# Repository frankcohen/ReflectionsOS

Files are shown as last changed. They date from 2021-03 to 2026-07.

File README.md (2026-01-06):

# ReflectionsOS
ESP32 and Arduino-based Internet-enabled watch project and reference architecture to make your own entertaining experiences. [See the software repository](https://github.com/frankcohen/ReflectionsOS/blob/main/src/SRC_readme.md).

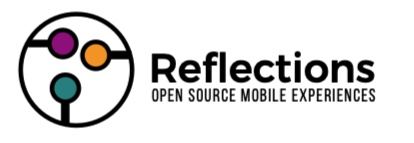
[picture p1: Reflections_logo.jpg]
Reflections Mobile Experiences


Many times I imagine making a mobile application connected to the Internet. For example, a watch that shows videos of my children growing-up on my wrist. And the same project is re-used for creative makers to build their own entertaining experiences. Reflections is the architecture and the wrist watch is the first application.

Reflections integrates video displays, Bluetooth, Wifi, SD flash storage, sound, and a bunch of sensors (compass/magnetometer, gestures, accelerometer, time of flight TOF sensor). It is battery powered, powered managed from software, and charges from USB. It is small in size (34 mm round) and powerful from an ESP32-S3 dual core processor. Reflections software, hardware, and cloud components are open-source (GPL v3) so anyone can use it and they must contribute improvements back to the project.

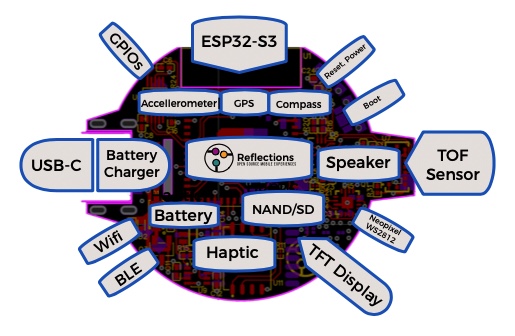
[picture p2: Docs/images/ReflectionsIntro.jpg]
Reflections Mobile Experiences


Reflections goes beyond the wearable device to deliver server side architecture.

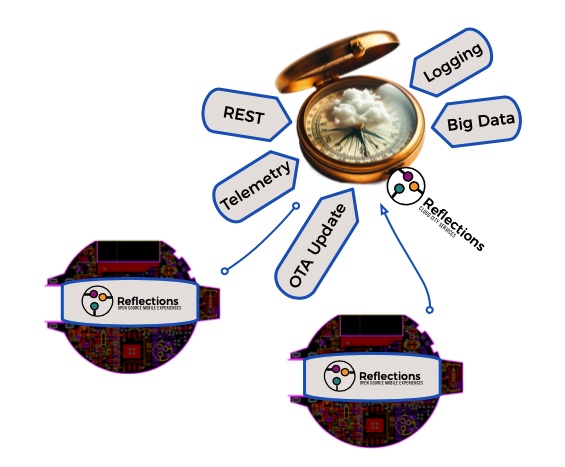
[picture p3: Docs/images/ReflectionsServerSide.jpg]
Reflections Server Side Architecture


I worked on [Starling Watch](http://starlingwatch.com) steampunk art jewelry pocket watches with Disney Imagineer and Muppeteer [Terri Hardin](https://terrihardin.com/). In November 2025 we announced the first commercial product based on Reflections. It's Terri Hardin's Cheshire Cat. Details and purchase at [StarlingWatch.com](https://starlingwatch.com/).

Announcement video (https://www.youtube.com/watch?v=qcqhzyMLibs)

I love working with a group of creative makers and the Arduino community. Please feel free to let me know your feedback and ideas.

IMAGE ALT TEXT HERE (https://www.youtube.com/watch?v=HIWHx4NLKUU)

[JoJo](https://github.com/frankcohen/ReflectionsOS/blob/main/Devices/JoJo/JoJo%20Project%20Notes.md) is the latest version of the Reflections main board. Everything fits into a wrist watch case and I actually wear it on my wrist! Plus the [software]() to drive experiences (codename ReflectionsOS) is coming along nicely. See https://github.com/frankcohen/ReflectionsOS/tree/main/Experiments for experiments with the board.

VladPlus Gerber files and schematic are at:
[https://github.com/frankcohen/ReflectionsOS/blob/main/Devices/VladPlus/VladPlus%20Project%20Notes.md](https://github.com/frankcohen/ReflectionsOS/blob/main/Devices/VladPlus/VladPlus%20Project%20Notes.md)

Frank Cohen, [https://github.com/frankcohen/ReflectionsOS](https://github.com/frankcohen/ReflectionsOS), November 9, 2024

## Articles

I publish articles on the technology needed to make Reflections.

[AccelerometerLab open-source project for LIS3DH 3 Axis accelerometer sensor](https://github.com/frankcohen/ReflectionsOS/tree/main/Experiments/AccelerometerLab)

[ESP32-S3 partition tables and optimizing memory for Arduino IDE 2.x](https://github.com/frankcohen/ReflectionsOS/blob/main/Docs/Partition%20tables%20and%20optimizing%20memory%20in%20Arduino%20IDE.md)

[Deep Sleep, Extending Battery Life for ESP32-S3 Projects](https://github.com/frankcohen/ReflectionsOS/tree/main/Experiments/Deep%20Sleep)

[Wrist Gesture Sensing on ESP32 and Accelerometer](https://github.com/frankcohen/ReflectionsOS/blob/main/Experiments/Gesture_Sensing_Accelerometer/Gesture_Sensing_Experiment.md)

[Scalable Logger on ESP32 with Wifi and SD/NAND](https://github.com/frankcohen/ReflectionsOS/blob/main/Docs/Scalable%20logger.md)

[Arduino and BLE on ESP32 as server and client combined, using NimBLE](https://github.com/frankcohen/ReflectionsOS/blob/main/Docs/Why%20I%20like%20NimBLE%20for%20Bluetooth%20BLE.md)

[JCUSB for JTAG debugging in Arduino IDE 2.1](https://github.com/frankcohen/ReflectionsOS/blob/main/Docs/JCUSB%20using%20JTAG%2C%20CDC%2C%20USB%20for%20debugging.md)

[ESP32-S3 + NAND SD Storage + USB MSCC = Arduino that shows up like a disk drive](https://github.com/frankcohen/ReflectionsOS/blob/main/Docs/Arduino%20that%20shows%20up%20like%20a%20disk%20drive%20_%20arduino.pdf)

[JSON Procedural Scripting using ArduinoJSON and ESP32](https://github.com/frankcohen/ReflectionsOS/blob/main/Docs/JSON%20Procedural%20Scripting%20using%20ArduinoJSON%20and%20ESP32.pdf)

[Managing SSL Certificates for HTTPS with IoT devices, ESP32-nginx+node.js+OTA](https://github.com/frankcohen/ReflectionsOS/blob/main/Docs/Managing%20SSL%20certificates%20for%20HTTPS%20with%20IoT%20devices_%20ESP32%2BNginx%2BNode.js%2BOTA%20_%20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)

[Reference to Mastering ArduinoJSON](https://github.com/frankcohen/ReflectionsOS/blob/main/Docs/Mastering%20ArduinoJSON.pdf)

[Create Using TAR files in ESP32 with SD applications for easy multiple file transfers to Arduino](https://github.com/frankcohen/ReflectionsOS/blob/main/Docs/Using%20TAR%20files%20in%20ESP32%20with%20SD%20applications%20for%20easy%20multiple%20file%20transfers%20_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)

I used the [EleksTube IPS clock](https://elekstube.com/) for experimentation. It is an ESP32 device featuring 6 TFT displays. See [https://github.com/frankcohen/EleksTubeIPSHack](https://github.com/frankcohen/EleksTubeIPSHack)

I made an air-guitar project to learn about streaming music over Bluetooth Clasic, and why it won't work yet on BLE: [https://github.com/frankcohen/ReflectionsOS/tree/main/Experiments/AirGuitar](https://github.com/frankcohen/ReflectionsOS/tree/main/Experiments/AirGuitar)

-Frank

## Update as of June 16, 2025

Nearing the end of coding. The Time of Flight (TOF) sensor and LIS3DH accelerometer sensor code is complete and integrated into the code. Next steps are optimizations to extend battery life, use deep sleep, BLE capabilities, and GPS capabilities.

## Update as of January 18, 2025

I published AccelerometerLab as an open-source project to make working with the LIS3DH 3 Axis accelerometer sensor easier. [The code and article are here.](https://github.com/frankcohen/ReflectionsOS/tree/main/Experiments/AccelerometerLab)

Next up is code to detect gestures with the Time Of Flight (TOF) sensor. This should be fun as it includes machine learning.

## Update as October 29, 2024

I made a fun Magic 8 Ball experience for the Maker Faire Bay Area. It was October 18 to 20, 2024 on Mar Island in the California Bay area and 25,000 people attended.

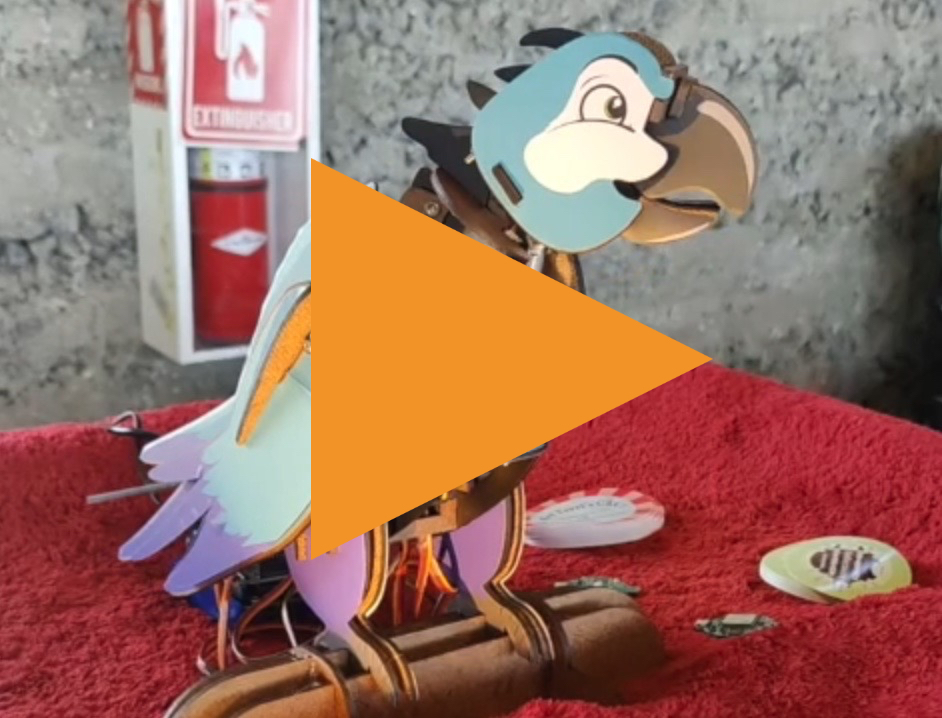
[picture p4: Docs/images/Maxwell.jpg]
Reflections controls Maxwell animatronic at Maker Faire 2024 (https://youtu.be/2h5V32wpsNU)


For Maker Faire I had a Reflections board connect and control Maxwell wirelessly. Ask a question, shake the board and the display shows an answer. Maxwell animates the answer to yes, no, and maybe movements.

Source code for this fun project is in the [/src/MakerFaire2024Maxwell](https://github.com/frankcohen/ReflectionsOS/tree/main/src/MakerFaire2024Maxwell) directory

## Update as of June 18, 2024

We've gotten to a point in the development of the software for the board where we wanted to optimize the board's use of the battery. The battery runs for a few hours now. Using the [Deep Sleep](https://github.com/frankcohen/ReflectionsOS/tree/main/Experiments/Deep%20Sleep) technique for the processor, we're able to make that battery last a whole lot longer. When I tell it to start up, it goes through a cold boot and then it puts the processor to sleep, the processor is now drawing extremely low energy and the display is turned off. It's extending the battery life as well. All I have to do then is to move the, the the board just a little bit and you can see that it comes awake. The accelerometer sensor on the board is sending a interrupt to the processor saying, hey, it's time to wake up the processor, then turns on the display displays this greeting message and then also an indication of how many times through this iteration loop we've gone. And then it sends the processor back into sleep until I shake it again or tap it or click it and then it turns on. So by doing this, we'll be able to get the battery life much longer than we had before we did this. And it's a nice software technique that seems to be useful for a bunch of different applications.

Deep Sleep use of GPIO 13 and LIS3DH INT 2 pins is in the [Vlad version of the logic board](https://github.com/frankcohen/ReflectionsOS/blob/main/Devices/Vlad/Vlad%20Project%20Notes.md) and later.

## Update as of March 19, 2024

Software work achieves success along the way to the ReflectionsOS operating environment. A gesture experiement using the accelerometer works. Watch a 5 minute briefing here:

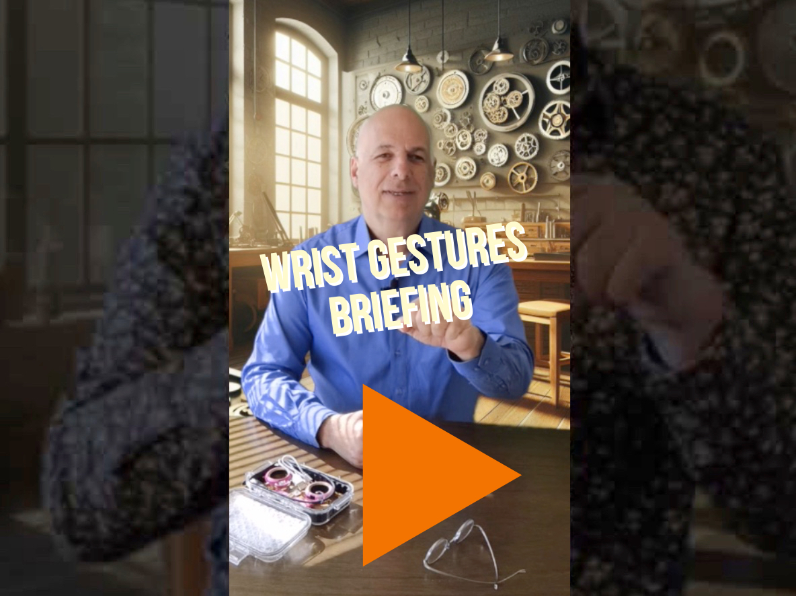
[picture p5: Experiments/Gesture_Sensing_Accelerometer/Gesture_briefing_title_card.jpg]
5 minute video briefing on Wrist Gesture Sensing (https://youtu.be/nNwV_FyjRPc)


[Yertle](https://github.com/frankcohen/ReflectionsOS/blob/main/Devices/Yertle/Yertle%20Project%20Notes.md) arrived and looks fully functional.

## Update as of February 14, 2024

Cat In Hat turned out to be a fools errand, the ESP32-S3 would not boot with the addition of the press-and-hold power on/off capability using U9. Yertle solves this by removing U9. Work on the software continues, should have a simple video player using wrist gestures done soon. Work on the case and strap is in progress. I am only wearing Yertle everyday now, no more traditional watches.

## Update as of December 7, 2023

Work on the [Cat In Hat](https://github.com/frankcohen/ReflectionsOS/tree/main/Devices/CatInHat) main board is nearly complete. This solves a consistency problem with the NAND. And, adds press-and-hold power on/off capability to the Boot button. I depart tomorrow to China to find components and manufacturers for the case and strap. 

## Update as of October 6, 2023

Added Wifi-based [Logger](https://github.com/frankcohen/ReflectionsOS/blob/main/Docs/Scalable%20logger.md). Logs messages to server-side logger. Update board (codenamed Red Fish) to solve U4 LDO problem when battery is attached. Investigated active GPS antennas.

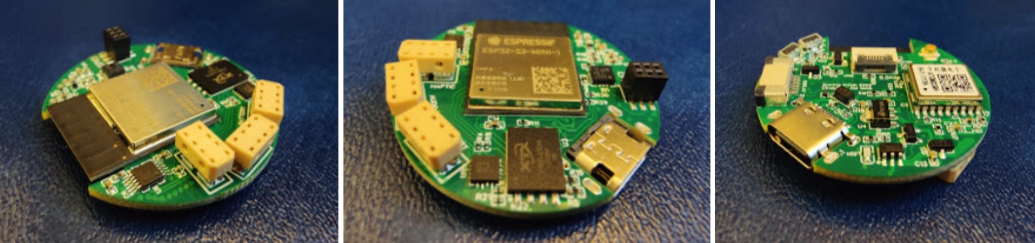
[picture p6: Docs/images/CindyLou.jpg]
Cindy Lou board


## Update as of August 6, 2023

Added Over The Air (OTA) update capabilitiy. Server downloads .bin firmware and a version identifier text file over HTTPS secure protocol. OTA system replaces the current firmware and restarts the host. Thanks to @lipun12ka4 on [Espressif Forums](https://esp32.com/posting.php?f=13&mode=reply&t=30973&sid=89252e0558c707c8813146f40cccf9fc) for sharing his OTA code, a problem, and solution. config.h defines the code's version number, it is a simple integer value. Arduino IDE compiles the firmware. Use FTP to store it in /home/fcohen/files on cloudcity.starlingwatch.com.

## Update as of August 5, 2023

Added [WifiManager](https://github.com/tzapu/WiFiManager) to enable easy connection to a Wifi network. Connect to Reflections board from your laptop or mobile device. The SSID is named CALLIOPE plus the last digits of the device mac address. For example, CALLIOPE-7A. Follow the instructions to log Reflections into your Wifi network. Passwords are sent to the device in the clear, and optionally stored on the device with no encryption. Someone could extract these if they got their hands on your device.

## Update as of August 4, 2023

@dankeboy36 (on Github) published an Arduino stack trace decoding utility. When your sketch crashes a stack trace leading to the crash often appears in the Serial Monitor. Arduino IDE 2.1 does not yet support plug-ins and a decoder utility (available in Arduino IDE 1.8) is needed to explain the stack trace contents. @dankeboy36 created a decoder and it works great. It requires the nightly Arduino IDE build available at https://www.arduino.cc/en/software. The decoder is at at:
https://github.com/dankeboy36/esp-exception-decoder. On a Mac use Command-Shift-P and type ESP Exception Decoder: Show Decoder Terminal.

## Update as of July 18, 2023

A friend asked me: What can the Reflections board do? Consider these possibilities.

- Haptic feedback - a buzzer in the case. Buzzes softly or energetically. Fades the buzzing up, or down, and make patterns. It even does morse code - buzz buzz buzz.

- Long arm movement sensing - Recognizes the direction, speed, and acceleration of your wrist. Recognizes gestures made by moving your wrist in the air. Like sweeping left and right, slow pitching a ball.

- Finger movement sensing - recognizes gestures made with fingers.

- Range, Distance, Heading - when GPS is available, knows its position and direction/heading to other boards. When GPS is not available, such as being indoors, uses a compass and triangulation to detect movement towards or away from other boards using BLE.

- Compass - knows North from South and between.

- Location - when GPS is available, knows when it is in a location. For example, knows when it is at Disneyland and in line for the Matterhorn.

- Bump - touch another board and exchange data.

- USB flash memory - plug into your mobile phone or laptop to store and move files.

- Grab and play - capture video and audio of anything playing on your laptop, displays on the screen.

- [Martians](https://github.com/frankcohen/Martians) - yearn for each other, their hearts point to each other.

- Speaker to play sound and music. However, the speaker volume is very low. A future version needs an audio amplifier.

- Dance movements like pirouette

- Red light green light

- Head and shoulders, knees and toes

I'm glad to update this list with your ideas. Thanks.

## Update as of June 26, 2023:

CindyLou is the latest version of the main board. CindyLou lets me put everything into a wrist watch case and actually wear it on my wrist! Plus the software to drive experiences (codename CalliopeOpensEyes) is coming along nicely. See https://github.com/frankcohen/ReflectionsOS/tree/main/Experiments for experiments with the main board.

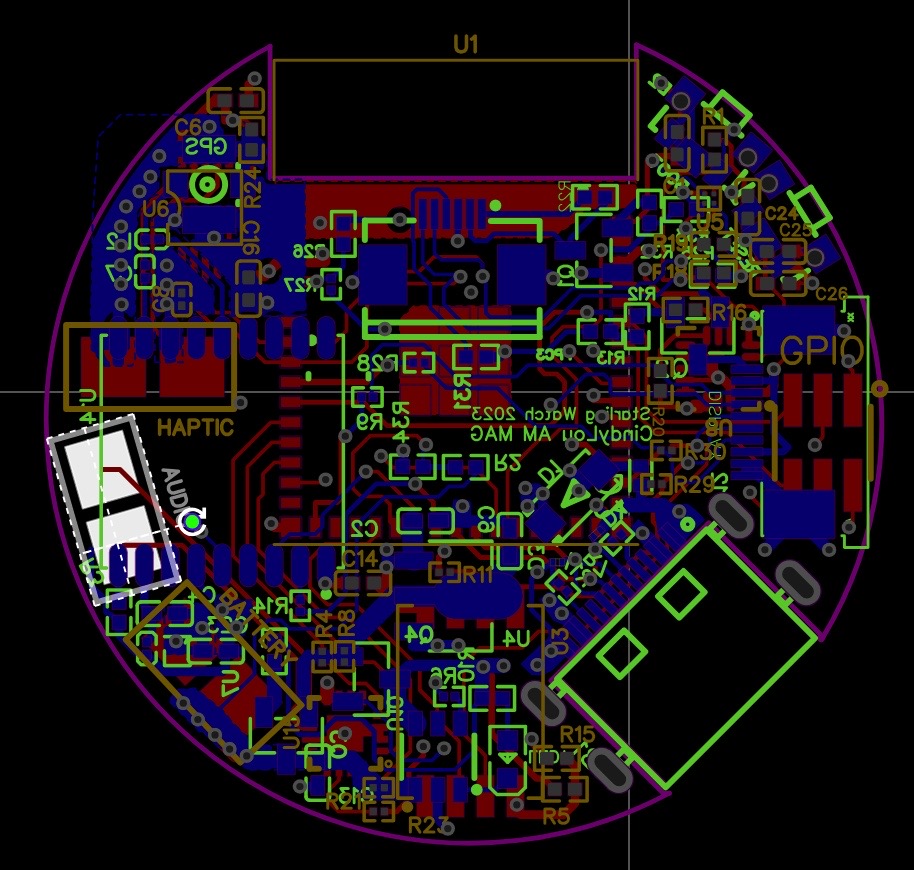
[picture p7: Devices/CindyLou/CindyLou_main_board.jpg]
CindyLou version of the main board CindyLou main board


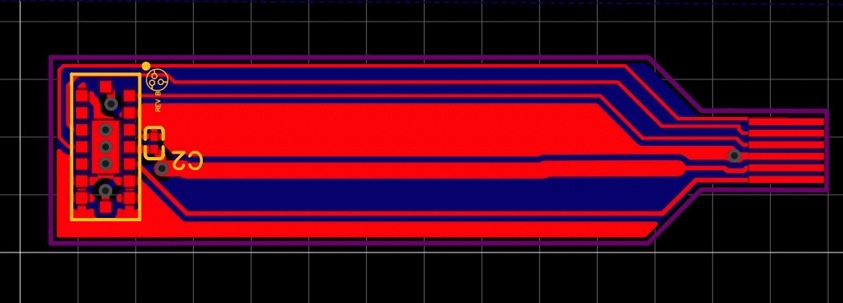
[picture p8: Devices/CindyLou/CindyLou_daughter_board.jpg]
Daughterboard for gesture sensing CindyLou daughter board


CindyLou Gerber files and schematic are at:
https://github.com/frankcohen/ReflectionsOS/tree/main/Devices/CindyLou
EasyEDA project for the previous main board project is at:
https://oshwlab.com/fcohen/horton-main-board

## Update as of April 1, 2023:

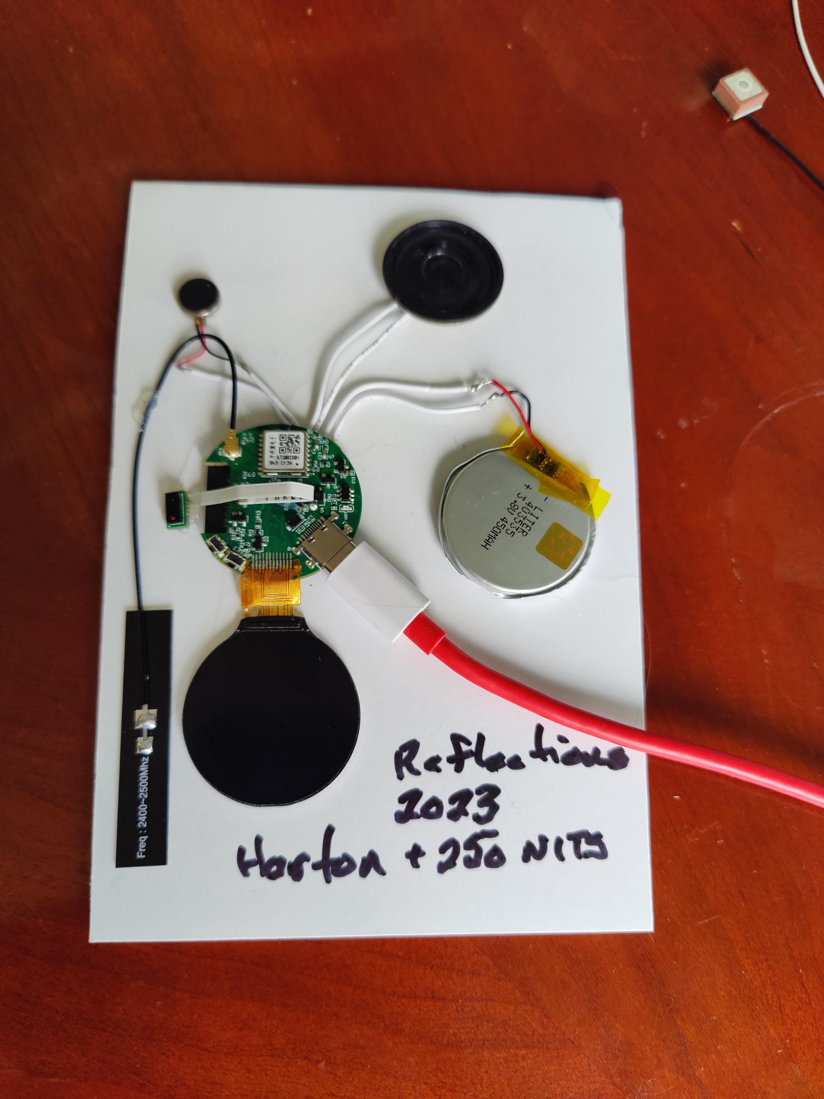
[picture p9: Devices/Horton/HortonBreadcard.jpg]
I call this a Breadcard, it's not a breadboard but getting close to a wearable prototype, codenamed Horton Horton Breadcard


Update as of March 16, 2023:

Horton board is in from assembly and it works great! Next up, our first wearable prototype.
Expect many updates to the source code repository over the coming weeks and months.

## Update as of January 25, 2023:

All of the main board components are working. One more revision of the board is needed to incorporate the reworks we made to the ThingTwo board. We're calling the new revision Horton. It should be complete and go to manufacture and assembly in early February 2023.

The project team attention next goes to producing the first wearable prototype. This will strap to one's wrist, run on battery, and have a prototype display. We are also considering our first crowd funding campaign featuring the prototype. This is leading to an exciting Spring 2023.

## Update as of July 30, 2022:

We're making great progress on the main board, animation, and software projects. Main board revision 2 - codenamed Hoober - works and displays streaming video at 10 Frames Per Second (FPS). Revision 3 - codenamed ThingTwo - is designed and will go to manufacturing and assembly next week. See Devices/ThingTwo for design document, Gerber files, BOM, and wiring guide. Project focus will move to the software projects.

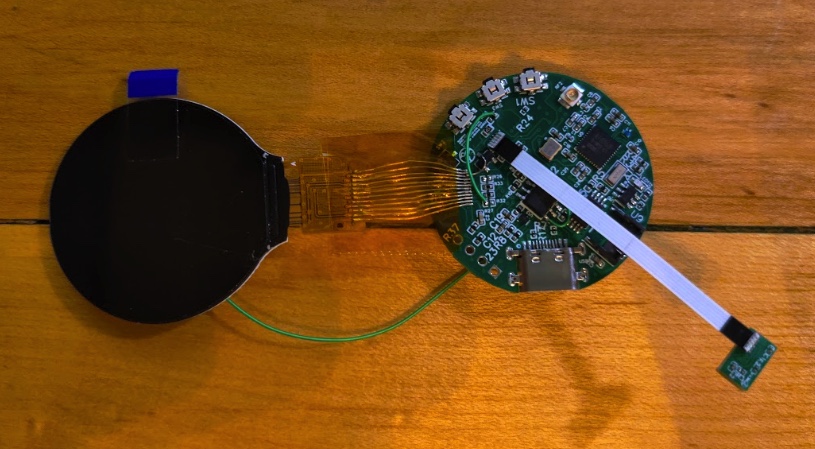
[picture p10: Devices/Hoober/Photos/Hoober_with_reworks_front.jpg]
Photo of the front side of the main board, codenamed Sox Main board front side


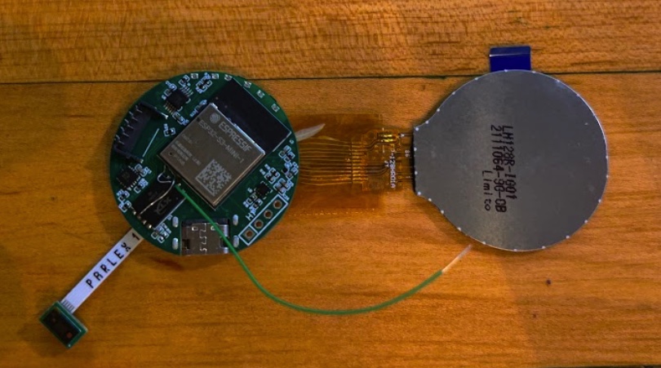
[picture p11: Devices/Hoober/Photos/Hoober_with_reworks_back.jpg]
Photo of the back side of the main board, codenamed Sox Main board back side


## Update as of April 27, 2022:

The project team is making progress on the main board and display. We received the first assembled main board in hand. It’s an ESP32 with GPS, IMU/compass, NAND memory, TFT display, audio output, USB, battery management, and finger gesture sensor, in a 34 mm round board. Cost for the prototype is $70 per board. This first version has about 3-4 problems that need reworking. The team is feeling good that the number of problems is less than 10. That puts us on track to have the finished board in Summer 2022. I will put the Gerber files and BOM into the repository for the upcoming revision 2 - code named Hoober. I am glad to send the Gerber files for your review, criticism, and feedback.

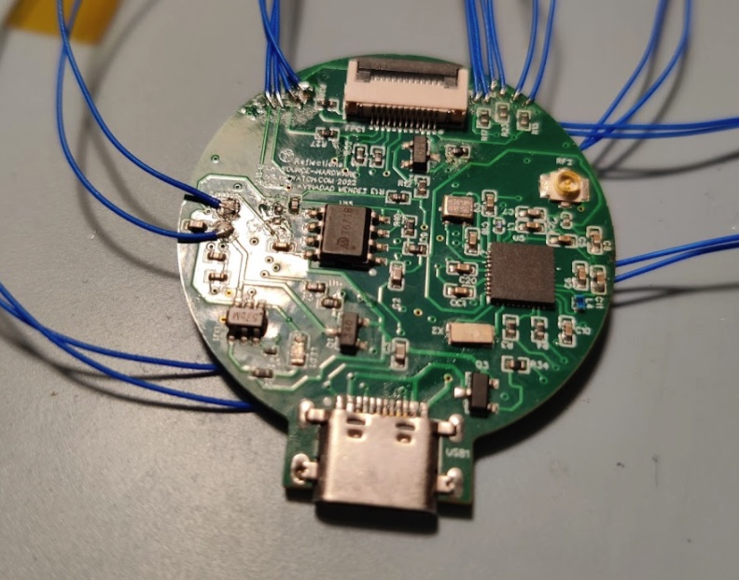
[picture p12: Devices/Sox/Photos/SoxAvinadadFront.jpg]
Photo of the front side of the main board, codenamed Sox Main board front side


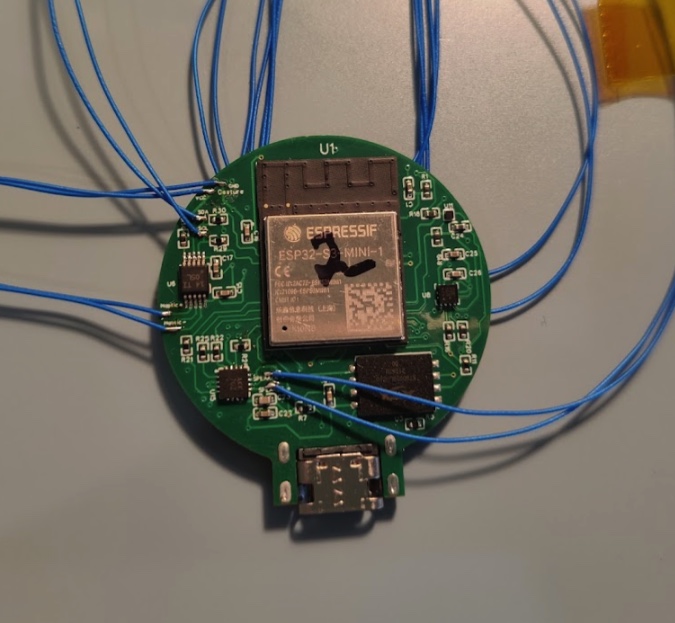
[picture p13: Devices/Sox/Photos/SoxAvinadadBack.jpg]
Photo of the back side of the main board, codenamed Sox Main board back side


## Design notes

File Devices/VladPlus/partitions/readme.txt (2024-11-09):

fcohen@starlingwatch.com, November 9, 2024

Reflections uses a custom partition scheme to maximize available memory.
On MacOS edit this file:
~/Library/Arduino15/packages/esp32/hardware/esp32/3.0.7/tools/partitions/boards.txt
add this:
esp32s3.menu.PartitionScheme.reflections=Reflections App (8MB OTA No SPIFFS)
esp32s3.menu.PartitionScheme.reflections.build.partitions=reflections
esp32s3.menu.PartitionScheme.reflections.upload.maximum_size=3342336   
create this file with these contents:
~/Library/Arduino15/packages/esp32/hardware/esp32/3.0.7/tools/partitions/reflections.csv
# Name, Type, SubType, Offset, Size, Flags
nvs,data,nvs,0x9000,20K,
otadata,data,ota,0xe000,8K,
ota_0,app,ota_0,0x10000,3712K,
ota_1,app,ota_1,0x3b0000,3712K,
eeprom,data,153,0x750000,4K,
spiffs,data,spiffs,0x751000,128K,
coredump,data,coredump,0x771000,64K,
Exit Arduino IDE
Delete ~/Library/Application\ Support/arduino-ide 
Start Arduino IDE
In the Select Board drop-down menu, select ESP32S3 Dev Module
In the Tools menu, select Partition Scheme, then Reflections

Arduino IDE does not input binary encoded partitions. ESP board
definition includes a gen_esp32part.py utility for setting the
correct memory range boundaries. Input is a CSV file with empty 
Offset values. Here is the input for the reflections partition table:

# Name,   Type, SubType, Offset,   Size,       Flags
nvs,      data, nvs,     0x9000,   0x5000,
otadata,  data, ota,     0xe000,   0x2000,
ota_0,    app,  ota_0,   ,         0x3A0000,
ota_1,    app,  ota_1,   ,         0x3A0000,
eeprom,   data, 0x99,    , 		   0x1000
spiffs,   data, spiffs,  ,         0x20000,
coredump, data, coredump,,         0x10000,

Use this command on MacOS Sonoma 14.6.1 (23G93) using Arduino IDE 2.3.3 and ESP32 board definition 3.0,7
python /Users/frankcohen/Downloads/espressif/esp32/tools/gen_esp32part.py --flash-size 8MB /Users/frankcohen/Documents/Arduino/ReflectionsOS/Devices/VladPlus/partitions/reflections-input.csv /Users/frankcohen/Documents/Arduino/ReflectionsOS/Devices/VladPlus/partitions/reflections.bin
The command creates a binary file.

The use this command
python /Users/frankcohen/Downloads/espressif/esp32/tools/gen_esp32part.py --flash-size 8MB /Users/frankcohen/Documents/Arduino/ReflectionsOS/Devices/VladPlus/partitions/reflections.bin /Users/frankcohen/Documents/Arduino/ReflectionsOS/Devices/VladPlus/partitions/reflections.csv

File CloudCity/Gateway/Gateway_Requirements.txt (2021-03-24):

I have this very fun side-job of developing a men's wrist watch. See my previous
invention http://starlingwatch.com/. The wrist watch is a new project. It is
Internet ready and gets its programming from a Cloud based service. It seems to
me that everyone with the wrist watch will also be carrying an Android or iOS
mobile device. My goal is to produce a gateway app that the wrist watch
(an ESP32 using Bluetooth Classic) uses to get the media files from the Cloud.
The media files are binary and are 1 to 40 MB in size. I have a budget to
spend on this. This is part of my Reflections project
https://github.com/frankcohen/ReflectionsOS and your work will be part of my
open source distribution. -Frank Cohen, 2021

Here are the requirements:
Software development of a utility to do binary file transfers from an
Android app to an ESP32 over Bluetooth and stored on an SD card.

ESP32 sketch
Implements the following commands:
1) DownloadFile - identifies a binary file using an 8.3 file name, receives the
file, and streams to the SD card
2) UploadFile - identifies a binary file using an 8.3 file name stored on the
SD card and uploads to the connected Android device.
3) Connect - identifies and connects over Bluetooth to a named device
4) Disconnect - disconnects from a Bluetooth named device
Logs all commands, debug info, and errors to a file on the SD card: /errors.txt
Implements streaming for maximum of 1,024 bytes of ESP32 memory (Malloc) used
Implemented in C or C++, uses Arduino SD library (not SDFat)
https://www.arduino.cc/en/reference/SD

Android app
Launch the app once and it continues to run, serving files to the ESP32 without
user intervention.
Provides a user interface with these elements:
1) Status - connected/disconnected
2) Log - a text area showing a scrollable list of commands being executed,
debug info, and errors
All files send/received are stored in:
File Manager -> Storage -> Internal Storage -> Download
Implements streaming protocol so maximum Android memory used is 1 Mbyte

General requirements
Communicates over Bluetooth Classic or BLE
Does not require security certificates on ESP32 or Android
File transfer in the clear
The files are delivered asynchronously. There is no requirement for
real-time streaming.

Acceptance
All deliverables made by push to https://github.com/frankcohen/ReflectionsOS/gateway
Frank will test the software on Arduino IDE 1.8.13 and an ESP32 Development board
and wiring defined in:
https://github.com/frankcohen/ReflectionsOS/blob/main/Seuss%20Display%20Prototype%20wiring.pdf
and a OnePlus 7 phone running Android 10 and Oxygen OS 10.3.8.GM57AA
Frank must be able to build the Android app from source code on a
laptop running MacOS 11.2.3 or Windows 10
Frank must be able to transfer a 2 Mbyte binary file in 1 minute measured from
the ESP32 SD card
Frank will confirm the file transferred correctly using a CRC checksum

-Frank Cohen, Reflections Project, March 24, 2021

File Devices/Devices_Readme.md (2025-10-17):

# Reflections Devices ReadMe

Started: October 6, 2023

Updated: October 17, 2025

Reflections is a hardware, software, and server architecture for building mobile entertaining experiences. We went through 12 revisions to the board to get to a finished prototype. Each revision is in a sub directory of [Reflections/devices](https://github.com/frankcohen/ReflectionsOS/tree/main/Devices).

- [Sox](https://github.com/frankcohen/ReflectionsOS/tree/main/Devices/Sox) - 1st generation board design
- [Hoober](https://github.com/frankcohen/ReflectionsOS/tree/main/Devices/Hoober) - rev 2, fixes problems
- [ThingTwo](https://github.com/frankcohen/ReflectionsOS/tree/main/Devices/ThingTwo) - rev 3, fixes problems
- [Horton](https://github.com/frankcohen/ReflectionsOS/tree/main/Devices/Horton) - rev 4, ready for software development
- [CindyLou](https://github.com/frankcohen/ReflectionsOS/tree/main/Devices/CindyLou) - rev 5, Beryl brighter display and component connectors
- [RedFish](https://github.com/frankcohen/ReflectionsOS/tree/main/Devices/RedFish) - rev 6, Fixes LDO burn-out problem, battery operated works
- [Blue Fish](https://github.com/frankcohen/ReflectionsOS/tree/main/Devices/BlueFish) - 7th revision, passive GPS antenna support, solder pads instead of connectors, gesture sensor on board, reposition USB and display tab
- [Cat In Hat](https://github.com/frankcohen/ReflectionsOS/tree/main/Devices/CatInHat) - 8th revision, adding press-and-hold power on/off. This failed, turns out the ESP32-S3 doesn't like repurposing the EN pin to provide power on/off capability. Tried changing capacitor and resistor values for the EN circuit in a project codenamed Lorax. That did not work either.
- [Yertle](https://github.com/frankcohen/ReflectionsOS/tree/main/Devices/CatInHat) - 9th revision, removes U9 to abandon the press-and-hold power on/off.
- [Vlad](https://github.com/frankcohen/ReflectionsOS/blob/main/Devices/Vlad/Vlad%20Project%20Notes.md) - 10th revision, adds NAND power control via GPIO pin and LIS3DH accelerometer support for waking the ESP32-S3 from Deep Sleep.
- [VladPlus](https://github.com/frankcohen/ReflectionsOS/blob/main/Devices/VladPlus/VladPlus%20Project%20Notes.md) - 11th revision, replaces U4 with a higher efficiency power converter. The old one heated up when recharging a battery.

- [JoJo](https://github.com/frankcohen/ReflectionsOS/blob/main/Devices/JoJo/JoJo%20Project%20Notes.md) - 12th revision, fixes problems preventing GPS from capturing satellites consistently.

Cindy Lou board example

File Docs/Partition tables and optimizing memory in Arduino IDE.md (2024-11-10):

# ESP32-S3 partition tables and optimizing memory for Arduino IDE 2.x
## November 9, 2024, fcohen@starlingwatch.com

[Espressif](https://espressif.com/) tooling for ESP32 provides many options for managing memory, flash drives (SPIFFS), and Over The Air (OTA) firmware updating. My entry into ESP32 was through Arduino IDE's compatibility. I code in C/C++, debug over JTAG, and package updates for OTA delivery. I like Arduino IDE for it's simplicity, as compared to the powerful capabilities in Espress-IDF, PlatformIO, Intellij, Eclipse, and Visual Studio. Arduino IDE gets complicated to use when wanting to step beyond the default settings. For example, changing the partition tables for memory optimization takes a few steps.

My [Reflections project](https://github.com/frankcohen/ReflectionsOS) is a 34 mm round board for building entertaining mobile experiences. It is an ESP32-S3 with a bunch of sensors, storage, display, and speaker.

I created a custom ESP32 partition scheme to maximize available memory with 8 MB overall, 2 application spaces, OTA, and little or no SPIFFS file storage.

***Note: Members of the Arduino Forums pointed me to an easier solution: Simply name a custom partition file to partitions.csv, copy it into the sketch folder and select custom partition from the tools menu of the Arduino IDE.***

A custom partition file is a comma separated value (CSV) text file. Espressif documents the possible contents well [here](https://docs.espressif.com/projects/esp-idf/en/v5.3.1/esp32s3/api-guides/partition-tables.html). Here is my starting point:

```
# Name,   Type, SubType, Offset,   Size,       Flags
nvs,      data, nvs,     0x9000,   0x5000,
otadata,  data, ota,     0xe000,   0x2000,
ota_0,    app,  ota_0,   ,         0x3A0000,
ota_1,    app,  ota_1,   ,         0x3A0000,
eeprom,   data, 0x99,    , 		   0x1000
spiffs,   data, spiffs,  ,         0x20000,
coredump, data, coredump,,         0x10000,
```

Note I left the offset values empty. Offsets have their own pecular requirements. I found it easier to let the gen_esp32part.py utility provided by Espressif generate the offsets and the final partition file.

Use this command on MacOS Sonoma 14.6.1 (23G93) using Arduino IDE 2.3.3 and ESP32 board definition 3.0.7:

```
python ~/Downloads/espressif/esp32/tools/gen_esp32part.py --flash-size 8MB reflections-input.csv reflections.bin
```

The utility creates a binary file.

Arduino IDE does not input binary encoded partitions. The fun in gen_esp32part.py is using it in both directions. This command converts the binary file into a csv text file:

```
python ~/Downloads/espressif/esp32/tools/gen_esp32part.py --flash-size 8MB reflections-input.csv reflections.bin
```

reflections.csv contains this:

```
# Name, Type, SubType, Offset, Size, Flags
nvs,data,nvs,0x9000,20K,
otadata,data,ota,0xe000,8K,
ota_0,app,ota_0,0x10000,3712K,
ota_1,app,ota_1,0x3b0000,3712K,
eeprom,data,153,0x750000,4K,
spiffs,data,spiffs,0x751000,128K,
coredump,data,coredump,0x771000,64K,
```

Installing a partition to Arduino IDE is a manual effort. Copy the reflections.csv file on MacOS for ESP32-S3 Dev Module 3.0.7 to:

```
~/Library/Arduino15/packages/esp32/hardware/esp32/3.0.7/tools/partitions/reflections.csv
```

Then tell Arduino IDE 2.3.3 where to find the partition by editing this file:

```
~/Library/Arduino15/packages/esp32/hardware/esp32/3.0.7/tools/partitions/boards.txt
```

Reflections is compatible with the ESP32-S3 Dev Module board definition, so add this to boards.txt:

```
esp32s3.menu.PartitionScheme.reflections=Reflections App (8MB OTA No SPIFFS)
esp32s3.menu.PartitionScheme.reflections.build.partitions=reflections
esp32s3.menu.PartitionScheme.reflections.upload.maximum_size=3342336   
```

Next, if Arduino IDE is open, exit it. Then manually delete this directory:

```
~/Library/Application\ Support/arduino-ide
```

Start Arduino IDE

In the Select Board drop-down menu, select ESP32S3 Dev Module

In the Tools menu, select Partition Scheme, then select:

Reflections App (8MB OTA No SPIFFS)

The next time you compile and upload the ESP32-S3 will use the partition values. Set Tools -> Core Debug Level to Verbose and see the custom partition values used in the Serial Monitor as your app starts to run.

```
------------------------------------------
Partitions Info:
------------------------------------------
                nvs : addr: 0x00009000, size:    20.0 KB, type: DATA, subtype: NVS
            otadata : addr: 0x0000E000, size:     8.0 KB, type: DATA, subtype: OTA
              ota_0 : addr: 0x00010000, size:  3712.0 KB, type:  APP, subtype: OTA_0
              ota_1 : addr: 0x003B0000, size:  3712.0 KB, type:  APP, subtype: OTA_1
             eeprom : addr: 0x00750000, size:     4.0 KB, type: DATA, subtype: 0x99
             spiffs : addr: 0x00751000, size:   128.0 KB, type: DATA, subtype: SPIFFS
           coredump : addr: 0x00771000, size:    64.0 KB, type: DATA, subtype: COREDUMP
```
		   
Please let me know your experience. I want to make sure these instructions are accurate and wise. Thanks.

-Frank

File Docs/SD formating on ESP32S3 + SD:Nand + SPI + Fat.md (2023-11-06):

# ESP32-S3 SPI Nand/SD SdFat Format for Fat16 recipe

by Frank Cohen, November 2, 2023, part of the [Reflections](https://github.com/frankcohen/ReflectionsOS) open-source project

## A Recipe

SdFat is an amazing open-source library for Arduino and ESP32 projects to use SD and Nand storage. It's been around since 2009. @greiman does an amazing job, even if SdFat is impossible to maintain. This is my contribution, a recipe for fellow ESP32 enthusiasts needing to format an SD for Fat16 over SPI. I wrote it for my [Reflections](https://github.com/frankcohen/ReflectionsOS) open-source project. It uses an ESP32-S3 and Nand/SD.

### Install SdFat

I used SdFat version 2.2.2. Open the Library Manager in Arduino IDE 2.2.1.

### SdFatConfig.h Configuration

Make these changes to:

arduino/libraries/SdFat/src/SdFatConfig.h

Find this definition, change its value to 3

```
#define SPI_DRIVER_SELECT 3
```

### Schematic

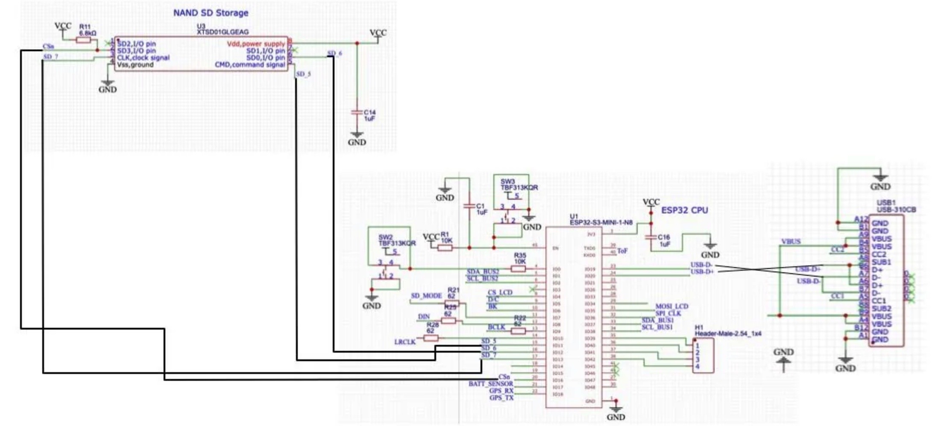
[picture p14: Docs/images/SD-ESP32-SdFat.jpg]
SD attaches to ESP32 over SPI


### Sketch

Refer to the code 
[https://github.com/frankcohen/ReflectionsOS/Experiments/SdFat_ESP32_SPI_SD_NAND_Formatting](https://github.com/frankcohen/ReflectionsOS/tree/main/Experiments/SdFat_ESP32_SPI_SD_NAND_Formatting)

GPIO 12 is the chip-select for a TFT video display on the same SPI bus as the SD/Nand. This tells SdFat to disable it.
```
const int8_t DISABLE_CS_PIN = 12;
```

GPIO 15 is the chip-select for the SD/Nand.
```
#define SD_CS_PIN 15
```

ESP32 allows any GPIO pins to be an SPI bus. See [Andreas Speiss video and spreadsheet](https://www.youtube.com/watch?v=LY-1DHTxRAk) to know the limitations. Reflection's board uses 35, 36, 37 for SPI between the SD/Nand and Display.
```
#define SPI_MOSI      35
#define SPI_MISO      37
#define SPI_SCK       36
```

Additional GPIO pins used by the Reflections board display.
```
#define Display_SPI_DC    5
#define Display_SPI_CS    12
#define Display_SPI_RST   0
#define Display_SPI_BK    6
```

Custom SPI connection class, begin method starts the SPI bus using the GPIO pins.
```
class MySpiClass : public SdSpiBaseClass {
...
SPI.begin(SPI_SCK, SPI_MISO, SPI_MOSI, -1);
...
```

SdFat sets SPI bus speed with the SD_SCK_MHZ macro. 50 works for my ESP32-S3-Mini-N1. I have found no clear method of determining the speed for a given board and SD/Nand component. Try lesser values. For example, 30, 20, 10.
```
#define SD_CONFIG SdSpiConfig(SD_CS_PIN, DEDICATED_SPI, SD_SCK_MHZ(50), &mySpi)
```

Sets the GPIO pins that support the SD/Nand and the display. These are specific to the [Reflections](https://github.com/frankcohen/ReflectionsOS) board and you may change them for your board.
```
  pinMode(SD_CS_PIN, OUTPUT );
  digitalWrite(SD_CS_PIN, LOW);

  pinMode(Display_SPI_CS, OUTPUT);
  digitalWrite(Display_SPI_CS, LOW);

  pinMode(Display_SPI_DC, OUTPUT);
  digitalWrite(Display_SPI_DC, HIGH);

  pinMode(Display_SPI_RST, OUTPUT);
  digitalWrite(Display_SPI_RST, HIGH);

  pinMode(Display_SPI_BK, OUTPUT);
  digitalWrite(Display_SPI_BK, LOW);
```

## Arduino IDE 2.x settings

Using Arduino IDE 2.x, use Tools menu options:

```
Board: ESP32S3 Dev Module
USB CDC On Boot: Enabled
Core Debug Level: Error
USB DFU On Boot: Disabled
Erase All Flash Before Sketch Upload: Disabled
Events Run On: Core 1
Flash Mode: QIO 80 Mhz
Flash Size: 8 MB (64MB)
JTAG Adapter: Integrated USB JTAG
Arduino Runs On: Core 1
USB Firmware MSC On Boot: Disabled
Partition Scheme: Defaults 4MB with Spiffs (1.2 MB APP/1.5MB SPIFFS)
PSRAM: Disabled
Upload Mode: UART0/Hardware CDC
Upload Speed 921600
USB Mode: Hardware CDC and JTAG
```

## JCUSB, USB, JTAG Debugging, Connection

Connect your computer to an ESP32-S3 using a technique I call [JCUSB](https://github.com/frankcohen/ReflectionsOS/blob/main/Docs/JCUSB%20using%20JTAG%2C%20CDC%2C%20USB%20for%20debugging.md). JCUSB is short for S3 + USB + CDC + OpenOCD + Arduino IDE. Only ESP32-S3 and its successors support JCUSB - it won't work on ESP32 and ESP32-S2. JCUSB uses a custom USB cable to connect an ESP32 to a Windows or MacOS computer. [Details here](https://github.com/frankcohen/ReflectionsOS/blob/main/Docs/JCUSB%20using%20JTAG%2C%20CDC%2C%20USB%20for%20debugging.md)

# Compile and Run

Once you customize the above values, compile and upload the code. Then open the Serial Monitor, set the connection speeed to 115200, follow the on-screen instructions.

Here is an example. I ran this on my MacOS laptop using Arduino IDE 2.2.1.

```
SdFat version: 2.2.2

Disabling SPI device on pin 12

Assuming the SD chip select pin is: 15
Edit SD_CS_PIN to change the SD chip select pin.
Done

type any character to start
```

## What May Go Wrong

SdFat works with a lot of hardware and SD cards, and it is possible it will not work with yours.

- SPI bus speed. SdFat sets SPI bus speed with the SD_SCK_MHZ macro. 50 works for my ESP32-S3-Mini-N1. I have found no clear method of determining the speed for a given board and SD/Nand component. Try lesser values. For example, 30, 20, 10.

- SD card won't format. Usually because it is broken. Or maybe partially zapped from static electricity. Or it is a low quality SD card that works inconsistently.

- Conflicts with the board definitions. Check the pin use on your board.

In the event something goes wrong, SdFat's creator/maintainer does an amazing job at interacting with his community. I recommend you search the [issues](https://github.com/greiman/SdFat/issues), and if you need to post an issue.

--

Frank Cohen, 2023
[Reflections Project](https://github.com/frankcohen/ReflectionsOS)

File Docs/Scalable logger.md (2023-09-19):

# Scalable logger ESP32 + Wifi + SD/NAND for multiple devices

I wrote a logger. It runs on an ESP32-S3, stores the log values on local storage temporarily, and sends the log values over Wifi to a service for storage and anlysis. My goal is to have an unlimited number of log entries. I do not want to bog-down the ESP32 as it stores and uploads the logs. I plan to have hundreds or thousands of devices logging concurrently. And it works even when Wifi service is not available, following a store-and-forward pattern.

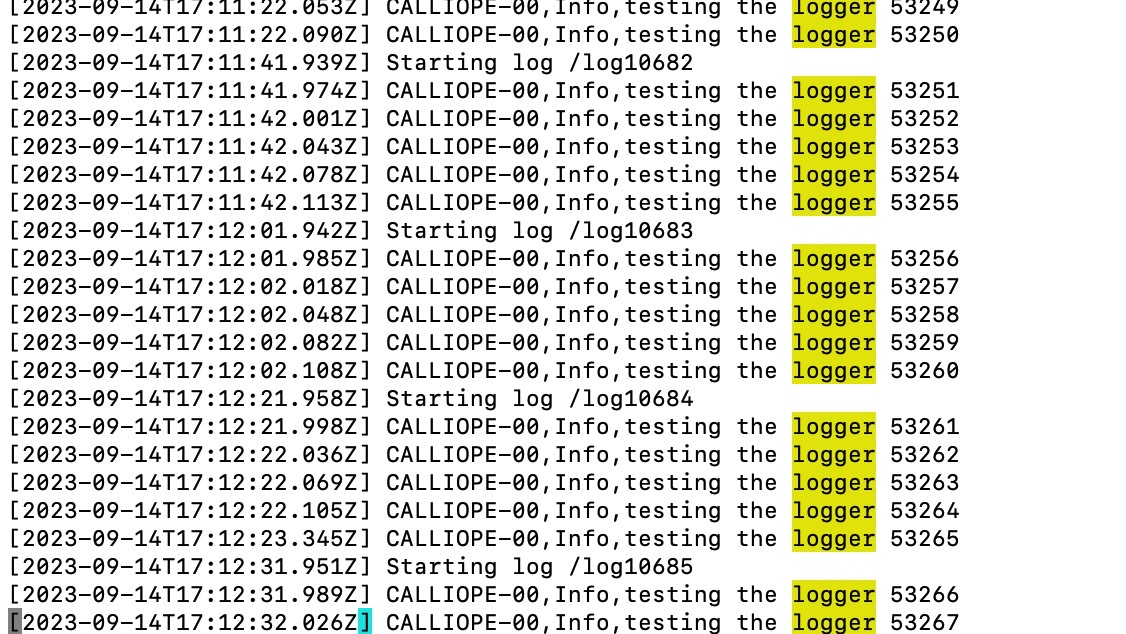
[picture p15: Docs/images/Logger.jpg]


The logger receives String values, saves them to a log file on an SD/NAND device. [NAND](https://www.lcsc.com/product-detail/NAND-FLASH_XTX-XTSD01GLGEAG_C558837.html) is a surface mount version of an SD card. The logger keeps logging to the file until the file size hits 200 bytes (200 is for testing, the NAND has 8 Gbytes of storage). The logger then closes the file and starts logging to a new log file. A separately running service finds the previous log files and sends the log contents to a Web-based service. The service stores the log data in a MongoDB collection. The logger deletes log files after it completes sending them to the service.

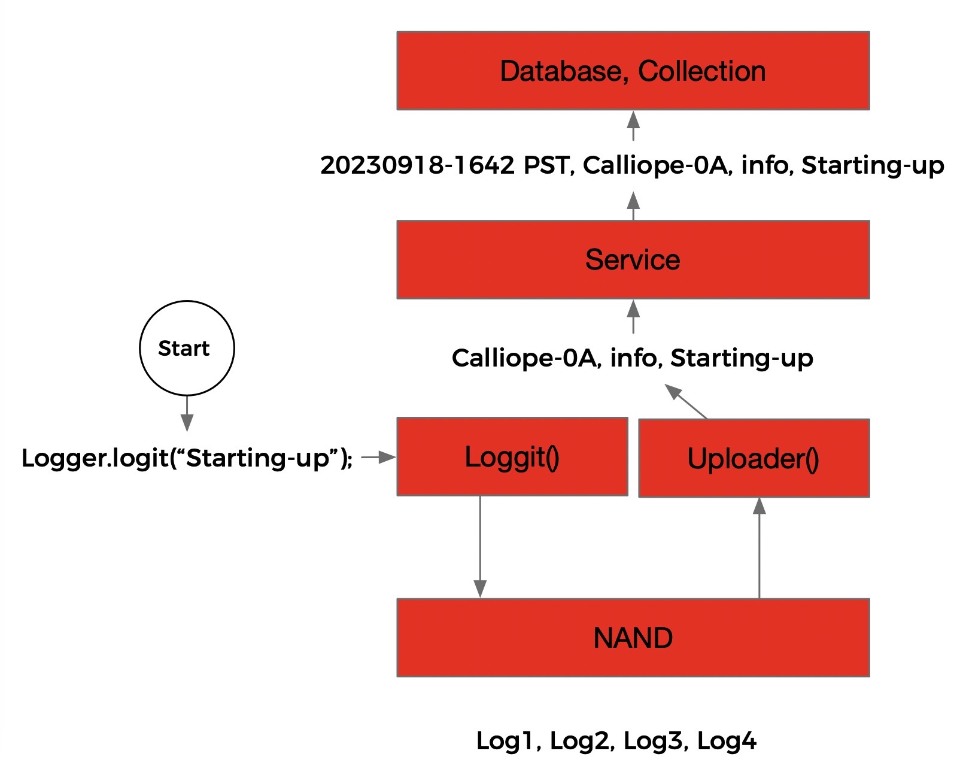
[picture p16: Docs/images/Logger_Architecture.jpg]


This article covers the client-side logger code. It makes HTTP GET requests as described below. The server side components log to local log files, and optionally to a MongoDB collection.

## Log levels

Logger implements 4 levels of logs: info, warning, error, and critical. Call these methods to put a message into the log.

```
void info( String message );
void warning( String message );
void error( String message );
void critical( String message );
```

For example, logger.info( "My log message" ); and the log appears as
```
device-name, info, My log message
```

## Log files

Logger creates log files with the name 'log' at the root level of the SD/NAND. For example, log1, log2, log3, and more. Logger creates the next log file after it stores 200 or more bytes of log data. Adjust the size for your project, any size will do.

## Web-based API service

Logger's upload service runs every 20 seconds. It finds the log file with the lowest log number. It uses HTTPclient to make a GET request to the Web server in this format:

```
https://server.com?message=the%2Alog%2Amessage
```

Logger URL encodes the message field before sending it to the server. Logger adds a unique device identifier to the message. It uses the name of the device from a #define statement appended with the final 2 digits of the ESP32 MAC address. For example, CALLIOPE-8F, info, the log message.

By default Logger uses HTTPS protocols. The root server certificate must be made available for HTTPclient to make a connection. Logger expects to find the certificate in a secrets.h file. Set the file using: 

```
#include "secrets.h"
extern const char* root_ca;   // Defined in secrets.h
```

## Using logger in Arduino sketches and C++ files

Here is an examaple Arduino sketch using logger.

```
#include "Logger.h"

setup() {
  logger.begin();
}

loop() {
  logger.info( "My log message" );
}
```

## Bugs

While working on the logger I found two bugs in the ESP32. When the logger initially opens a new log file the SD library size() method returns garbage values. Once I write some data to the log f ile size() returns the correct value. This is [Bug Report 8625](https://github.com/espressif/arduino-esp32/issues/8625#issuecomment-1715236171) for Espressif for the ESP32.

The second issues happens when using the HTTPclient library. If the code does not use the end() method after making an HTTP GET request to the Web service, then HTTPclient causes the SD library to stop writing data to the SD/NAND device. The File object write() method returns a value equal to the number of bytes you asked it to write, yet the file size remains the same as though the write never happened. Using the HTTPclient end() method solves this problem.

## How you may help

Any help with this would be great of you and appreciated, including criticisms of the design and refactoring ideas. I'm open to all.

This is from my Reflections open-source project at https://github.com/frankcohen/ReflectionsOS. 

-Frank Cohen (fcohen@starlingwatch.com)

Source code:

***Logger.h***

```
#ifndef _LOGGER_
#define _LOGGER_

#include "config.h"
#include "secrets.h"

#include "Arduino.h"
#include "HTTPClient.h"
#include <WiFi.h>
#include "FS.h"
#include "SD.h"
#include "SPI.h"

#include <UrlEncode.h>

#define log_size_upload 500

#define maxlogmsg 300

class LOGGER
{
  public:
    LOGGER();
    void begin();
    void loop();

    void info( String message );
    void warning( String message );
    void error( String message );
    void critical( String message );
    void clearLog( String logname );
    bool scanLogNumbers();

  private:
    void logit( String msg );
    bool setActiveFile( int atvnum );
    bool sendToServer( String message );

    int lowLogNumber;
    int highLogNumber;

    File mylog;
    File lognext;
    bool mylogopen;
    String mylogname;
    long mylogtime;

    std::string devname;
    String devicename;

    File myupload;
    String uploadfilename;
    bool myuploadopen;
    bool uploading;
    long uploadchecktime;
    long uploadcount;

    HTTPClient http;

    bool forceit;
    int forcecount;

};

#endif // _LOGGER_
```

*** Logger.cpp***
```
/*
 Reflections, mobile connected entertainment device

 Repository is at https://github.com/frankcohen/ReflectionsOS
 Includes board wiring directions, server side components, examples, support

 Licensed under GPL v3 Open Source Software
 (c) Frank Cohen, All rights reserved. fcohen@starlingwatch.com
 Read the license in the license.txt file that comes with this code.

 Depends on:
 https://github.com/plageoj/urlencode

Example log entry:
CALLIOPE-7A,Logger started correctly
then the node.js function adds the date
20230808-11:45AM,CALLIOPE-7A,Logger started correctly

Implemented the log receiver service in node.js using:
// GET to make a log entry
var timestamp = require('log-timestamp');
router.get( "/logit", (req, res) => {
  console.log( req.query.message );
  res.send( "<html><body>Logged</body></html>" );
}); 

requires timestamp module, install using:
npm install log-timestamp

Example,
https://cloudcity.starlingwatch.com/api/logit?message=thisismyfirstlogentry5

*/

#include "LOGGER.h"

extern const char* root_ca;   // Defined in secrets.h

LOGGER::LOGGER(){}

void LOGGER::info( String message )
{
  String lm = "Info,";
  lm += message;
  logit( lm );
}

void LOGGER::warning( String message )
{
  String lm = "Warning,";
  lm += message;
  logit( lm );
}

void LOGGER::error( String message )
{
  String lm = "Error,";
  lm += message;
  logit( lm );
}

void LOGGER::critical( String message)
{
  String lm = "Critical,";
  lm += message;
  logit( lm );
}

/*
* Adds host name and sends to active file
*/

void LOGGER::logit( String msg )
{
  if ( mylogopen != 1 )
  {
    Serial.println( "Not logging, mylog is not open" );
    return;    
  }
 
  String logmsg = devname.c_str();
  logmsg += ",";
  logmsg += msg;
  logmsg += "\n";

  long mysize = (long) mylog.size();

  int logval = mylog.print( logmsg );
  mylog.flush();

  Serial.print( "Logged to " );
  Serial.print( mylogname );
  Serial.print( ", written = ");
  Serial.print( logval );
  Serial.print( ", characters " );
  Serial.print( logmsg.length() );
  Serial.print( ", file size before " );
  Serial.print( mysize );
  Serial.print( ", file size after " );
  Serial.print( mylog.size() );
  if ( mylog.size() == mysize + logmsg.length() )
  {
    Serial.print( F( ", forcecount = " ) );
    Serial.print( forcecount );
    Serial.println( F( " OK" ));
        
    forceit = 1;
  }
  else
  {
    Serial.println( ", FAIL" );

    Serial.println( F("Forcing to new log file, forecount = " ) );
    Serial.println( forcecount++ );
    forceit = 0;
  }

  if ( forceit )
  {
    forceit = 1;

    if ( mylog.size() < log_size_upload ) return;

    if ( ! scanLogNumbers() ) return;
  }

  mylog.close();
  mylogopen = 0;

  String elname = logname_start;
  elname += String( highLogNumber + 1 );
  
  lognext = SD.open( elname, FILE_WRITE );
  if( !lognext )
  {
    Serial.print( F( "Unable to create log file " ) );
    Serial.println( elname );
  }    
  
  mylog = lognext;
  mylogname = elname;
  mylogopen = 1;
  
  Serial.print( F( "Opened log file " ) );
  Serial.print( mylogname );
  Serial.print( ", mylog.size() = " );
  Serial.println( (long) mylog.size() );

  // I need to write something to the log file here
  // because the Espressif SD library returns a random
  // value for mylog.size() before something is
  // written to the log file.

  mylog.print( devname.c_str() );
  mylog.print( ",Info," );
  mylog.print( "Starting log " );
  mylog.print( mylogname );
  mylog.print( "\n" );
  mylog.flush();
}

/*
* Sends message to the server over HTTPS GET protocol
*/

bool LOGGER::sendToServer( String message )
{
  Serial.print( "sendToServer: ");
  Serial.println( message );

  String logurl = cloudCityLogURL;
  logurl += urlEncode( message );

  http.begin( logurl, root_ca );
  http.setReuse(true);

  int httpCode = http.GET();

  if( httpCode != HTTP_CODE_OK )
  {
    Serial.print( F( "Server response code: " ) );
    Serial.println( httpCode );
    return false;
  }

  http.end();

  return true;
}

bool LOGGER::scanLogNumbers()
{
  lowLogNumber = 1000000;
  highLogNumber = 0;

  File root = SD.open( "/" );
  if( !root ){
      Serial.println( F( "scanLogNumbers failed to open directory /" ) );
      return false;
  }

  while ( 1 )
  {
    File file = root.openNextFile();
    if ( file )
    {
      if ( ! file.isDirectory() )
      {
        String myfilename = file.name();

        if ( myfilename.startsWith( "log" ) )
        {
          String mynum = myfilename.substring( 3 );
          int mynumbr = mynum.toInt();

          if ( mynumbr < lowLogNumber )
          {
            lowLogNumber = mynumbr;
          }

          if ( mynumbr > highLogNumber )
          {
            highLogNumber = mynumbr;
          }
        }
      }
    }
    else
    {
      break;
    }
  }

  return true;
}

/*
* Begin picks-up the state from where we left off (from the file system)
* or creates the initial state (and file system logs)
*/

void LOGGER::begin()
{
  Serial.println( "Logger begin");

  root_ca = ssl_cert;   // Defined in secrets.h

  mylogopen = 0;
  myuploadopen = 0;
  uploading = 0;
  uploadcount = 0;
  forceit = 0;
  forcecount = 0;

  devname = host_name_me;
  std::string mac = WiFi.macAddress().c_str();
  devname.append( mac.substr( 15, 2 ) );
  devicename = devname.c_str();

  // Open a new log file

  if ( ! scanLogNumbers() ) return;

  mylogname = logname_start;
  mylogname += String( highLogNumber + 1 );
  
  mylog = SD.open( mylogname, FILE_WRITE );
  if( !mylog )
  {
    Serial.print( F( "Unable to create log file " ) );
    Serial.println( mylog );
  }    
  
  mylogopen = 1;
  
  Serial.print( F( "Opened log file " ) );
  Serial.println( mylogname );

  uploadchecktime = millis();

  Serial.println( "Logger begin done");
}

void LOGGER::loop()
{

  if ( ( ( millis() - uploadchecktime ) > 10000 ) )
  {
    uploadchecktime = millis();
    
    Serial.println( "Checking for upload" );

    if ( !uploading )
    {

      if ( scanLogNumbers() )
      {
        uploadfilename = logname_start;
        uploadfilename += String( lowLogNumber );

        if ( ( mylogopen ) && ( uploadfilename.equals( mylogname ) ) )
        {
          Serial.print( F( "Skipping log file because it is open " ) );
          Serial.println( uploadfilename );
        }
        else
        {
          myupload = SD.open( uploadfilename );
          if( !myupload )
          {
            Serial.print( F( "Unable to open upload file " ) );
            Serial.println( uploadfilename );
            myuploadopen = 1;
            uploadcount = 0;
            uploading = 0;
          }
          else
          {
            uploading = 1;
            myuploadopen = 1;
            uploadcount = 0;
            
            Serial.print( F( "Opened upload file " ) );
            Serial.println( uploadfilename );
          }
        }
      }
    }
    else
    {
      Serial.println( F( "We're uploading, so I'm fine." ) );
    }
  }

  if ( uploading )
  {
    long avail = myupload.available();

    if ( avail > 0 )
    {
      char line[250];
      char fchr;

      int i=0;
      while ( i < 249 )
      {
        fchr = myupload.read();
        if ( fchr == '\n' ) break;
        line[i] = fchr;
        i++;
      }
      line[ i ] = 0;

      String mys = line;

      sendToServer( mys );
      uploadcount++;
    }
    else
    {
      Serial.print( "Uploading complete, log sent to service " );
      Serial.println( uploadcount );

      myupload.close();
      myuploadopen = 0;
      SD.remove( uploadfilename );
      uploading = 0;
    }
  }
}
```

## Find the latest update

The latest update is in the source code repository at [https://github.com/frankcohen/ReflectionsOS/blob/main/Docs/Scalable%20logger.md](https://github.com/frankcohen/ReflectionsOS/blob/main/Docs/Scalable%20logger.md)

Article published and comments at:
[https://www.reddit.com/r/esp32/comments/16mj3zh/scalable_logger_esp32_wifi_sdnand_for_multiple/](https://www.reddit.com/r/esp32/comments/16mj3zh/scalable_logger_esp32_wifi_sdnand_for_multiple/)

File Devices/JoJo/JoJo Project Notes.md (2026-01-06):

# JoJo project notes, Reflections

Started: October 1, 2025

Updated: January 5, 2026

JoJo is the 12th revision of the Reflections main board. 
It is the successor to Vlad Plus, Vlad, Yertle, Cat In Hat, BlueFish, RedFish, CindyLou, Horton, ThingTwo, Hoober, Knox and Sox. JoJo fixes problems preventing GPS from capturing satellites consistently.

- Sox - 1st generation board design
- Hoober - rev 2, fixes problems
- ThingTwo - rev 3, fixes problems
- Horton - rev 4, ready for software development
- CindyLou - rev 5, Beryl brighter display and component connectors
- RedFish - rev 6, Fixes LDO burn-out problem
- BlueFish - rev 7, Puts gesture sensor onto main board, moves USB port
- CatInHat - rev 8, Adds press-and-hold power on/off, removed in Yertle
- Yertle - rev 9, Removes press-and-hold power, adds Nand software power control
- Vlad - rev 10, Enables the accelerometer to wake the processor from sleep
- Vlad Plus - rev 11, Solves heating problems
- JoJo - rev 12, fixes problems preventing GPS from capturing satellites consistently.

Find the Horton board project
https://github.com/frankcohen/ReflectionsOS/tree/main/Devices/Horton

Find the CindyLou board project
https://github.com/frankcohen/ReflectionsOS/tree/main/Devices/CindyLou

Find the RedFish board project
https://github.com/frankcohen/ReflectionsOS/tree/main/Devices/RedFish

Find the BlueFish board project
https://github.com/frankcohen/ReflectionsOS/tree/main/Devices/BlueFish

Find the Cat In Hat board project
https://github.com/frankcohen/ReflectionsOS/tree/main/Devices/CatInHat

Find the Yertle board project
https://github.com/frankcohen/ReflectionsOS/tree/main/Devices/Yertle

Find the Vlad board project
https://github.com/frankcohen/ReflectionsOS/tree/main/Devices/Vlad

Find the Vlad Plus board project
https://github.com/frankcohen/ReflectionsOS/tree/main/Devices/VladPlus

## What went wrong in VladPlus

GPS module is inconsistent at capturing satellites.

## JoJo Requirements

Fix module and circuit path traces to solve antenna issues.

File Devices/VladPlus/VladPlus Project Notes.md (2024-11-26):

# VladPlus project notes, Reflections

Started: June 15, 2024

Updated: October 29, 2024

VladPlus is the 11th revision of the Reflections main board. 
It is the successor to Vlad, Yertle, Cat In Hat, BlueFish, RedFish, CindyLou, Horton, ThingTwo, Hoober, Knox and Sox. Replaces U4 with a higher efficiency power converter. The old one heated up when recharging the battery.

- Sox - 1st generation board design
- Hoober - rev 2, fixes problems
- ThingTwo - rev 3, fixes problems
- Horton - rev 4, ready for software development
- CindyLou - rev 5, Beryl brighter display and component connectors
- RedFish - rev 6, Fixes LDO burn-out problem
- BlueFish - rev 7, Puts gesture sensor onto main board, moves USB port
- CatInHat - rev 8, Adds press-and-hold power on/off, removed in Yertle
- Yertle - rev 9, Removes press-and-hold power, adds Nand software power control
- Vlad - rev 10, Enables the accelerometer to wake the processor from sleep

Find the Horton board project
https://github.com/frankcohen/ReflectionsOS/tree/main/Devices/Horton

Find the CindyLou board project
https://github.com/frankcohen/ReflectionsOS/tree/main/Devices/CindyLou

Find the RedFish board project
https://github.com/frankcohen/ReflectionsOS/tree/main/Devices/RedFish

Find the BlueFish board project
https://github.com/frankcohen/ReflectionsOS/tree/main/Devices/BlueFish

Find the Cat In Hat board project
https://github.com/frankcohen/ReflectionsOS/tree/main/Devices/CatInHat

Find the Yertle board project
https://github.com/frankcohen/ReflectionsOS/tree/main/Devices/Yertle

Find the Vlad board project
https://github.com/frankcohen/ReflectionsOS/tree/main/Devices/Vlad

## What went wrong in Vlad

U4 heated the board when charging the battery.

## VladPlus Requirements

Replace U4 with XCL238B333D2-G, Non-Isolated DC/DC Converters Non-Isolated DC/DC Converters HiSAT-COT 1.5A Inductor Built-in PWM/PFM auto control Step-Down converter

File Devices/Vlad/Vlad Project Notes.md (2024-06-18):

# Vlad project notes, Reflections

Started: June 15, 2024

Updated: June 15, 2024

Vlad is the 10th revision of the Reflections main board. 
It is the successor to Yertle, Cat In Hat, BlueFish, RedFish, CindyLou, Horton, ThingTwo, Hoober, Knox and Sox. Vlad enables the accelerometer to interrupt the ESP32, including from deep sleep.

- Sox - 1st generation board design
- Hoober - rev 2, fixes problems
- ThingTwo - rev 3, fixes problems
- Horton - rev 4, ready for software development
- CindyLou - rev 5, Beryl brighter display and component connectors
- RedFish - rev 6, Fixes LDO burn-out problem
- BlueFish - rev 7, Puts gesture sensor onto main board, moves USB port
- CatInHat - rev 8, Adds press-and-hold power on/off, removed in Yertle
- Yertle - rev 9, Removes press-and-hold power, adds Nand software power control

Find the Horton board project
https://github.com/frankcohen/ReflectionsOS/tree/main/Devices/Horton

Find the CindyLou board project
https://github.com/frankcohen/ReflectionsOS/tree/main/Devices/CindyLou

Find the RedFish board project
https://github.com/frankcohen/ReflectionsOS/tree/main/Devices/RedFish

Find the BlueFish board project
https://github.com/frankcohen/ReflectionsOS/tree/main/Devices/BlueFish

Find the Cat In Hat board project
https://github.com/frankcohen/ReflectionsOS/tree/main/Devices/CatInHat

Find the Yertle board project
https://github.com/frankcohen/ReflectionsOS/tree/main/Devices/Yertle

## What went wrong in Yertle

Added U9 (LTC2954CTS8-1#TRPBF) to provide press-and-hold power on/off. U9 interferes with the ESP32-S3 EN operation. The processor will not go into download/bootloader mode.

## Vlad Requirements

1. Connect accelerometer pin 11 and 12 (Interrupt 1 and 2) to ESP32 GPIO 13 and 14. Enables accelerometer to wake ESP32-S3 from deep sleep on movement.

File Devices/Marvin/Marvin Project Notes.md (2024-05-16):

# Marvin project notes, Reflections

Started: April 15, 2024

Updated: May 16, 2024

Marvin is the 10th revision of the Reflections main board. 
It is the successor to Yertle, Cat In Hat, BlueFish, RedFish, CindyLou, Horton, ThingTwo, Hoober, Knox and Sox.

- Sox - 1st generation board design
- Hoober - rev 2, fixes problems
- ThingTwo - rev 3, fixes problems
- Horton - rev 4, ready for software development
- CindyLou - rev 5, Beryl brighter display and component connectors
- RedFish - rev 6, Fixes LDO burn-out problem
- BlueFish - rev 7, Puts gesture sensor onto main board, moves USB port
- CatInHat - rev 8, Adds press-and-hold power on/off, removed in Yertle
- Yertle - rev 9, removes the power control in U9.
- Marvin - rev 10, Adds software Nand power control

Find the Horton board project
https://github.com/frankcohen/ReflectionsOS/tree/main/Devices/Horton

Find the CindyLou board project
https://github.com/frankcohen/ReflectionsOS/tree/main/Devices/CindyLou

Find the RedFish board project
https://github.com/frankcohen/ReflectionsOS/tree/main/Devices/RedFish

Find the BlueFish board project
https://github.com/frankcohen/ReflectionsOS/tree/main/Devices/BlueFish

Find the Cat In Hat board project
https://github.com/frankcohen/ReflectionsOS/tree/main/Devices/CatInHat

Find the Yertle board project
https://github.com/frankcohen/ReflectionsOS/tree/main/Devices/Yertle

## What went wrong in Yertle

Nand U5 is easily overwhelmed with requests. The controller stops responding. The Espressif provided SD library does not have enough logging to identify the problem, nor any logic to control the rate of interactions with the Nand controller. Only after a Nand power cycle does the Nand controller begin working again. We are solving this by adding custom logging and logic to othe SD library and in Marvin adding a software controlled method for Nand power cycling.

## Marvin Requirements

1. Remove U9

2. Use https://jlcpcb.com/partdetail/Mk-MKDV2GILAS/C726727 to increase Nand U11 storage to 2 gigabits

3. Add a software power control for the Nand U5

4. Parts substitutions. R3, R16, R20, R24, U11 are in 'shortfall' status from JLCPCB. Here are the replacements.

R3, https://jlcpcb.com/partdetail/Resi-HPCR0402F6K80K9/C365045

R16, R20, R24, https://jlcpcb.com/partdetail/Yageo-RC0402FR0710KL/C60490

U11, https://jlcpcb.com/partdetail/Mk-MKDV2GILAS/C726727

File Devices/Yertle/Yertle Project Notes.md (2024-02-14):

# Yertle project notes, Reflections

Started: February 12, 2024

Updated: February 14, 2024

Yertle is the 9th revision of the Reflections main board. 
It is the successor to Cat In Hat, BlueFish, RedFish, CindyLou, Horton, ThingTwo, Hoober, Knox and Sox. Cat In Hat added press-and-hold Boot button to power on/off the board, and it didn't work. The ESP32-S3 would not boot with the EN pin providing BOOT and power on/off controls. Yertle removes U9.

- Sox - 1st generation board design
- Hoober - rev 2, fixes problems
- ThingTwo - rev 3, fixes problems
- Horton - rev 4, ready for software development
- CindyLou - rev 5, Beryl brighter display and component connectors
- RedFish - rev 6, Fixes LDO burn-out problem
- BlueFish - rev 7, Puts gesture sensor onto main board, moves USB port
- CatInHat - rev 8, Adds press-and-hold power on/off, removed in Yertle

Find the Horton board project
https://github.com/frankcohen/ReflectionsOS/tree/main/Devices/Horton

Find the CindyLou board project
https://github.com/frankcohen/ReflectionsOS/tree/main/Devices/CindyLou

Find the RedFish board project
https://github.com/frankcohen/ReflectionsOS/tree/main/Devices/RedFish

Find the BlueFish board project
https://github.com/frankcohen/ReflectionsOS/tree/main/Devices/BlueFish

Find the Cat In Hat board project
https://github.com/frankcohen/ReflectionsOS/tree/main/Devices/CatInHat

Find the Yertle board project
https://github.com/frankcohen/ReflectionsOS/tree/main/Devices/Yertle

## What went wrong in Cat In Hat (and Lorax)

Added U9 (LTC2954CTS8-1#TRPBF) to provide press-and-hold power on/off. U9 interferes with the ESP32-S3 EN operation. The processor will not go into download/bootloader mode.

## Yertle Requirements

1. Remove U9.

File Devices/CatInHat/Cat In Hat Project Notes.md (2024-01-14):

# Cat In Hat project notes, Reflections

Started: November 26, 2023

Updated: December 7, 2023

Cat In Hat is the 8th revision of the Reflections main board. 
It is the successor to BlueFish, RedFish, CindyLou, Horton, ThingTwo, Hoober, Knox and Sox. Cat In Hat adds press-and-hold Boot button to power on/off the board, improved SPI bus traces for the NAND, and notches in the board for the boot and reset buttons.

- Sox - 1st generation board design
- Hoober - rev 2, fixes problems
- ThingTwo - rev 3, fixes problems
- Horton - rev 4, ready for software development
- CindyLou - rev 5, Beryl brighter display and component connectors
- RedFish - rev 6, Fixes LDO burn-out problem
- BlueFish - rev 7, Puts gesture sensor onto main board, moves USB port

Find the Horton board project
https://github.com/frankcohen/ReflectionsOS/tree/main/Devices/Horton

Find the CindyLou board project
https://github.com/frankcohen/ReflectionsOS/tree/main/Devices/CindyLou

Find the RedFish board project
https://github.com/frankcohen/ReflectionsOS/tree/main/Devices/RedFish

Find the BlueFish board project
https://github.com/frankcohen/ReflectionsOS/tree/main/Devices/BlueFish

## What went wrong in Blue Fish

The NAND sometimes fails to write sectors, and then fails to mount. Sometimes removing power from it will get it to mount. It could also be the board traces for the NAND's SPI bus need to be tuned for high speed operation.

The board has no power-down capability.

The case to house the board needs easy push-button access to the Boot and Reset switches. The main board gets in the way.

The board needs to host the speaker and haptic motor to fit with a minimum of height into a wrist watch case.

## Cat In Hat Requirements

1. Add press-and-hold to the Boot button to turn power on to the board, and press-and-hold to turn power off. Add LTC 2954 pushbutton on/off controller.

2. Tune the SPI bus board traces for the NAND.

3. Add notches into the board below the Boot and Reset switches.

4. Change speaker to SW151008-1 and attach to board.

5. Make room for haptic motor to be attached to board.

6. Use 0.8 board thickness.

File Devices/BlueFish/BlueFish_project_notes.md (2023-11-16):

# RedFish project notes, Reflections

Started: October 6, 2023

Updated: November 13, 2023

Blue Fish is the 7th revision of the Reflections main board. 
It is the successor to RedFish, CindyLou, Horton, ThingTwo, Hoober, Knox and Sox.
Blue Fish adds an LNA  chip so Reflections can use inexpensive and small passive GPS antennae. Predecessors require active GPS antenna. Battery, speaker, haptic motor are now connected by solder pads.

- Sox - 1st generation board design
- Hoober - rev 2, fixes problems
- ThingTwo - rev 3, fixes problems
- Horton - rev 4, ready for software development
- CindyLou - rev 5, Beryl brighter display and component connectors
- RedFish - rev 6, Fixes LDO burn-out problem

Find the Horton board project
https://github.com/frankcohen/ReflectionsOS/tree/main/Devices/Horton

Find the CindyLou board project
https://github.com/frankcohen/ReflectionsOS/tree/main/Devices/CindyLou

Find the RedFish board project
https://github.com/frankcohen/ReflectionsOS/tree/main/Devices/RedFish

## What went wrong in Red Fish

Battery powered circuit does not provide enough voltage. The voltage drop through Q3 Mosfet (FDN340P) is about 0.3V. The voltage drop through LDO is about 1V. When battery voltage is 3.3V, the output of LDO is 2V causing the display to not illuminate.

Compared Red Fish schematic to [Adafruit Feather ESP32-S3](https://learn.adafruit.com/adafruit-esp32-s3-feather/downloads) reference board. The voltage drop through mosfet and LDO is almost 0V. 

The wire-to-board connectors for battery, haptic, and speaker work well, and add expense, require a lot of pressure to close.

GPS passive antennas are less expensive and smaller in physical size than active antennas required by the GPS module.

FCP boards for the gesture sensor are too expensive.

## Blue Fish Requirements

1. Use the [LDO](https://www.digikey.com/en/products/detail/diodes-incorporated/AP2112K-3-3TRG1/4470746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) from the Adafruit Feather ESP32-S3.

2. Use the [Mosfet](https://www.digikey.com/en/products/detail/diodes-incorporated/DMG3415U-7/2052768) from the Adafruit Feather ESP32-S3.

3. Remove U7 resistor, it's not part of the Adafruit Feather ESP32-S3 reference board.

4. Add an LNA chip to the GPS module for passive antenna support. Keep the IPEX connector for now, though we may change to an on-board antenna or an FCP external connector.

5. Change the battery, haptic, and audio connectors to solder pads. Replaces the previous 009176002884906 KYOCERA AVX wire-to-board connectors.

6. Update the silk: Starling Watch 2023, BlueFish T4 AM MAG. T4 is for Thi Thu Thao Tran, a talented electronics engineer who made the changes for Blue Fish.

7. Do not place GPIO header.

8. Remove the gesture sensor connector and place a VL53L5CX Time Of Flight sensor to a new tab on the main board.

9. Move the USB connector to the 3 o'clock position relative to the top side of the main board.

10. Add a slot/hole through the board for the display FCP connection. Relocate the display connector.

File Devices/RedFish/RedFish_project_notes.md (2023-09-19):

RedFish project notes, Reflections

Started: August 7, 2023

RedFish is the 6th revision of the Reflections main board. 
It is the successor to CindyLou, Horton, ThingTwo, Hoober, Knox and Sox.
RedFish replaces the LDO power circuit and the GPS unit.

Sox - 1st generation board design
Hoober - rev 2, fixes problems
ThingTwo - rev 3, fixes problems
Horton - rev 4, ready for software development
CindyLou - rev 5, Beryl brighter display and component connectors

Find the Horton board project
https://github.com/frankcohen/ReflectionsOS/tree/main/Devices/Horton

Find the CindyLou board project
https://github.com/frankcohen/ReflectionsOS/tree/main/Devices/CindyLou

Find the RedFish board project
https://github.com/frankcohen/ReflectionsOS/tree/main/Devices/RedFish

What went wrong in CindyLou:

Power supply LDO (U4 MD7671A33PA1) and battery charging IC fried when a battery is connected to the board. If the output from the LDO is higher than the input, current flows in reverse, destroying it. Horton used TPS2113APW as the power multiplexer. CindyLou kills LDOs, most likely due to a reverse polarity condition.

Mostfet switch circuit was not correct for gesture power and TFT display power, causing them to be always on.

U1 for Haptic motor was difficult to wire because of its position on the board.

GPS unit (U14 ATGM336H-5N31) very rarely finds satellites consistently on start-up.

RedFish REQUIREMENTS
---------------------

RedFish board changes:

1. Change the LDO with AZ1117CR2-3.3TRG1
2. Change the charging IC with XC6802A42XMR-G
3. Change the mosfet switch circuit for gesture power
4. Change the mosfet switch circuit for TFT LCD
5. Move the Haptic connector 1 mm towards U1
6. Tidy up for the silk screen
7. Investigate the GPS start-up problem

Update silk: Starling Watch 2023, RedFish T4 AM MAG

T4 is for Thi Thu Thao Tran, a talented electronics engineer who made the changes for RedFish

Do not place GPIO header.

Stencil requirements for main board:

Board type :Panel by PCBWay
Panel Way :Panel in 1*2, total 5 sets=10pcs boards.
Different Design
in Panel：1
X-out Allowance in Panel :Accept
Size :86.69 x 47.78 mm
Quantity :5
Layer :
4 Layers
Material :FR-4: TG150
Thickness :
1.6 mm
Min Track/Spacing :6/6mil
Min Hole Size :
0.3mm ↑
Solder Mask :Green
Silkscreen :
White
Edge connector :No
Surface Finish :
HASL with lead
"HASL" to "ENIG"No
Via Process :
Tenting vias
Finished Copper :1 oz Cu (Inner Copper:1 oz)

Stencil for gesture daughter board:

Board type :Panel by PCBWay
Panel Way :Panel in 1*2, total 5 sets=10pcs boards.
Different Design
in Panel：1
X-out Allowance in Panel :Accept
Size :8 x 25.4 mm
Quantity :5
Layer :
2 Layers
Material :FR-4: TG150
Thickness :
1.6 mm
Min Track/Spacing :6/6mil
Min Hole Size :
0.2mm ↑
Solder Mask :Green
Silkscreen :
White
Edge connector :No
Surface Finish :
HASL with lead
"HASL" to "ENIG"No
Via Process :
Tenting vias
Finished Copper :1 oz Cu

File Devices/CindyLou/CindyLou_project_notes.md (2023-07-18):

CindyLou project notes, Reflections

Started: February 21, 2023
Updated: June 15, 2023

February 21, 2023

CindyLou is the 5th revision of the Reflections main board. 
It is the successor to Horton, ThingTwo, Hoober, Knox and Sox.
CindyLou replaces the previous display for something brighter.

Sox - 1st generation board design
Hoober - rev 2, fixes problems
ThingTwo - rev 3, fixes problems
Horton - rev 4, ready for software development

Find the Horton board project
https://github.com/frankcohen/ReflectionsOS/tree/main/Devices/Horton

Find the CindyLou board project
https://github.com/frankcohen/ReflectionsOS/tree/main/Devices/CindyLou

What went wrong in Horton:

Horton's display is too dim - produced 250 NITs of brightness. CindyLou
uses the Beryl Display at 750 NITs.

J1 and J2 connectors were for power supply circuits. They do not work
well with low power, low amperage wires. CindyLou replaces them with low powered and easy to connect wire-to-booard connectors.

CINDYLOU REQUIREMENTS
---------------------

CindyLou board changes:

Change the display pad layout to support
the Beryl Zeng CT013A6QQIGC7N10-XHT display
It does 750 NITS and appears good and bright
Add new connector to replace FPC1, and place
connector during assembly.

Update silk: Starling Watch 2023, CindyLou AM MAG

V-scoring, and the scoring needs to be against a flat (not round) part of the board

Daughter board should be the VLC53 chip on a flexible cable board, with the resisters/caps on the main board, so there’s no welding needed at the daughter board for the cable, 

USB connector is super tight against the board, needs a little tolerance

Replace J2 DF65-5P with new lighter weight connectors that handle 30 AWG guage wire to the battery, speaker, and haptic motor.
smd pcb terminal blocksw with push-in cage clamp
wire-to-board (WTB) termination
Board In, Direct Wire to Board
30 awg is 0.254mm
https://www.digikey.com/en/products/detail/kyocera-avx/009176002884906/9658714

Leave H1 Header-Male-2.54_1x4 unmounted.

Add surge protection diode array to USB using 
https://www.digikey.com/en/products/detail/littelfuse-inc/SRV05-4HTG-D/10230852

Pads for the remaining unused GPIOs, as many as will fit.

Stencil requirements for main board:

Board type :Panel by PCBWay
Panel Way :Panel in 1*2, total 5 sets=10pcs boards.
Different Design
in Panel：1
X-out Allowance in Panel :Accept
Size :86.69 x 47.78 mm
Quantity :5
Layer :
4 Layers
Material :FR-4: TG150
Thickness :
1.6 mm
Min Track/Spacing :6/6mil
Min Hole Size :
0.3mm ↑
Solder Mask :Green
Silkscreen :
White
Edge connector :No
Surface Finish :
HASL with lead
"HASL" to "ENIG"No
Via Process :
Tenting vias
Finished Copper :1 oz Cu (Inner Copper:1 oz)

Stencil for gesture daughter board:

Board type :Panel by PCBWay
Panel Way :Panel in 1*2, total 5 sets=10pcs boards.
Different Design
in Panel：1
X-out Allowance in Panel :Accept
Size :8 x 25.4 mm
Quantity :5
Layer :
2 Layers
Material :FR-4: TG150
Thickness :
1.6 mm
Min Track/Spacing :6/6mil
Min Hole Size :
0.2mm ↑
Solder Mask :Green
Silkscreen :
White
Edge connector :No
Surface Finish :
HASL with lead
"HASL" to "ENIG"No
Via Process :
Tenting vias
Finished Copper :1 oz Cu

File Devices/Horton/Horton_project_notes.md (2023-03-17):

Horton project notes, Reflections

Started: January 23, 2023
Updated: Febrruary 7, 2023

Horton is the revision 4 of the Reflections main board. Horton
fixes problems in the ThingTwo board and gets the project into
software development.

Sox - 1st generation board design
Hoober - rev 2, fixes problems
ThingTwo - rev 3, fixes problems
Horton - rev 4, ready for software development

Find the ThingTwo board project
https://github.com/frankcohen/ReflectionsOS/tree/main/Devices/ThingTwo

Find the Horton board project
https://github.com/frankcohen/ReflectionsOS/tree/main/Devices/Horton

What went wrong in ThingTwo:
  NAND did not work because of the R22 pull up resistor caused the chip select not to work

  Gesture sensor daughter board did not work because I2C R18 and R19 resisters were
  not strong enough
  
  Switches B1 and B2 not installed, BOM specified switches that will not fit the board.
  
  Layout for the magnetometer U11 was wrong
  
HORTON REQUIREMENTS
---------------------

Horton board changes:

Remove R22 Pull Up resistor on the NAND CS, not needed
Remove R31 main board, it does nothing.
Magnetometer U11 now U5 uses the correct pad layout
Specify switches B1 and B2 that fit board layout
Update silk: Starling Watch 2023, Horton AM MAG
Remove J1, change J2 to DF65-6P use pin 3, 4 for the battery
Remove OPT3002DNPT from BOM
TPS2115APW power multiplexer is out of stock, replaced with 2 FDN340P MOSFETs Q1 Q2
Change TOF name to Gesture_Power and use GPIO 26 (Don't use 44 RXD0)
Replace LIS331DLHTR accelerometer with less expensive option
Add diode to USB/Battery power circuit
Some resistors and capacitors are out of stock, replace them

Stencil requirements for main board:

Board type :Panel by PCBWay
Panel Way :Panel in 1*2, total 5 sets=10pcs boards.
Different Design
in Panel：1
X-out Allowance in Panel :Accept
Size :86.69 x 47.78 mm
Quantity :5
Layer :
4 Layers
Material :FR-4: TG150
Thickness :
1.6 mm
Min Track/Spacing :6/6mil
Min Hole Size :
0.3mm ↑
Solder Mask :Green
Silkscreen :
White
Edge connector :No
Surface Finish :
HASL with lead
"HASL" to "ENIG"No
Via Process :
Tenting vias
Finished Copper :1 oz Cu (Inner Copper:1 oz)

Stencil for gesture daughter board:

Board type :Panel by PCBWay
Panel Way :Panel in 1*2, total 5 sets=10pcs boards.
Different Design
in Panel：1
X-out Allowance in Panel :Accept
Size :8 x 25.4 mm
Quantity :5
Layer :
2 Layers
Material :FR-4: TG150
Thickness :
1.6 mm
Min Track/Spacing :6/6mil
Min Hole Size :
0.2mm ↑
Solder Mask :Green
Silkscreen :
White
Edge connector :No
Surface Finish :
HASL with lead
"HASL" to "ENIG"No
Via Process :
Tenting vias
Finished Copper :1 oz Cu

NOTES
-----

Horton ESP32 boots in 'programmer' mode, ready to upload new firmware

Getting Arduino IDE to compile and upload on MacOS 12.3.1
change python to python3 in
$HOME/Library/Arduino15/packages/esp32/hardware/esp32/2.0.2/platform.txt
https://forum.arduino.cc/t/mac-os-update-killed-esp32-sketch/969580/8

esptool on MacOS 12.3.1 with Arduino IDE 1.8.19
~/Library/Arduino15/packages/esp32/tools/esptool_py/3.1.0/esptool

Adafruit Feather ESP32-S3 has The board definition includes several software switches in the Tools drop-down menu:

USB Mode - The board definition supports two types of USB interaction with your computer. USB-OTG is USB On-the-Go (OTG) allows two USB devices to talk to each other without requiring the services of a personal computer. "Hardware CDC and JTAG" implements a serial port (CDC) to implement the serial console, instead of using UART with an external USB-UART bridge chip, including flashing, debugger, and bi-direction serial communication. I choose USB-OTG.

USB CDC On Boot - USB Communication Device Class (CDC) implements the serial console, instead of using a UART with an external USB-UART FTDI or other programmer bridge chip. I choose Enabled.

USB Firmware MSC On Boot - Mass Storage Class (MSC) makes the Feather appear to be a USB storage device connected to your computer. I choose Disabled.

USB DFU On Boot - USB Device Firmware Upgrade (DFU) enables updating the firmware of a USB device. I choose Disabled.

With the above switches set I choose the board port in the Tools menu, open the Arduino IDE Serial Monitor, then click the Upload button. I press the Boot button on the board. Arduino IDE esptool.py flashes the sketch.

After the upload completes, press the RESET button or power cycle the board

Testing Horton:

Untested:
Battery charging
JTAG debugging

Test sketches:
NAND, sketch 01SDFiles.ino, works
Display, GC9A01, 02DisplayTest.ino, backlight ok
Gestures, 03Gestures.ino, SparkFun_VL53L5CX_Library, works
GPS, ATGM336H-5N31, 04GPS.ino, works
Accelerometer, LIS331DLHTR, 05LIS3DHTR_IIC_AcceleratorReadings, 
  uses https://github.com/Seeed-Studio/Seeed_Arduino_LIS3DHTR, works
Haptic feedback, 06Haptic.ino, Adafruit_DRV2605 library, works
Audio, 07AudioHomer.ino, ESP8266Audio  library, works
Magnetometer, 08Compass.ino, MMC5603NJ, chip id 4294967295,
  https://github.com/adafruit/Adafruit_MMC56x3, works

I2C devices
I2C device found at address 0x18 (24)  LIS331_DEFAULT_ADDRESS - accelerometer
I2C device found at address 0x29 (41)  Gesture sensor
I2C device found at address 0x30 (48)  Magnetometer, compass
I2C device found at address 0x5A (90)  Haptic controller

THINGS TO-DO LIST
-----------------

Set-up Platform.io with ESP32-S3 board definition
One sketch to test all the components
Support Surface Mount Solutions (SMS) of Santa Clara, California to assemble Horton boards
Test display brightness using PWM
Test battery charging

Burning Man light sticks prototype
  Power from battery inside 1.5" PVC with WS2812 LEDs on outside
  
Calliope wrist watch prototype
  Test Horton board
  DONE Test brighter displays
  New case and strap
    Haptic motor, GPS antenna, battery, speaker
	How long does the battery last?
	Terri demonstration and approval

fcohen@starlingwatch.com March 4, 2023:
JLCPCB confirms their system is not properly showing inventory
for U4 MD7671A33PA1. They cancelled the order for that part:
https://jlcpcb.com/partdetail/998876-MD7671A33PA1/C920513
We found a component with the same footprint and function
at Mouser on https://bit.ly/3II03Mk. This is a Linear Regulator (LDO)
that puts out 3.3 volts from either USB 5V or battery 3.7 V input

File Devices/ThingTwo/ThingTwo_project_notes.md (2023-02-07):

ThingTwo project notes, Reflections

Hoober is the revision 2 of the Reflections main board. Hoober
fixes problems in the Sox board and gets closer to manufacturing.

Sox - 1st generation board design
Hoober - rev 2, fixes problems
ThingTwo - rev 3, ready for manufacturing

Find the Hoober board project at:
https://github.com/frankcohen/ReflectionsOS/tree/main/Devices/Hoober

Find the ThingTwo board project
https://github.com/frankcohen/ReflectionsOS/tree/main/Devices/ThingTwo

What went wrong in Hoober:

- TFT display module pads used wrong pitch, the amazing Ryan Orosz of
Surface Mount Solutions in Santa Clara, California created a patch cable.

- Power-up did not work as expected, and was unneeded.

- GPS did not work, no satellites captured.

- NAND pads reversed.

- Feedback from the Element14 community says we should have no components,
  traces, and vias under and around the ESP32 antenna array, https://bit.ly/3Od68kH

- Power to the display cable did not work.

- Using Adafruit Feather ESP32-S3-Mini board definition. This appears
  incompatible with Platform.IO and the JTAG debugger support.

- ESP32-S3 does not reset after upload from Arduino IDE and esptool.py v3.3.1.
  This is a bug in the ESP32-S3 firmware.
  https://github.com/espressif/arduino-esp32/issues/6762

- Adafruit_DRV2605 software library does not support custom SPI pins for
  the Haptic feedback motor.

- Forgot to order PCB SMT stencils from PCBway. Had new ones produced
  in California by Surface Mount Solutions.

- Original PCBway order forgot to panelize the boards. Surface Mount Solutions
  of Santa Clara, California did the board assembly. They really like v-score
  instead of drilled tabs. And "north south east and west" orientation.

- Last minute parts swaps due to out-of-stock sitatuions.  

- Pandemic forced Shanghai city quarantine, slowing parts availability.

THINGTWO REQUIREMENTS
---------------------

ThingTwo is the 3rd revision of the Reflections main board. It is the successor to Hoober and Sox.

ThingTwo board changes:

+ Pickup Hoober rework changes, details in https://bit.ly/3PmWc9c

+ Remove power-on/off circuit and power button.

+ Replace GPS circuit with ATGM336H module. Power on/off control using a GPIO.

+ Display connector pads have corrected pitch.

+ Remove traces and vias around ESP32 antenna, https://bit.ly/3Od68kH

+ Add more room around the daughter board cable pads for easier soldering.

+ Label ESP32-S3-Mini-1-CUSTOM since we fixed some issues the Hoober footprint
  had with the Thermal Pads causing false flag DRC errors. It is the same as
  the previous footprints.

+ Put ESP32-S3 into JTAG USB mode on boot (GPIO3 is high on reset) AND make it
  possible to desolder a resistor (R19) to change GPIO3 to be low on reset for
  GPIO39-42 JTAG interface.

NOTES
-----

Getting Arduino IDE to compile and upload on MacOS 12.3.1
change python to python3 in
$HOME/Library/Arduino15/packages/esp32/hardware/esp32/2.0.2/platform.txt
https://forum.arduino.cc/t/mac-os-update-killed-esp32-sketch/969580/8

esptool on MacOS 12.3.1 with Arduino IDE 1.8.19
~/Library/Arduino15/packages/esp32/tools/esptool_py/3.1.0/esptool

Adafruit Feather ESP32-S3 has The board definition includes several software switches in the Tools drop-down menu:

USB Mode - The board definition supports two types of USB interaction with your computer. USB-OTG is USB On-the-Go (OTG) allows two USB devices to talk to each other without requiring the services of a personal computer. "Hardware CDC and JTAG" implements a serial port (CDC) to implement the serial console, instead of using UART with an external USB-UART bridge chip, including flashing, debugger, and bi-direction serial communication. I choose USB-OTG.

USB CDC On Boot - USB Communication Device Class (CDC) implements the serial console, instead of using a UART with an external USB-UART FTDI or other programmer bridge chip. I choose Enabled.

USB Firmware MSC On Boot - Mass Storage Class (MSC) makes the Feather appear to be a USB storage device connected to your computer. I choose Disabled.

USB DFU On Boot - USB Device Firmware Upgrade (DFU) enables updating the firmware of a USB device. I choose Disabled.

With the above switches set I choose the board port in the Tools menu, open the Arduino IDE Serial Monitor, then click the Upload button. I press the Boot button on the board. Arduino IDE esptool.py flashes the sketch.

After the upload completes, I need to re-choose the USB Port, then click the Reset button.
I see the output correctly in the Serial Monitor.

Testing ThingTwo:

Untested:
Battery charging
JTAG debugging

Test sketches:
NAND, sketch 06SDFiles.ino, works
Display, GC9A01, 15DisplayTest.ino, backlight ok
Gestures, 14Gestures.ino, SparkFun_VL53L5CX_Library, works
GPS, ATGM336H-5N31, 05GPS.ino, works
Accelerometer, LIS331DLHTR, 01_lis331_accellerometer, uses Adafruit LIS331 library, works
Haptic feedback, 02Haptic.ino, Adafruit_DRV2605 library, works
Audio, 13AudioHomer.ino, ESP8266Audio  library, works
Magnetometer, MMC5603NJ, chip id 4294967295, https://github.com/adafruit/Adafruit_MMC56x3, works

I2C devices
I2C device found at address 0x18 (24)  LIS331_DEFAULT_ADDRESS - accelerometer
I2C device found at address 0x29 (41)  Gesture sensor
I2C device found at address 0x30 (48)  Magnetometer, compass
I2C device found at address 0x5A (90)  Haptic controller

ThingTwo boards
Board #1
Port not registering

Board #2
I2C device found at address 0x18 (24)  LIS331_DEFAULT_ADDRESS - accelerometer
I2C device found at address 0x5A (90)  Haptic controller
Display works
NAND works

Board #3
I2C device found at address 0x18 (24)  LIS331_DEFAULT_ADDRESS - accelerometer
I2C device found at address 0x30 (48)  Magnetometer, compass
I2C device found at address 0x5A (90)  Haptic controller
Display does not work, backlight on
No gesture sensor installed
NAND does not work

Board #4
I2C device found at address 0x18 (24)  LIS331_DEFAULT_ADDRESS - accelerometer
I2C device found at address 0x5A (90)  Haptic controller
Display works
NAND works
GPS does not return data

Explorations in MicroPython

https://docs.micropython.org/en/latest/esp32/quickref.html

Make backup of board:
a) Install esptool from https://github.com/espressif/esptool/releases
./esptool-v4.4-macos/esptool --chip esp32s3 -b 115200 --port /dev/cu.usbmodem1442201 read_flash 0x00000 0x400000 ./flash_4M.bin

./esptool --chip esp32s3 --port /dev/cu.usbmodem1442201 read_flash 0x00000 0x400000 ./flash_4M.bin

Install MicroPython:

esptool-v4.4-macos did not work, stalled on using its stub
Using /Users/frankcohen/Library/Arduino15/packages/esp32/tools/esptool_py/3.3.0/esptool works:

Backup using:
/Users/frankcohen/Library/Arduino15/packages/esp32/tools/esptool_py/3.3.0/esptool --chip esp32s3 --port /dev/cu.usbmodem1432201 read_flash 0x00000 0x400000 ./ThingTwo_Backup_20230114_flash_4M.bin

Erase flash
/Users/frankcohen/Library/Arduino15/packages/esp32/tools/esptool_py/3.3.0/esptool --chip esp32s3 --port /dev/cu.usbmodem1432201 erase_flash

Install MicroPython firmware:
/Users/frankcohen/Library/Arduino15/packages/esp32/tools/esptool_py/3.3.0/esptool --chip esp32s3 --port /dev/cu.usbmodem1432201 write_flash -z 0 ./MicroPython_GENERIC_S3-20220618-v1.19.1.bin

Restart the board, use Serialtools to communicate over USB, and it works:
>>> print(‘Hi Avinadad and Muhammad’)
Hi Avinadad and Muhammad

Next I need a MacOS compatible IDE to develop my MicroPython ReflectionsOS.
Considering CircuitPython, Platform.io (doesn't do python), Arduino IDE, Thonny IDE

Thonny IDE tutorial:
https://randomnerdtutorials.com/getting-started-thonny-micropython-python-ide-esp32-esp8266/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

It would be so nice to have a JTAG-style debugger for MicroPython on ESP32

Mu Editor
uPyCraft IDE
VS Code + Pymakr Extension
PyCharm

Install CircuitPython:
/Users/frankcohen/Library/Arduino15/packages/esp32/tools/esptool_py/3.3.0/esptool --chip esp32s3 --port /dev/cu.usbmodem1234561 erase_flash

/Users/frankcohen/Library/Arduino15/packages/esp32/tools/esptool_py/3.3.0/esptool --chip esp32s3 --port /dev/cu.usbmodem1234561 write_flash -z 0x1000 ./ThingTwo_Backup_20230114_flash_4M.bin

Enable WebREPL with password: ABCDEF

J1 - Battery
J2 - Haptic motor, speaker

MMC5603NJ magnetometer/compass

Question? Ask principal maintainer Frank Cohen, fcohen@starlingwatch.com

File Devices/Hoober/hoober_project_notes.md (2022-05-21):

Hoober project notes, Reflections

Hoober is the revision 2 of the Reflections main board. Hoober
fixes problems in the Sox board and gets closer to manufacturing.

Sox - 1st generation board design
Hoober - rev 2, fixes problems
ThingTwo - rev 3, ready for manufacturing

Problems from the Sox board project
https://github.com/frankcohen/ReflectionsOS/tree/main/Devices/Sox

What went wrong in Sox:

- Capacitor/resistor missing for ESP32 to be in firmware upload mode.

- Unknown Arduino IDE board specification for ESP32 S3.

- Unknown if the ESP32 S3's came with bootloader pre-burned.

- Too many pads for my shaky hands to solder.

- The 6 layer Avinidad version is 11 times more expensive than the 4 layer
Muhammad version. Both are made by PCBway. Product W433092AS1K2 (Avinidad)
cost $58 USD per board with 6 layers, 39.5x36.1mm, with 75 pads.
Product W356416AS1J3 (Muhammad) cost $5 USD per board with 34 mm x 36 mm,
4 layers, and 68 pads.

- 4PCB delivered 6 weeks late, cost 5 times more, and assembly missed
3 parts.

- Pandemic forced Shenzhen city quarantine, slowing delivery.

- IMU became unavailable and was replaced.

- ESP32 S3 was just being released and we waited 1 month for inventory.

- DHL lost a parts shipment to Arizona, USA based 4PCB.

- Sox Avinadad board TXCO power pads reversed.

- IPX display ground connector reversed.

- ESP32 pin 23 is data native USB support, don't need an FTDI converter for USB.

- USB connector solder connections could not hold the connector to the board.

HOOBER REQUIREMENTS
-------------------

- Sketch upload with Arduino IDE 1.8.19 over USB C connector.

- Uses "Adafruit ESP32-S3 Feather No PSRAM" derived Arduino IDE board definition.
  https://www.adafruit.com/product/5323
  Schematic at
  https://learn.adafruit.com/assets/110822
  other files at:
  https://learn.adafruit.com/adafruit-esp32-s2-feather/downloads

- ESP32 S3 Mini with Espressif bootloader pre-flashed.

- Hirose DF65 Connector for speaker, haptic motor, battery wire connections
  https://www.hirose.com/product/series/DF65
  Hoober removes the Sox solder pads for speaker, haptic, gesture, battery, power, center/left/right buttons
  Remove resistors for center, left, right buttons.

- Power switch, press and hold to turn-on, press to force off. Switch is
  side mounted at the edge of the board, at a 180 degree angle from the USB port.

- Boot and Reset buttons buttons side mounted at the edge of the board.

- Battery charging when powered over USB-C. Powered by LiPo or USB.

- TFT welded to board, no connector.

- Board size is 34 mm round, no tab for USB port

- Gesture Sensor daughterboard and main board connector. Specs at:
  https://github.com/frankcohen/ReflectionsOS/blob/main/Devices/Hoober/Gesture%20Sensor%20Daughter%20Board.pdf
  Power to the TOF sensor programmable from one of the GPIOs

- JTAG pogo pin connectors to pins:
  TDI - GPIO 12
  TMS - GPIO 14
  TCLK - GPIO 13
  TDO - GPIO 15
  Single row Test programming fixture pogo pin pitch 2.54mm 8P/9P/10P/11P/ 3P~12P with wire
  https://www.ebay.com/itm/143924370628?var=443188826270

- USB port at 45 degrees to the ESP

- Board clearance around ESP32-S3-Mini antenna

- Green board color

- Boards in panelization

NOTES
-----

Getting Arduino IDE to compile and upload on MacOS 12.3.1
change python to python3 in
$HOME/Library/Arduino15/packages/esp32/hardware/esp32/2.0.2/platform.txt
https://forum.arduino.cc/t/mac-os-update-killed-esp32-sketch/969580/8

esptool on MacOS 12.3.1 with Arduino IDE 1.8.19
~/Library/Arduino15/packages/esp32/tools/esptool_py/3.1.0/esptool

Adafruit Feather ESP32-S3 has The board definition includes several software switches in the Tools drop-down menu:

USB Mode - The board definition supports two types of USB interaction with your computer. USB-OTG is USB On-the-Go (OTG) allows two USB devices to talk to each other without requiring the services of a personal computer. "Hardware CDC and JTAG" implements a serial port (CDC) to implement the serial console, instead of using UART with an external USB-UART bridge chip, including flashing, debugger, and bi-direction serial communication. I choose USB-OTG.

USB CDC On Boot - USB Communication Device Class (CDC) implements the serial console, instead of using a UART with an external USB-UART FTDI or other programmer bridge chip. I choose Enabled.

USB Firmware MSC On Boot - Mass Storage Class (MSC) makes the Feather appear to be a USB storage device connected to your computer. I choose Disabled.

USB DFU On Boot - USB Device Firmware Upgrade (DFU) enables updating the firmware of a USB device. I choose Disabled.

With the above switches set I choose the board port in the Tools menu, open the Arduino IDE Serial Monitor, then click the Upload button. I press the Boot button on the board. Arduino IDE esptool.py flashes the sketch.

After the upload completes, I click the Boot button. I see the output correctly in the Serial Monitor.

Question? Ask principal maintainer Frank Cohen, fcohen@votsh.com

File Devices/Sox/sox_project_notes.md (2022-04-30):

Sox project notes, Reflections

I need the EasyEDA schematic and layout for the Sox board
This is a 36 mm round board, probably 4 or more layers,
ESP32 Arduino-compatible design. Components are mounted top and bottom.

Sox is the main logic board for a new open-source hardware
project. Reflections will power entertainment and mobile
experiences.

I put files, photos of the breadboard, software, wiring guide into
https://github.com/frankcohen/ReflectionsOS/tree/main/Devices/Sox

Requirements for this project:
1) Schematic, Layout, and BOM developed in EasyEDA Designer https://easyeda.com/editor

2) 36 mm diameter round board, designers choice on number of layers, traces are
1 oz copper thickness, 1.6 mm board thickness, components mounted on both
sides.

3) The breadboard for this project uses break out boards. These
have a bunch of step-up/down 3.3-5 volt adaptors, none of these are
necessary for the board. Everything needs to fit onto the 36 mm diameter
round board, except for the GPS antenna, TFT display, gesture sensor,
speaker, haptic motors, and battery. The board MUST use parts that are
widely/easily available, determined by checking stock and availability
levels in LCSC.COM and Digikey.com.

4) Photos of the breadboard are at:
https://github.com/frankcohen/ReflectionsOS/tree/main/Devices/Sox/Breadboard%20Photos

5) Board is powered by 1 lithium ion battery: 3.7 volts, 500 mAh with
solder pads for VCC and Ground.
All components are on 3.3 volts.
The board needs a battery sensor, a voltage divider connected to GPIO 2
to measure the battery voltage. Unlike the usual ESP32 development boards
there is no LED on this board.
The board needs to operate while USB is connected and charging the battery.
I anticipate users plugging in a USB powerbank to keep the watch going as
they play games on it.

6) GPIO 36 (right button), 39 (center button), 34 (left button) are pads on the
board. We will solder wires connecting the pads to SPST button switches.
Each has a pull-down resistor. GPIO 39 (center button) is also a control for
turning the board on and off. Push and hold for 3 seconds to turn on or off.

7) The board needs a uart, using the same provided on the HiLetGo ESP32 dev board
CP2102-GM. https://lcsc.com/product-detail/USB-ICs_SILICON-LABS-CP2102-GMR_C6568.html
USB connector at 180 degrees from ESP32 antennae for layout. Use Micro-USB C
to allow for battery charging during operation.

8) GPS module uses AT6558 running 3.3 volts. Breadboard shows connected to 5 volts
due to a requirement of the GPS breakout board. The breadboard uses the GPS + BDS
BeiDou Dual Module Flight Control Wiki - DFRobot breakout board. The board uses
only the AT6558 chip. And the board needs to provide an IPEX/uFl connector for the GPS antenna.
When I put the board into a wrist watch enclosure the GPS antenna will go into the wrist band.
https://www.digikey.com/en/products/detail/suntsu-electronics,-inc./SCNRF-6AAN-P1FS/14291136?utm_adgroup=Suntsu%20Electronics%20Inc&utm_source=google&utm_medium=cpc&utm_campaign=Shopping_DK%2BSupplier_Other&utm_term=&utm_content=Suntsu%20Electronics%20Inc&gclid=CjwKCAiAxJSPBhAoEiwAeO_fP0jt6Ce-0s7Bdl8Msl-FxEtlkEP35RCr5qoYZS6azBifDDCklZcshhoCEmIQAvD_BwE

9) Gesture sensor (VL53L5CX) is not mounted on the board, it is connected via
4 wires (VCC, Gnd, SCL, SDA/NAND), board needs 4 pads for soldering the wires.
https://www.st.com/resource/en/datasheet/vl53l5cx.pdf

10) Display 13-pin screen connector cable uses FPC connector. 1.28 inch lcd round is
a 240x240 display using GC9A01 driver HD ips.
https://www.aliexpress.com/item/1005002389910393.html
https://jlcpcb.com/parts/componentSearch?isSearch=true&searchTxt=XUNPU%20FPC-05F-12PH20
Also listed here:
https://pan.baidu.com/s/1x9B9jKrjikSCBUI38ZUC3w Extraction code: 8888
https://www.taobao.com/list/item/606659413574.htm?spm=a21wu.12321156.recommend-tpp.1
Display backlight (BLK) tied to an unused GPIO.

11) Breadboard uses an ESP32 WROOM Development Board. To minimize space Requirements
the board may use the ESP32-S3-MINI-1.
https://www.espressif.com/en/products/modules

12) Not all of the GPIO pins on the ESP32 are available to use.
See the Sox wiring guide for details:
https://github.com/frankcohen/ReflectionsOS/blob/main/Devices/Sox/Sox%20wiring%20guide.pdf
Do not attach to the GPIOs marked in red.
This is based on research from Andreas Speiss, see
https://www.youtube.com/watch?v=LY-1DHTxRAk and
https://drive.google.com/file/d/1gbKM7DA7PI7s1-ne_VomcjOrb0bE2TPZ/view

13) PCB design best practices: decoupling capacitors, landing patterns large enough
for the footprint, avoid too many via holes, avoid excessive trace lengths (especially
in the SPI bus between TFT, SD/NAND, and ESP32), avoid EMI from the ESP32 antennae, and
expect board revisions to correct unforeseen problems.

Uses ESP32 processors with pre-burned ESP-IDF V3.1 bootloader. The boards must
be verified by connecting a USB cable to a laptop running Arduino IDE 1.8 or later
and flash a testing sketch.
https://docs.espressif.com/projects/esp-idf/en/latest/esp32/api-guides/bootloader.html

15) The board is not user expandable to add more devices to the I2C, SPI buses.

16) Pads for battery, gesture sensor, haptic motor, speaker, 3 buttons

Changes to above:
Jan 19, 2022 - Mohammed using IMU LSM6DS3TR
https://lcsc.com/product-detail/Attitude-Sensors_STMicroelectronics-LSM6DS3TR-C_C967633.html

Jan 19, 2022 - Avinadad using AT6558R GPS (different from AT6558R, same pin layout)

Jan 19, 2022 - Avinadad ads GPIO 3 for battery voltage sensing

Jan 20, 2022 - Mohammed using 1 GB NAND/SD
https://lcsc.com/product-detail/NAND-FLASH_XTX-XTSD01GLGEAG_C558837.html

Jan 20, 2022 - Avinadad is basing higher pull-up resistors for I2C to lower the
battery drain. The board is not user expandable to add more devices to the I2C bus.
The board needs to operate while USB is connected and charging the battery.
I anticipate users plugging in a USB powerbank to keep the watch going as
they play games on it. To support this requires USB-C.

Jan 21, 2022 - Mohammed did not find a .7 pitch connector for the display.
I added the display datasheet and pointed him to:
https://www.aliexpress.com/item/1005002389910393.html

Jan 21, 2022 - Avinadad asked if the board needs a volume button. The board
will control volume through software only.

Jan 22, 2022 - Changed IMU and magnetometer/compass to these:
LIS2DH12 - 3 axis MEMS accelerometer
https://www.sparkfun.com/products/15760
https://jlcpcb.com/parts/componentSearch?isSearch=true&searchTxt=LIS2DH12
And,
Magnetometer - MMC5603NJ
https://datasheet.lcsc.com/lcsc/1912111437_MEMSIC-MMC5603NJ_C404328.pdf

Jan 22, 2022 - Changing from APDS-9960 gesture sensor to VL53L5CX sensor.
https://www.st.com/resource/en/datasheet/vl53l5cx.pdf

Jan 23, 2022 - Display cable 13 pin connector welded to the board,
not the adaptor board 7 pin connector

Jan 24, 2022 - Not all of the GPIO pins on the ESP32 are available to use.
See the Sox wiring guide for details:
https://github.com/frankcohen/ReflectionsOS/blob/main/Devices/Sox/Sox%20wiring%20guide.pdf
Do not attach to the GPIOs marked in red.
This is based on research from Andreas Speiss, see
https://www.youtube.com/watch?v=LY-1DHTxRAk and
https://drive.google.com/file/d/1gbKM7DA7PI7s1-ne_VomcjOrb0bE2TPZ/view

Jan 24, 2022 - Changing to USB C and adding a uart removes the need
for 'FTDI pads for pogo pins to flash the ESP32 bootloader'.

Jan 24, 2022 - Using this connector for the display adaptor. XUNPU FPC-05F-12PH20
https://jlcpcb.com/parts/componentSearch?isSearch=true&searchTxt=XUNPU%20FPC-05F-12PH20
Display backlight (BLK) tied to an unused GPIO.

Jan 26, 2022 - BLK  needs to be connected to a GPIO. I ran out of available GPIO pins
on the breadboard, there are others from the ESP32 you will use for BLK (so I man
turn-off the display and save some battery life with software).
CS gets connected to GPIO 32 and DC connected to GPIO 16

Jan 27, 2022 - Pads for battery, gesture sensor, haptic motor, speaker, 3 buttons

Jan 30, 2022 - Power switch. Every single component, sans the battery charger,
gets power through the 3.3v converter, so if the 3.3v is disabled, everything
else on the board is off. This way, even if the 3.3v converter is disabled,
the battery still charges when connected to the USB. Because the battery
charger gets power from the USB connector itself, VBUS. BATT_SENSOR.

Feb 1, 2022 - ESP32-S3-Mini is a new part and difficult to find in stock at
the moment. There are some for sale on AliExpress. Since the ESP32-S2-Mini is
available and pin compatible with the S3, the first round manufactured/assembled
boards will come with S2. The second round and beyond will come with S3.

Feb 1, 2022 - Avinadad is widening the traces and having more spacing
to lower the cost of the boards. At least 0.208mm wide traces and spacing
will avoid paying premiums on 4pcb.com. Smaller traces are more expensive.
This board smallest traces are 0.165mm, most are 0.25mm. The goal is to
increase the 0.165mm lines to 0.21mm, and every line has at least 0.21mm
spacing from each other.

Feb 1, 2022 - Changed audio amp to MAX98357AETE+T since the previous one
was so small, traces couldn't exceed 6.3mils, therefore increasing price
on the PCB. I also improved the ground connections, eliminated some vias,
and increased track width/spacing on the audio chip lines

April 30, 2022 - Behold the beautiful Sox board: Gorgeous and non-functional:

Photo of the front side of the main board, codenamed Sox Main board front side

Photo of the back side of the main board, codenamed Sox Main board back side

What went wrong:

- Capacitor/resistor missing for ESP32 to be in firmware upload mode.

- Unknown Arduino IDE board specification for ESP32 S3.

- Unknown if the ESP32 S3's came with bootloader pre-burned.

- Too many pads for my shaky hands to solder.

- The 6 layer Avinidad version is 11 times more expensive than the 4 layer
Muhammad version. Both are made by PCBway. Product W433092AS1K2 (Avinidad)
cost $58 USD per board with 6 layers, 39.5x36.1mm, with 75 pads.
Product W356416AS1J3 (Muhammad) cost $5 USD per board with 34 mm x 36 mm,
4 layers, and 68 pads.

- 4PCB delivered 6 weeks late, cost 5 times more, and assembly missed
3 parts.

- Pandemic forced Shenzhen city quarantine, slowing delivery.

- IMU became unavailable and was replaced.

- ESP32 S3 was just being released and we waited 1 month for inventory.

- DHL lost a parts shipment to Arizona, USA based 4PCB.

- Sox Avinadad board TXCO power pads reversed.

See the Hoober board notes for the 2nd revision to the Sox board:

https://github.com/frankcohen/ReflectionsOS/blob/main/Devices/Hoober/hoober_project_notes.md

Question? Ask principal maintainer Frank Cohen, fcohen@votsh.com

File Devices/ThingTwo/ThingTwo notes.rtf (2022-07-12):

July 11, 2022

ThingTwo is the 3rd revision of the Reflections main board. It is the successor to Hoober and Sox.

ThingTwo board changes:
Pickup Hoober rework changes
Remove power-on/off circuit and power button
Replace GPS circuit with ATGM336H module
Power on LED
Display connector pads correct pitch
Remove traces and vias below ESP32 antenna
Board gear edge and logo just for style

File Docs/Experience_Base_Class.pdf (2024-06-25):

# Experience Base Class

Reflections Project
by Frank Cohen, fcohen@starlingwatch.com
Distributed under a GPL v3 open-source license. https://github.com/frankcohen/ReflectionsOS

My prompt to ChatGPT 4: I am writing c++ code in Arduino IDE 2.3.2 for ESP32-S3. I have a central dispatch object called Inveigle. It is implemented as a .cpp and .h files. It randomly picks 1 of 5 experiences. Each experience has a setup, run, and teardown part state, with the conclusion of one state starting the next, and when the teardown part finishes, the Inveigle randomly picks another experience. Each experience can be overriden at any time in the setup and run parts, in which case the teardown part runs. I will add additional experiences over time. I need the code to have an abstract base class definition to implement each experience.

ChatGPT response:
To create a robust and extensible system for handling experiences in your Inveigle object, you can use an abstract base class for the experiences. This will ensure that each experience has a consistent interface for setup, run, and teardown operations. Here's a possible implementation of the system:

Experience Base Class (Abstract)

First, define an abstract base class Experience in Experience.h. This class will declare the virtual methods for setup, run, and teardown, which must be implemented by any derived class.

cpp

// Experience.h
#ifndef EXPERIENCE_H

#define EXPERIENCE_H

class Experience {
public:
virtual ~Experience() {}

virtual void setup() = 0;
virtual void run() = 0;
virtual void teardown() = 0;
};
Experience Base Class | Page 1 of 11 | https://github.com/frankcohen/ReflectionsOS

#endif // EXPERIENCE_H

Example Derived Experience Class

Next, create a concrete implementation of the Experience class. For example, Experience1.

cpp

// Experience1.h
#ifndef EXPERIENCE1_H

#define EXPERIENCE1_H

#include "Experience.h"

class Experience1 : public Experience { public:
void setup() override;
void run() override;
void teardown() override;
};

#endif // EXPERIENCE1_H

// Experience1.cpp
#include "Experience1.h"

#include <Arduino.h>

void Experience1::setup() {
// Setup code for Experience1 Serial.println("Experience1 setup"); }

void Experience1::run() {
// Run code for Experience1 Serial.println("Experience1 run"); }
Experience Base Class | Page 2 of 11 | https://github.com/frankcohen/ReflectionsOS

void Experience1::teardown() {
// Teardown code for Experience1 Serial.println("Experience1 teardown"); }

Central Dispatch Object (Inveigle)

Now, create the Inveigle class that manages the experiences. It will randomly pick an experience, handle state transitions, and allow for experiences to be overridden.

cpp

// Inveigle.h
#ifndef INVEIGLE_H

#define INVEIGLE_H

#include "Experience.h"

#include <vector>

class Inveigle {
public:
Inveigle();
void setup();
void run();
void overrideExperience(Experience* newExperience);

private:
void pickRandomExperience();
void transitionToNextState();

std::vector<Experience*> experiences; Experience* currentExperience;
enum State { SETUP, RUN, TEARDOWN } currentState; };

#endif // INVEIGLE_H

// Inveigle.cpp
#include "Inveigle.h"

#include "Experience1.h"

Experience Base Class | Page 3 of 11 | https://github.com/frankcohen/ReflectionsOS

// Include other experiences as needed
#include <Arduino.h>

Inveigle::Inveigle() : currentExperience(nullptr), currentState(SETUP) {
// Add instances of each experience to the vector experiences.push_back(new Experience1());
// Add other experiences here
}

void Inveigle::setup() {
pickRandomExperience();
currentExperience->setup(); currentState = RUN;
}

void Inveigle::run() {
if (currentState == RUN) { currentExperience->run();
// Check for override condition here } else if (currentState == TEARDOWN) { currentExperience->teardown(); pickRandomExperience();
currentExperience->setup(); currentState = RUN;
}
}

void Inveigle::overrideExperience(Experience* newExperience) {
currentExperience->teardown();
delete currentExperience;
currentExperience = newExperience; currentExperience->setup(); currentState = RUN;
}

void Inveigle::pickRandomExperience() { if (currentExperience) {
delete currentExperience;
Experience Base Class | Page 4 of 11 | https://github.com/frankcohen/ReflectionsOS

}
int randomIndex = random(experiences.size()); currentExperience = experiences[randomIndex]; }

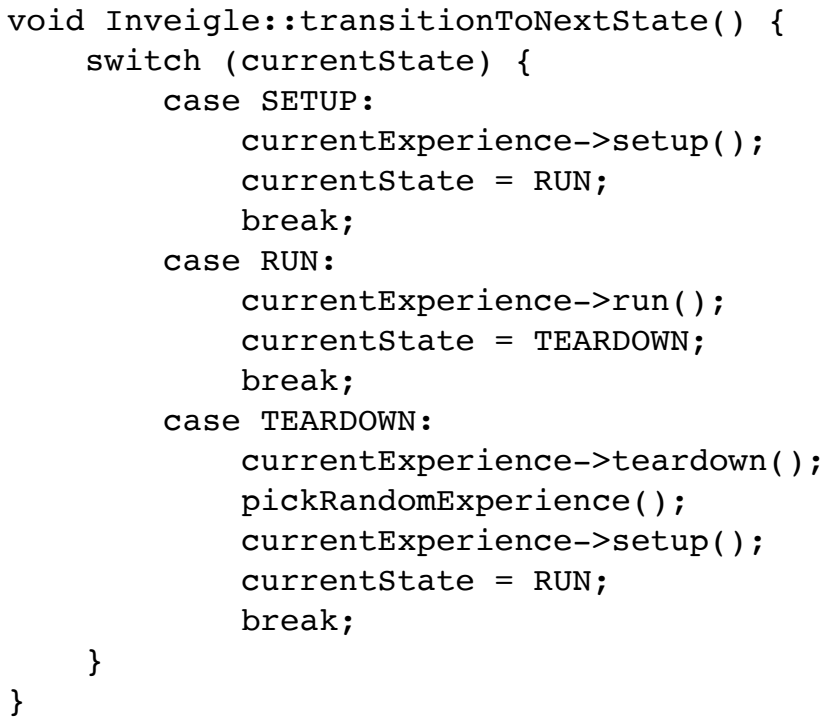
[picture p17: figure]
switch (currentState) { case SETUP: currentExperience->setup(); currentState = RUN; break; case RUN: currentExperience->run(); currentState = TEARDOWN; break; case TEARDOWN: currentExperience->teardown(); pickRandomExperience(); currentExperience->setup(); currentState = RUN; break;

void Inveigle::transitionToNextState() {

Usage in the Arduino Sketch

Finally, use the Inveigle object in your Arduino sketch.

cpp

// sketch.ino
#include <Arduino.h>

#include "Inveigle.h"

Inveigle inveigle;

void setup() {
Serial.begin(115200);
inveigle.setup();
Experience Base Class | Page 5 of 11 | https://github.com/frankcohen/ReflectionsOS

}

void loop() {
inveigle.run();
// Add delay or other logic as needed
delay(1000);
}
This setup ensures that each experience can be managed uniformly through the Experience base class, and the Inveigle class handles the lifecycle and random selection of experiences. You can add additional experiences by creating new derived classes from Experience and adding them to the Inveigle's experience list.

My ask of ChatGPT:

Please give me an example of creating Experience 6. In this experience the Setup makes a call to video.cpp to start running a mpeg video. You do not need to show me video.cpp. The interface is video::startVideo(String videoName). The Teardown makes a call to video::stopVideo();

ChatGPT response

Certainly! Below is an example of how you can create Experience6, which will utilize the video::startVideo and video::stopVideo functions as described.

Experience6 Header

Create a new header file Experience6.h:

cpp

// Experience6.h
#ifndef EXPERIENCE6_H

#define EXPERIENCE6_H

#include "Experience.h"

#include <Arduino.h>

class Experience6 : public Experience { public:
void setup() override;
void run() override;
void teardown() override;
};
Experience Base Class | Page 6 of 11 | https://github.com/frankcohen/ReflectionsOS

#endif // EXPERIENCE6_H

Experience6 Implementation

Create the corresponding implementation file Experience6.cpp:

cpp

// Experience6.cpp
#include "Experience6.h"

#include "video.h" // Assuming video.h is where video::startVideo and video::stopVideo are declared

void Experience6::setup() {
// Setup code for Experience6 Serial.println("Experience6 setup"); video::startVideo("example.mpeg"); // Replace "example.mpeg" with your video name
}

void Experience6::run() {
// Run code for Experience6 Serial.println("Experience6 run"); // Add any additional run logic here }

void Experience6::teardown() {
// Teardown code for Experience6 Serial.println("Experience6 teardown"); video::stopVideo();
}

Including Experience6 in Inveigle

Modify the Inveigle class to include Experience6.

Update the Header

Update Inveigle.h to forward-declare Experience6:

Experience Base Class | Page 7 of 11 | https://github.com/frankcohen/ReflectionsOS

cpp

// Inveigle.h
#ifndef INVEIGLE_H

#define INVEIGLE_H

#include "Experience.h"

#include <vector>

class Inveigle {
public:
Inveigle();
void setup();
void run();
void overrideExperience(Experience* newExperience);

private:
void pickRandomExperience();
void transitionToNextState();

std::vector<Experience*> experiences; Experience* currentExperience;
enum State { SETUP, RUN, TEARDOWN } currentState; };

#endif // INVEIGLE_H

Update the Implementation

Update Inveigle.cpp to include and initialize Experience6:

cpp

// Inveigle.cpp
#include "Inveigle.h"

#include "Experience1.h"

#include "Experience6.h"

// Include other experiences as needed #include <Arduino.h>
Experience Base Class | Page 8 of 11 | https://github.com/frankcohen/ReflectionsOS

Inveigle::Inveigle() : currentExperience(nullptr), currentState(SETUP) {
// Add instances of each experience to the vector experiences.push_back(new Experience1()); experiences.push_back(new Experience6());
// Add other experiences here
}

void Inveigle::setup() {
pickRandomExperience();
currentExperience->setup(); currentState = RUN;
}

void Inveigle::run() {
if (currentState == RUN) { currentExperience->run();
// Check for override condition here } else if (currentState == TEARDOWN) { currentExperience->teardown(); pickRandomExperience();
currentExperience->setup(); currentState = RUN;
}
}

void Inveigle::overrideExperience(Experience* newExperience) {
currentExperience->teardown();
delete currentExperience;
currentExperience = newExperience; currentExperience->setup(); currentState = RUN;
}

void Inveigle::pickRandomExperience() { if (currentExperience) {
delete currentExperience;
}
int randomIndex = random(experiences.size());
Experience Base Class | Page 9 of 11 | https://github.com/frankcohen/ReflectionsOS

currentExperience = experiences[randomIndex]; }

switch (currentState) { case SETUP: currentExperience->setup(); currentState = RUN; break; case RUN: currentExperience->run(); currentState = TEARDOWN; break; case TEARDOWN: currentExperience->teardown(); pickRandomExperience(); currentExperience->setup(); currentState = RUN; break;

void Inveigle::transitionToNextState() {

Updating the Arduino Sketch

Ensure that the sketch includes the Inveigle header and properly initializes the system:

cpp

// sketch.ino
#include <Arduino.h>

#include "Inveigle.h"

Inveigle inveigle;

void setup() {
Serial.begin(115200);
inveigle.setup();
}
Experience Base Class | Page 10 of 11 | https://github.com/frankcohen/ReflectionsOS

void loop() {
inveigle.run();
// Add delay or other logic as needed
delay(1000);
}
With these changes, Experience6 will start playing a video when it is set up, and stop the video during teardown. You can continue adding more experiences by following the same pattern.
Experience Base Class | Page 11 of 11 | https://github.com/frankcohen/ReflectionsOS

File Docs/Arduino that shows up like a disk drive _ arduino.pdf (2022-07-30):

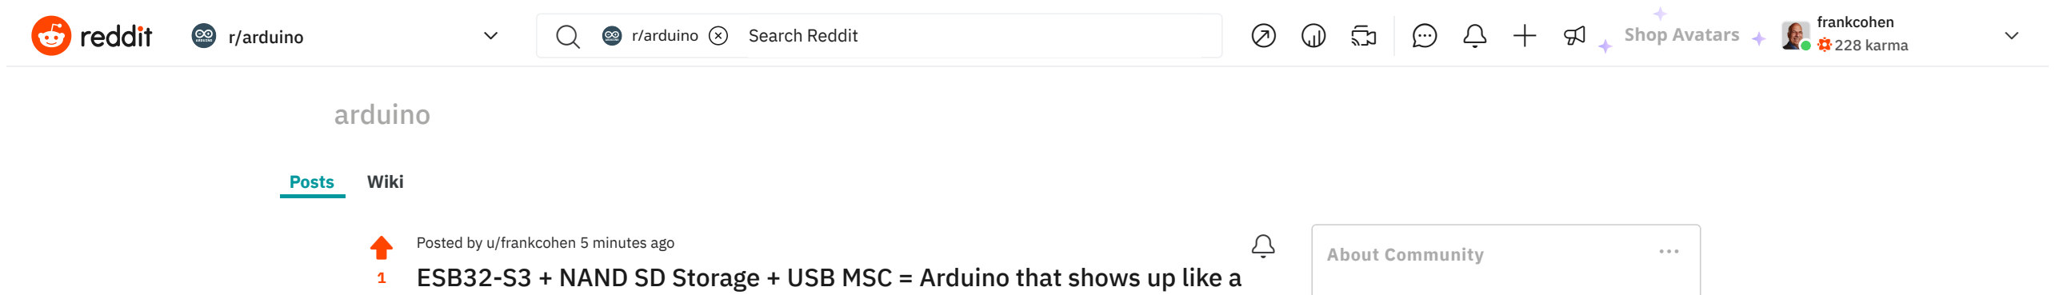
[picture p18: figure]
Posts; Wiki; Posted by u/frankcohen 5 minutes ago; About Community; arduino; frankcohen; r/arduino; Search Reddit; Shop Avatars; 228 karma
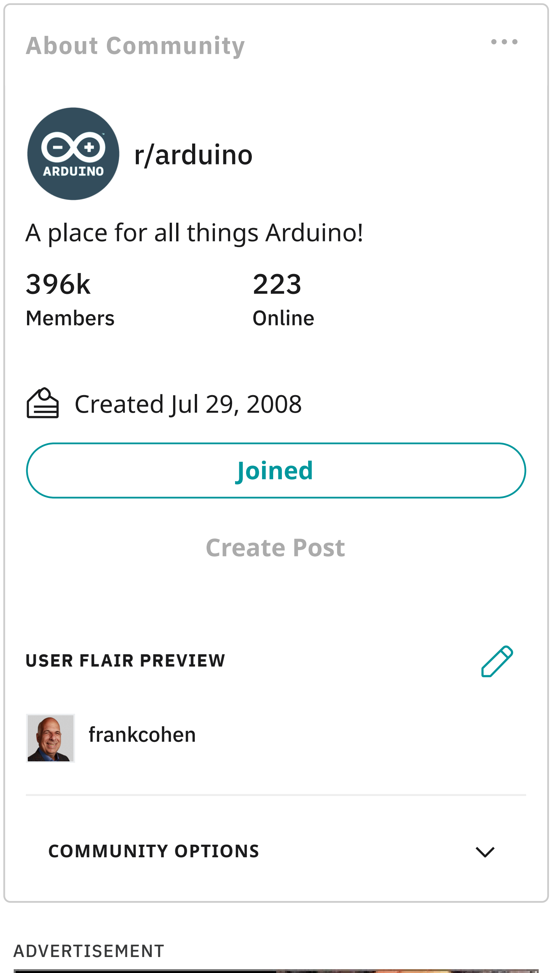
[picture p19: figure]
r/arduino; 396k Members; 223 Online; Created Jul 29, 2008; USER FLAIR PREVIEW; frankcohen; ADVERTISEMENT; A place for all things Arduino!; Joined; Create Post; COMMUNITY OPTIONS

This sketch turns the Reflections main board (an ESP32 with NAND SD storage) into a USB PCMCIA flash mass storage device. Connect the board to the USB port of your Mac or other laptop and the NAND SD card contents appear as a disk drive. Drag-and-drop files into the device from your desktop. Edit files on your Arduino directly from your laptop. Copy over movies, images, fonts, and data.

ESP32 appears as a disk drive

This is something Limor Fried (@LadyAda) and Phillip Torrone (@pt) first demonstrated in 2019 on https://www.youtube.com/watch?v=0bWba0PU4-g Unfortunately, Adafruit_TinyUSB does not compile under the ESP32-S3.

This sketch makes their idea work on an ESP32-S3-Mini-1 with a NAND storage device and USB port connected directly to the ESP32. NAND is a surface mount version of an SD mass storage card. NAND gives gigabytes of storage to your Arduino. ESP32 uses the SPI bus to communicate with the NAND. This sketch uses the TinyUSB library support included in the ESP32 libraries. I distribute this code under a freeGPL v3 Open Source license.

Download the Arduino IDE sketch at https://github.com/frankcohen/ReflectionsOS/tree/main/Devices/Hoober/Software/USB-MSC

## ESB32-S3 + NAND SD Storage + USB MSC = Arduino that shows up like a disk drive

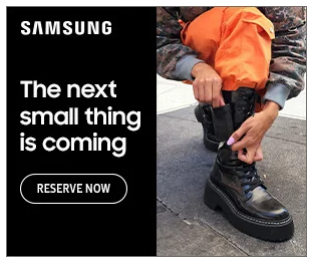
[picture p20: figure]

r/arduino Rules

1.Be Kind |
2.Be Descriptive |
3.Be Helpful |
4. Grow our Community |

Post Insights
Only you and mods of this community can see this
48
- Total Views

100%

- Upvote Rate

95

- Community Karma

0

- Total Shares

Wiring guide to connect an ESP32, NAND storage to USB

See the Reflections Wiring Guide for details at:

https://github.com/frankcohen/ReflectionsOS/blob/main/Devices/Hoober/Software/USB-MSC/USB- MSC-Wiring-Guide.jpg

When uploading this in Arduino IDE these need selection in the Tools drop-down menu:

USB Mode: USB-OTG
USB CDC On Boot: Enabled
USB Firmware MSC On Boot: Disabled
USB DFU On Boot: Disabled

Depends on:

SdFat https://github.com/adafruit/SdFat
ESP32 TinyUSB implementation (USBMSC, USB) part of the Arduino IDE hardware library

Built from examples:

https://github.com/adafruit/Adafruit_TinyUSB_Arduino/blob/master/examples/MassStorage/msc_external_flash_sdcard/msc_external_flash_sdcard.ino (https://github.com/adafruit/Adafruit_TinyUSB_Arduino/blob/master/examples/MassStorage/msc_external_flash_sdcard/msc_external_flash_sdcard.ino)

About Reflections:

What started as a project to wear videos of my children as they grew up on my arm as a wristwatch, grew to be a platform for making entertaining experiences. This is one of the software components. It runs on an ESP32-based platform with TFT OLED display, audio player, flash memory, GPS, gesture sensor, and accelerometer/compass

Repository is at https://github.com/frankcohen/ReflectionsOS

Includes board wiring directions, server side components, examples, support

-Frank

- 0 Comments | Share | Edit Post | Save | Hide

Ar (https://www.reddit.com/r/all/)duino (https://www.reddit.com/rpan/) Information (https://www.reddit.com/chat)

Beginner Information

Tools / Reference

Related Communities

Moderators

u/shanekeith_ (https://www.reddit.com/user/shanekeith_/) I plug things into things

u/Zouden (https://www.reddit.com/user/Zouden/) tinkerer

u/Machiela (https://www.reddit.com/user/Machiela/) tinkering and drinkering

u/ripred3 (https://www.reddit.com/user/ripred3/) my other dev board is a Porsche 😎

Language Reference (https://www.arduino.cc/reference/en/)

Examples Homepage (http://arduino.cc/en/Tutorial/HomePage)

Arduino Forum (http://arduino.cc/forum/)

Beginner Kits (http://www.reddit.com/r/arduino/search?q=kit&restrict_sr=on)

Parts List (http://www.reddit.com/r/arduino/comments/erdnp/got_an_arduino_uno_for_christmas_but/c1abg6g)

Online/Text Resources (http://www.reddit.com/r/arduino/comments/ezlzb/whats_the_best_book_or_website_for_absolute/)

Tutorials (http://redd.it/fhdsd)

Wokwi Arduino Simulator✨ (https://wokwi.com/)

Online Circuit Simulator (http://www.falstad.com/circuit/)

Component Search (http://octopart.com/)

Eagle PCB Design (http://www.cadsoftusa.com/downloads/freeware/)

Arduino Project Hub (https://create.arduino.cc/projecthub)

Arduino Create (https://create.arduino.cc/)

r/ECE (https://www.reddit.com/r/ECE/)
119,359 members

Join

r/electronics (https://www.reddit.com/r/electronics/)
382,920 members

Joined

r/ArduinoProjects (https://www.reddit.com/r/ArduinoProjects/)
71,926 members

Join

- Message the mods (https://www.reddit.com/message/compose?to=/r/arduino)

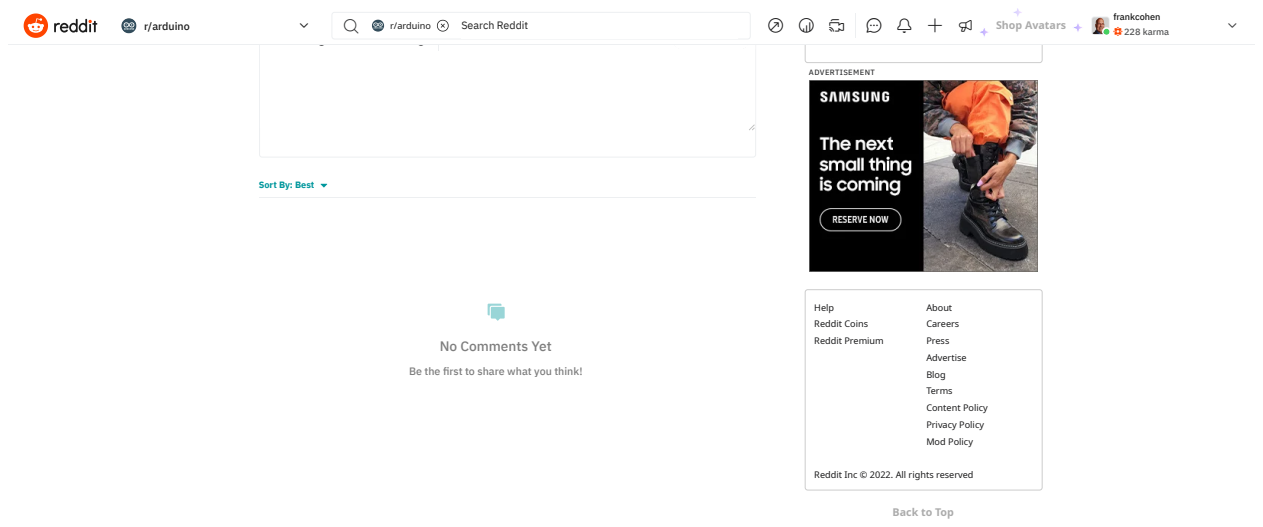
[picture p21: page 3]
Be the fi; rst to share what you think!; ADVERTISEMENT; Help; Reddit Coins; Reddit Premium; About; Careers; Press; Advertise; Blog; Terms; Content Policy; Privacy Policy; Mod Policy; What areyourthoughts?; Markdown Mode

u/gm310509 (https://www.reddit.com/user/gm310509/) Are we there yet?

Comment as frankcohen (https://www.reddit.com/user/frankcohen/)

VIEW ALL MODERATORS (https://www.reddit.com/r/arduino/about/moderators/)

Sort By: Best

No Comments Yet

Reddit Inc © 2022. All rights reserved

Back to Top

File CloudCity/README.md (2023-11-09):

# Cloud City

Cloud City are the server-side services to support the Reflections mobile entertainment experiences. 

## Recorder

Reflections Recorder records video and audio using WebRTC in a browser window, uploads it to a server over HTTPS, processes the video into 240x240 mjpeg movie and audio formats, packs the video and audio into a TAR file, and downloads the TAR to a Reflections board over Wifi to play.

Read the [Reflections Recorder Operations Notes](https://github.com/frankcohen/ReflectionsOS/blob/main/CloudCity/Recorder/README.md)
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

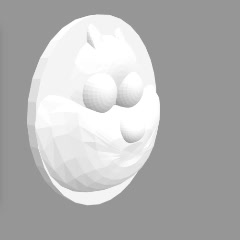
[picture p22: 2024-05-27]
Experiments/Parallax 3D Wallpaper/parallax_cat_face_240x240/cat6_parallax_baseline.jpg

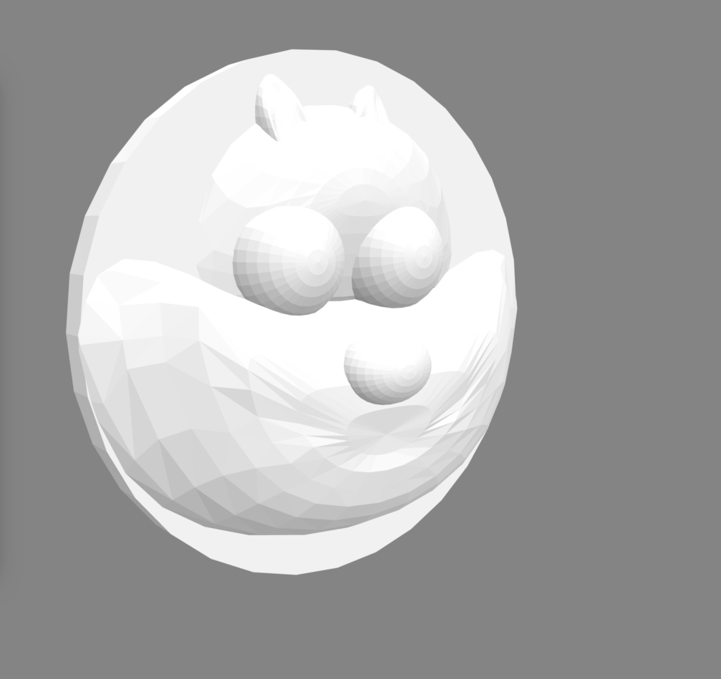
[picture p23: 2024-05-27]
Experiments/Parallax 3D Wallpaper/parallax_cat_face/cat5.jpg

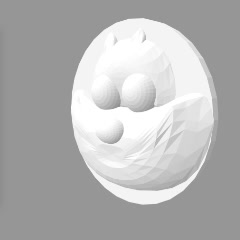
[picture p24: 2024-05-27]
Experiments/Parallax 3D Wallpaper/parallax_cat_face_240x240/cat2_parallax_baseline.jpg

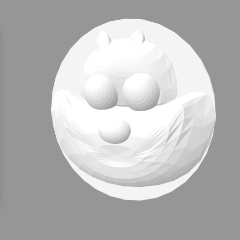
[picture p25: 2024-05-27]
Experiments/Parallax 3D Wallpaper/parallax_cat_face_240x240/cat3_parallax.jpg

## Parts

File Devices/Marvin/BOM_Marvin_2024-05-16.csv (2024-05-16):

ID | Name | Designator | Footprint | Quantity | Manufacturer Part | Manufacturer | Supplier | Supplier Part | Price
1 | DMG3415UQ-7 | Q4,Q3,Q1,Q2 | SOT-23-3_L2.9-W1.6-P1.90-LS2.8-BR-CW | 4 | DMG3415UQ-7 | DIODES(美台) | LCSC | C459537 | 0.202
2 | 100KΩ | R25,R15,R5,R13 | R0402 | 4 | RC0402FR-07100KL | YAGEO | LCSC | C60491 | 0.001
3 | 100Ω | R35,R32,R12 | R0402 | 3 | RMC04021005%N |  | LCSC | C325391 | 0.002
4 | DSR1M | D1 | SOD-123FL_L2.8-W1.8-LS3.7-RD | 1 | DSR1M | High Diode(海德) | LCSC | C466476 | 0.013
5 | 1uF | C14,C8,C16,C25,C26,C6,C3,C5,C4,C1 | C0402 | 10 | GRT155R70J105KE01D | muRata(村田) | LCSC | C711581 | 0.016
6 | XTSD01GLGEAG | U11 | LGA-8_L6.0-W8.0-P1.27-BL | 1 | XTSD01GLGEAG | XTX | LCSC | C558837 | 2.619
7 | 100Ω | R4,R8,R21,R23,R9,R26,R28 | R0201 | 7 | RC0201FR-07100RL | YAGEO | LCSC | C77623 | 0.001
8 | AP2112K-3.3TRG1 | U4 | SOT-25-5_L2.9-W1.6-P0.95-LS2.8-BL | 1 | AP2112K-3.3TRG1 | DIODES(美台) | LCSC | C51118 | 0.072
9 | 10uF | C2,C9,C23,C13 | C0402 | 4 | CL05A106MQ5NUNC | SAMSUNG(三星) | LCSC | C15525 | 0.005
10 | BDFN2C051V40 | D2 | DFN-SMD_L1.0-W0.6-BI | 1 | BDFN2C051V40 | BORN(伯恩半导体) | LCSC | C152023 | 0.032
11 | DRV2605LDGSR | U6 | VSSOP-10_L3.0-W3.0-P0.50-LS4.9-BL | 1 | DRV2605LDGSR | Texas Instruments | LCSC | C527464 | 1.382
12 | 2.2uF | C24 | C0402 | 1 | GRM155R61A225KE95D | MuRata | LCSC | C77002 | 0.006
13 | MAX98357AETE+T | U15 | TQFN-16_L3.0-W3.0-P0.50-BL-EP1.5 | 1 | MAX98357AETE+T | MAXIM(美信) | LCSC | C910544 | 1.592
14 | 10K | R24,R20,R16 | R0402 | 3 | AECR0402F10K0K9 | ResistorToday | LCSC | C328298 | 0.004
15 | 20Ω | R30,R29 | R0201 | 2 |  |  | LCSC | C226464 | 0.002
16 | 20Ω | R11 | R0201 | 1 | AC0201FR-0720RL |  | LCSC | C226464 | 0.002
17 | LIS3DHTR_C15134 | U8 | LGA-16_L3.0-W3.0-P0.50-TL | 1 | LIS3DHTR | ST(意法半导体) | LCSC | C15134 | 0.578
18 | ESP32-S3-MINI-1-CUSTOM | U1 | XCVR_ESP32-S3-MINI-1-N8-CUSTOM | 1 | ESP32-S3-MINI-1-N8 |  | LCSC | C2913206 | 3.923
19 | MMC5603NJ | U5 | FLIPCHIP-4_L0.8-W0.8-R2-C2-P0.40-TL | 1 | MMC5603NJ | MEMSIC(美新) | LCSC | C404328 | 0.33
20 | 1kΩ | R19,R18 | R0402 | 2 | 0402WGJ0102TCE | UNI-ROYAL(厚声) | LCSC | C25543
21 | VL53L5CXV0GC/1 | U7 | LGA-16_L6.4-W3.0_VL53L5CXV0GC-1 | 1 | VL53L5CXV0GC/1 | ST(意法半导体) | LCSC | C3178303 | 8.287
22 | 10KΩ | R31,R22,R27,R1 | R0402 | 4 | RNCF0402BTE10K0 | Stackpole Elec | LCSC | C346559 | 0.085
23 | 100K | R33 | R0402 | 1 | RC0402FR-07100KL | YAGEO | LCSC | C60491 | 0.001
24 | NO FIT | H2 | SMD_PAD_6PIN | 1
25 | 009176002884906 | BAT,HAPTIC | SMD_PAD_2PIN | 2
26 | USB-310CB | USB1 | USB-C-SMD_20P-P0.50-L6.5-W11.2 | 1 | USB-310CB | HOOYA | LCSC | C309373 | 0.455
27 | SW151008-1 | AUDIO | SPEAKER_15X6MM | 1 | SW151008-1 | DB Unlimited | Digi-Key | 2104-SW151008-1-ND
28 | 30k | R2 | R0402 | 1 | RC0402FR-0730KL | Yageo | LCSC | C138008 | 0.001
29 | 6.8K | R34 | R0402 | 1 | HPCR0402F6K80K9 | ResistorToday | LCSC | C365045 | 0.004
30 | ESD0521C | D3,D4 | RCLAMP4021ZATFT | 2 | ESD0521C | Leiditech | LCSC | C490605 | 0.036
31 | XL-1608SURC-06 | LED1 | LED0603-RD_RED | 1 | XL-1608SURC-06 | XINGLIGHT(成兴光) | LCSC | C965799 | 0.003
32 | MCP73831T-2ACI/OT | U10 | SOT-23-5_L3.0-W1.7-P0.95-LS2.8-BL | 1 | MCP73831T-2ACI/OT | MICROCHIP(美国微芯) | LCSC | C424093 | 0.683
33 | 5.1kΩ | R7,R17 | R0201 | 2 | RC0201FR-075K1L | Yageo | LCSC | C274341 | 0.001
34 | F0501-T-10-20T-R | DISPLAY | FPC-SMD_F0501-T-10-20T-R | 1 | F0501-T-10-20T-R | XFCN(兴飞) | LCSC | C481225 | 0.093
35 | ATGM336H-5N31 | U14 | GPSM-SMD_ATGM336H-TR | 1 | ATGM336H-5N31 | ZHONGKEWEI | LCSC | C90770 | 2.728
36 | KH-IPEX-K501-29 | RF2 | ANT-SMD_KH-IPEX-K501-29 | 1 | KH-IPEX-K501-29 | Shenzhen Kinghelm Elec | LCSC | C411563 | 0.064
37 | AT2659 | U2 | DFN-6_L1.6-W1.0-P0.55-BL | 1 | AT2659 | 杭州中科微 | LCSC | C92450 | 0.095
38 | 6.8nH | L2 | L0201 | 1 | LQP03HQ6N8H02D | Murata | LCSC | C237385 | 0.045
39 | 470pF | C7 | C0201 | 1 | 0201B471K500NT | FH | LCSC | C55020 | 0.001
40 | 330Ω | R14 | R0201 | 1 | 0201WMJ0331TEE | UNI-ROYAL(Uniroyal Elec) | LCSC | C473445 | 0.001
41 | 47nH | L1 | L0201 | 1 | LQP03TN47NH02D | Murata | LCSC | C162618 | 0.011
42 | 6.8kΩ | R3 | R0402 | 1 | AECR0402F6K80K9 | ResistorToday | LCSC | C352396 | 0.004
43 | SKTDLHE010 | B2,B1 | KEY-SMD_SKTDLHE010 | 2 | SKTDLHE010 | ALPS Electric | LCSC | C380198 | 0.136
44 | 2kΩ | R6,R10 | R0402 | 2 | RC0402FR-072KL | Yageo | LCSC | C60488 | 0.001

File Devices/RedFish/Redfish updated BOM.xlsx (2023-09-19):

PCBWay Bom Quotation, Product No.:T-F39W356416A
Item # | *Designator | *Qty | Manufacturer | *Mfg Part # | Description / Value | Vendor Part # | *Package/Footprint | *Unit Price(5 sets) | *Total | *Delivery Time | *Actual Purchase Mfg Part # | *PCBWay Note | Customer Reply | PCBWay Update
1 | AUDIO,BATTERY,HAPTIC | 3 |  | 9176002884906 | 9176002884906 |  | 9176002884906 | $0.768 | $11.520 | 7-10 Workdays | 009176002884906 |  | This is the correct part. It is available at https://www.digikey.com/en/products/detail/kyocera-avx/009176002884906/9658714 too. It is a Kyocera part, should be available in China.
2 | B1,B2 | 2 | ALPS Electric | SKTDLHE010 | SKTDLHE010 | C380198 | KEY-SMD_SKTDLHE010 | $0.182 | $1.820
3 | C1,C4,C6,C14,C16,C25,C26 | 7 | muRata(村田) | GRT155R70J105KE01D | 1uF | C711581 | C0402 | $0.037 | $1.295
4 | C2,C9,C13,C23 | 4 | SAMSUNG(三星) | CL05A106MQ5NUNZ | 10uF | C2839440 | C0402 | $0.022 | $0.440
5 | C7 | 1 | FH | 0201B471K500NT | 470pF | C55020 | C0201 | $0.042 | $0.210
6 | C8 | 1 | SANYEAR | C0201X5R105M6R3NT | 1uF | C466604 | C0201 | $0.101 | $0.505
7 | C24 | 1 | MuRata | GRM155R61A225KE95D | 2.2uF | C77002 | C0402 | $0.126 | $0.630
8 | D1 | 1 | High Diode(海德) | DSR1M | DSR1M_C466476 | C466476 | SOD-123FL_L2.8-W1.8-LS3.7-RD | $0.173 | $0.865
9 | D2 | 1 | BORN(伯恩半导体) | BDFN2C051V40 | BDFN2C051V40 | C152023 | DFN-SMD_L1.0-W0.6-BI | $0.184 | $0.920
10 | D3,D4 | 2 |  | RCLAMP4041ZATFT | RCLAMP4041ZATFT |  | RCLAMP4021ZATFT | $0.220 | $2.200 | 7-10 Workdays |  |  | This is the correct part. It is available at https://www.digikey.com/en/products/detail/semtech-corporation/RCLAMP4041ZATFT/16212720 There should be available in China.
11 | DISPLAY | 1 | XFCN(兴飞) | F0501-T-10-20T-R | F0501-T-10-20T-R | C481225 | FPC-SMD_F0501-T-10-20T-R | $0.133 | $0.665
12 | FPC3 | 1 | XUNPU(讯普) | FPC-05F-6PH20 | FPC-05F-6PH20 | C2856796 | FPC-SMD_6P-P0.50_XUNPU_FPC-05F-6PH20 | $0.106 | $0.530
13 | H2 | 1 | XKB Connectivity(中国星坤) | X1321FVS-2x03-C43D48 | X1321FVS-2X03-C43D48 | C2684731 | HDR-SMD_6P-P1.27-V-F-R2-C3-LS4.8 | $0.317 | $1.585
14 | L1,L2 | 2 | TDK | MLG0603P47NHT000 | 47nH | C433019 | L0201 | $0.014 | $0.140
15 | LED1 | 1 | XINGLIGHT(成兴光) | XL-1608SURC-06 | XL-1608SURC-06 | C965799 | LED0603-RD_RED | $0.073 | $0.365
16 | Q1 | 1 | TECH PUBLIC(台舟) | FDN340P | FDN340P_C2890122 | C2890122 | SOT-23-3_L2.9-W1.3-P1.90-LS2.4-BR | $0.154 | $0.770
17 | Q2,Q3,Q4 | 3 | TECH PUBLIC(台舟) | FDN340P | FDN340P | C2890122 | SOT-23-3_L2.9-W1.3-P1.90-LS2.4-BR | $0.103 | $1.545
18 | R1,R22,R27,R31 | 4 | Stackpole Elec | RNCF0402BTE10K0 | 10KΩ | C346559 | R0402 | $0.339 | $6.780 | 7-10 Workdays |  |  | This shows in-stock at https://jlcpcb.com/parts/componentSearch?searchTxt=RNCF0402BTE10K0
19 | R2 | 1 | Susumu | RR0510P-303-D | 30k | 754-RR0510P-303D | R0402 | $0.139 | $0.695
20 | R3 | 1 | ResistorToday | AECR0402F6K80K9 | 6.8kΩ | C352396 | R0402 | $0.132 | $0.660
21 | R4,R8,R9,R21,R23,R26,R28 | 7 | YAGEO | AF0201JR-0782RL | 82Ω | C144030 | R0201 | $0.003 | $0.105
22 | R5,R15 | 2 |  | SCR0402F10K7 | 10.7K | C3015977 | R0402 | $0.006 | $0.060
23 | R6 | 1 | Uniroyal Elec | 0201WMF2001TEE | 2kΩ | C270358 | R0201 | $0.084 | $0.420
24 | R7,R17 | 2 | UNI-ROYAL(Uniroyal Elec) | NQ01WMJ0562TEE | 5.6kΩ | C965305 | R0201 | $0.014 | $0.140
25 | R10 | 1 | Multicomp | MCWR04X1820FTL | 182Ω | C241158 | R0402 | $0.015 | $0.075
26 | R11 | 1 |  | AC0201FR-0720RL | 20Ω | C226464 | R0201 | $0.045 | $0.225
27 | R12,R32 | 2 |  | RMC04021005%N | 100Ω | C325391 | R0402 | $0.021 | $0.210
28 | R13 | 1 | YAGEO | RC0402FR-07100KL | 100KΩ | C60491 | R0402 | $0.013 | $0.065
29 | R14 | 1 | UNI-ROYAL(Uniroyal Elec) | 0201WMJ0331TEE | 330Ω | C473445 | R0201 | $0.016 | $0.080
30 | R16,R20,R24 | 3 | ResistorToday | AECR0402F10K0K9 | 10K | C328298 | R0402 | $0.033 | $0.495
31 | R18,R19 | 2 | UNI-ROYAL(厚声) | 0402WGJ0102TCE | 1kΩ | C25543 | R0402 | $0.005 | $0.050
32 | R29,R30 | 2 |  | AC0201FR-0720RL | 20Ω | C226464 | R0201 | $0.022 | $0.220
33 | R33 | 1 | YAGEO | RC0402FR-07100KL | 100K | C60491 | R0402 | $0.013 | $0.065
34 | R34 | 1 | ResistorToday | HPCR0402F6K80K9 | 6.8K | C365045 | R0402 | $0.116 | $0.580
35 | RF2 | 1 | Shenzhen Kinghelm Elec | KH-IPEX-K501-29 | KH-IPEX-K501-29 | C411563 | ANT-SMD_KH-IPEX-K501-29 | $0.091 | $0.455
36 | U1 | 1 |  | ESP32-S3-MINI-1-CUSTOM | ESP32-S3-MINI-1-CUSTOM |  | XCVR_ESP32-S3-MINI-1-N8-CUSTOM |  |  |  |  | Pls provide the correct part number. | ESP32-S3-MINI-1-N8
37 | U3 | 1 | XTX | XTSD01GLGEAG | XTSD01GLGEAG | C558837 | LGA-8_L6.0-W8.0-P1.27-BL | $2.142 | $10.710
38 | U4 | 1 | Diodes Incorporated | AZ1117CR2-3.3TRG1 | AZ1117CR2-3.3TRG1 | 31-AZ1117CR2-3.3TRG1CT-ND - Cut Tape (CT) | SOT-89-3_L4.5-W2.5-P1.50-LS4.2-BR | $0.273 | $1.365
39 | U5 | 1 | MEMSIC(美新) | MMC5603NJ | MMC5603NJ | C404328 | FLIPCHIP-4_L0.8-W0.8-R2-C2-P0.40-TL | $0.326 | $1.630
40 | U6 | 1 | Texas Instruments | DRV2605LDGSR | DRV2605LDGSR | C527464 | VSSOP-10_L3.0-W3.0-P0.50-LS4.9-BL | $1.743 | $8.715
41 | U7 | 1 | ResistorToday | HPCR0402F680RK9 | 680 | C365041 | R0402 | $0.116 | $0.580
42 | U8 | 1 | ST(意法半导体) | LIS3DHTR | LIS3DHTR_C15134 | C15134 | LGA-16_L3.0-W3.0-P0.50-TL | $0.420 | $2.100
43 | U10 | 1 | Torex Semiconductor Ltd | XC6802A42XMR-G | XC6802A42XMR-G | 893-1145-1-ND | SOT-25-5_L3.0-W1.8-P0.95-LS3.0-BL | $0.333 | $1.665
44 | U14 | 1 | ZHONGKEWEI | ATGM336H-5N31 | ATGM336H-5N31 | C90770 | GPSM-SMD_ATGM336H-TR | $3.352 | $16.760
45 | U15 | 1 | MAXIM(美信) | MAX98357AETE+T | MAX98357AETE+T | C910544 | TQFN-16_L3.0-W3.0-P0.50-BL-EP1.5 | $0.697 | $3.485
46 | USB1 | 1 | HOOYA | USB-310CB | USB-310CB | C309373 | USB-C-SMD_20P-P0.50-L6.5-W11.2 | $0.496 | $2.480
 |  |  |  |  |  |  |  | Component Cost | $86.88
 |  |  |  |  |  |  |  | Assembly Cost | $30.00
 |  |  |  |  |  |  |  | PCB Cost | $31.36
 |  |  |  |  |  |  |  | V3 Member 3% off | -$1.84
 |  |  |  |  |  |  |  | All Total 5 Sets | $146.39

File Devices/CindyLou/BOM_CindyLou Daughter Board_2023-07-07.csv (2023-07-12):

ID | Name | Designator | Footprint | Quantity | Manufacturer Part | Manufacturer | Supplier | Supplier Part | Price
1 | 1uF | C2 | C0201 | 1 | 02016D105KAT4A | Kyocera AVX | Mouser | 581-02016D105KAT4A
2 | VL53L5CX | U1 | VL53L5CX | 1 |  | ST | Digi-Key | https://www.digikey.com/en/products/detail/stmicroelectronics/VL53L5CXV0GC-1/14552424?Enterprise=44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

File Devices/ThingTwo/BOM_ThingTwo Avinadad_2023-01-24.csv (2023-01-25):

ID | Name | Designator | Footprint | Quantity | Manufacturer Part | Manufacturer | Supplier | Supplier Part | Price
1 | Reset Button | B1 | EVP-ATAL1B000 | 1
2 | Boot Button | B2 | EVP-ATAL1B000 | 1
3 | 1uF | C1,C4,C6,C14,C16,C25,C26 | C0402 | 7 | GRT155R70J105KE01D | muRata(村田) | LCSC | C711581 | 0.003
4 | 10uF | C2,C3,C13,C23 | C0402 | 4 | CL05A106MQ5NUNZ | SAMSUNG(三星) | LCSC | C2839440 | 0.001
5 | 470pF | C7 | C0201 | 1 | 0201B471K500NT | FH | LCSC | C55020
6 | 1uF | C8 | C0201 | 1 | C0201X5R105M6R3NT | SANYEAR | LCSC | C466604 | 0.001
7 | 2.2uF | C24 | C0402 | 1 | GRM155R61A225KE95D | MuRata | LCSC | C77002 | 0.001
8 | FPC-05F-12PH20-CUSTOM | FPC1 | FPC-SMD_12P-P0.50_FPC-05F-12PH20-CUSTOM | 1 | FPC-05F-12PH20 | XUNPU(讯普) | LCSC | C2856799 | 0.014
9 | Header-Male-2.54_1x4 | H1 | HDR-TH_4P-P2.54-V-M | 1 | 210S-1*4P L=11.6MMGold-plated black | Ckmtw | LCSC | C124378 | 0.007
10 | DF65-3P-1.7V_21_ | J1 | DF65-3P-1.7V(21) | 1
11 | DF65-5P | J2 | DF65-5P | 1
12 | 47nH | L1,L2 | L0201 | 2 | MLG0603P47NHT000 | TDK | LCSC | C433019 | 0.001
13 | XL-1608SURC-06 | LED1 | LED0603-RD_RED | 1 | XL-1608SURC-06 | XINGLIGHT(成兴光) | LCSC | C965799 | 0.001
14 | FDN340P_C2890122 | Q1 | SOT-23-3_L2.9-W1.3-P1.90-LS2.4-BR | 1 | FDN340P | TECH PUBLIC(台舟) | LCSC | C2890122 | 0.01
15 | FDN340P | Q2 | SOT-23-3_L2.9-W1.3-P1.90-LS2.4-BR | 1 | FDN340P | TECH PUBLIC(台舟) | LCSC | C2890122 | 0.01
16 | 10KΩ | R1,R27 | R0402 | 2 | RNCF0402BTE10K0 | Stackpole Elec | LCSC | C346559 | 0.016
17 | 30k | R2 | R0402 | 1 | RR0510P-303-D | Susumu | Mouser | 754-RR0510P-303D
18 | 6.8kΩ | R3 | R0402 | 1 | AECR0402F6K80K9 | ResistorToday | LCSC | C352396 | 0.001
19 | 82Ω | R4,R8,R9,R21,R23,R26,R28 | R0201 | 7 | AF0201JR-0782RL | YAGEO | LCSC | C144030 | 0.001
20 | 10K | R5,R16,R20,R24 | R0402 | 4 | AECR0402F10K0K9 | ResistorToday | LCSC | C328298 | 0.001
21 | 2kΩ | R6 | R0201 | 1 | 0201WMF2001TEE | Uniroyal Elec | LCSC | C270358
22 | 5.6kΩ | R7,R17 | R0201 | 2 | NQ01WMJ0562TEE | UNI-ROYAL(Uniroyal Elec) | LCSC | C965305
23 | 182Ω | R10 | R0402 | 1 | MCWR04X1820FTL | Multicomp | LCSC | C241158
24 | 20Ω | R11,R29,R30 | R0201 | 3 | RC0201FR-0720RL | YAGEO | LCSC | C155742
25 | 5.6KΩ | R12,R32 | R0402 | 2 | 0402WGD5601TCE | Uniroyal Elec | LCSC | C423273 | 0.001
26 | 100KΩ | R13 | R0402 | 1 | RC0402FR-07100KL | YAGEO | LCSC | C60491
27 | 330Ω | R14 | R0201 | 1 | 0201WMJ0331TEE | UNI-ROYAL(Uniroyal Elec) | LCSC | C473445
28 | 510 | R15 | R0402 | 1 | RC0402JR-07510RL | YAGEO | LCSC | C137860
29 | 4K7 | R18,R19 | R0402 | 2 | ERJ-U02F1502X | Panasonic | Mouser | 667-ERJ-U02F1502X
30 | DNP | R22 | R0201 | 1 | DNP | DNP | LCSC | DNP
31 | 100Ω | R25 | R0402 | 1 | PTFR0402B100RN9 | ResistorToday | LCSC | C328416 | 0.015
32 | DNP | R31 | R0402 | 1 | PTFR0402B47K0P9 | Resistor.Today | LCSC | C478873 | 0.01
33 | 100K | R33 | R0402 | 1 | RC0402FR-07100KL | YAGEO | LCSC | C60491
34 | 6.8K | R34 | R0402 | 1 | HPCR0402F6K80K9 | ResistorToday | LCSC | C365045 | 0.001
35 | KH-IPEX-K501-29 | RF2 | ANT-SMD_KH-IPEX-K501-29 | 1 | KH-IPEX-K501-29 | Shenzhen Kinghelm Elec | LCSC | C411563 | 0.011
36 | ESP32-S3-MINI-1-CUSTOM | U1 | XCVR_ESP32-S3-MINI-1-N8-CUSTOM | 1
37 | LIS331DLHTR | U2 | LGA-16_L3.0-W3.0-P0.50-TL | 1 | LIS331DLHTR | null | LCSC | C2887983 | 1.949
38 | XTSD01GLGEAG | U3 | LGA-8_L6.0-W8.0-P1.27-BL | 1 | XTSD01GLGEAG | XTX | LCSC | C558837 | 0.484
39 | MD7671A33PA1 | U4 | SOT-89-3_L4.5-W2.5-P1.50-LS4.2-BR | 1 | MD7671A33PA1 | 明达微 | LCSC | C920513 | 0.042
40 | DRV2605LDGSR | U6 | VSSOP-10_L3.0-W3.0-P0.50-LS4.9-BL | 1 | DRV2605LDGSR | Texas Instruments | LCSC | C527464 | 0.471
41 | TPS2113APW | U9 | TSSOP-8_L4.4-W3.0-P0.65-LS6.4-TL | 1 | TPS2113APW | TI(德州仪器) | LCSC | C2861975 | 0.817
42 | TP4057_C725791 | U10 | SOT-23-6_L2.9-W1.6-P0.95-LS2.8-BR | 1 | TP4057 | UMW(Youtai Semiconductor Co., Ltd.) | LCSC | C725791 | 0.009
43 | MMC5603NJ | U11 | FLIPCHIP-4_L0.8-W0.8-R2-C2-P0.40-TL | 1 | MMC5603NJ | MEMSIC | LCSC | C404328 | 0.064
44 | ATGM336H-5N31 | U14 | GPSM-SMD_ATGM336H-TR | 1 | ATGM336H-5N31 | ZHONGKEWEI | LCSC | C90770 | 0.66
45 | MAX98357AETE+T | U15 | TQFN-16_L3.0-W3.0-P0.50-BL-EP1.5 | 1 | MAX98357AETE+T | MAXIM(美信) | LCSC | C910544 | 0.179
46 | USB-310CB | USB1 | USB-C-SMD_20P-P0.50-L6.5-W11.2 | 1 | USB-310CB | HOOYA | LCSC | C309373 | 0.081

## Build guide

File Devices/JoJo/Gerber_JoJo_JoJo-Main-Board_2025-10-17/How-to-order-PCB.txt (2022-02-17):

How to Order PCB

Please refer to:
https://docs.easyeda.com/en/PCB/Order-PCB

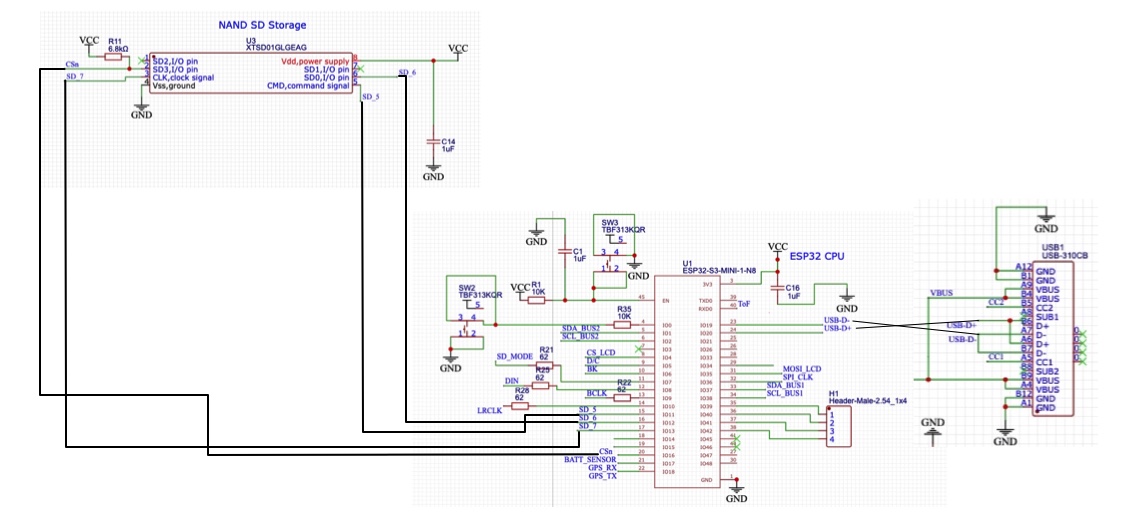
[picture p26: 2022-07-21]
Devices/Hoober/Software/USB-MSC/USB-MSC-Wiring-Guide.jpg

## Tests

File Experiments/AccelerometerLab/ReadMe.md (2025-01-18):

# AccelerometerLab for Gesture Sensing

### by Frank Cohen, fcohen@starlingwatch.com, January 15, 2025

Licensed under GPL v3 Open Source Software
(c) Frank Cohen, All rights reserved. fcohen@starlingwatch.com
Read the license in the license.txt file that comes with this code.

Depends on these libraries:
- Adafruit LIS3DH library, https://github.com/adafruit/Adafruit_LIS3DH
- Adafruit Unified Sensor, https://github.com/adafruit/Adafruit_Sensor
- Adafrruit BusIO, I2C support, https://github.com/adafruit/Adafruit_BusIO
- PeakDetection, peak and valley detection, https://github.com/leandcesar/PeakDetection

Written in support of the Reflections project at:
https://github.com/frankcohen/ReflectionsOS

## Gesture Sensing

Let’s do a technical deep dive into the LIS3DH. Yeah, ok, wait… what?

### Why?

Good makers turn out creations that are scalable, sustainable, rapid, and ethical. That’s SERS. With SERS it’s not up to the human to learn the software, the software needs to understand the intentions of the human. When I move my arm up, you know intuitively what I’m trying to say. Something SERS needs to  understand the intention too.

LIS3DH is an inexpensive 3 Axis accelerometer sensor. It senses movement and acceleration from gravity. I use it to sense gestures in the Reflections open-source mobile entertainment platform for visual controls and to wake the ESP32-S3 processor from deep sleep. It senses movement, taps, clicks, shaking, and acceleration. Many libraries exist and generative AI such as ChatGPT is familiar and generates code for the sensor. 

While working with the sensor I didn’t find answers to a bunch of questions. For example, what are the best sensitivity and gravity values to use with the sensor? I wrote code to experiment with the sensor. I publish this library under an open-source license hoping you will contribute your LIS3DH experiences, tips, and techniques for others to enjoy.

In 10 seconds here’s how it works. The code starts up the sensor, displays the current gravity readings on the x, y, and z axis, shows the magnitude of movements, changes the sensitivity and other inputs through the Arduino IDE Serial Monitor dynamically, and shows 3 strategies to make sense of the readings.

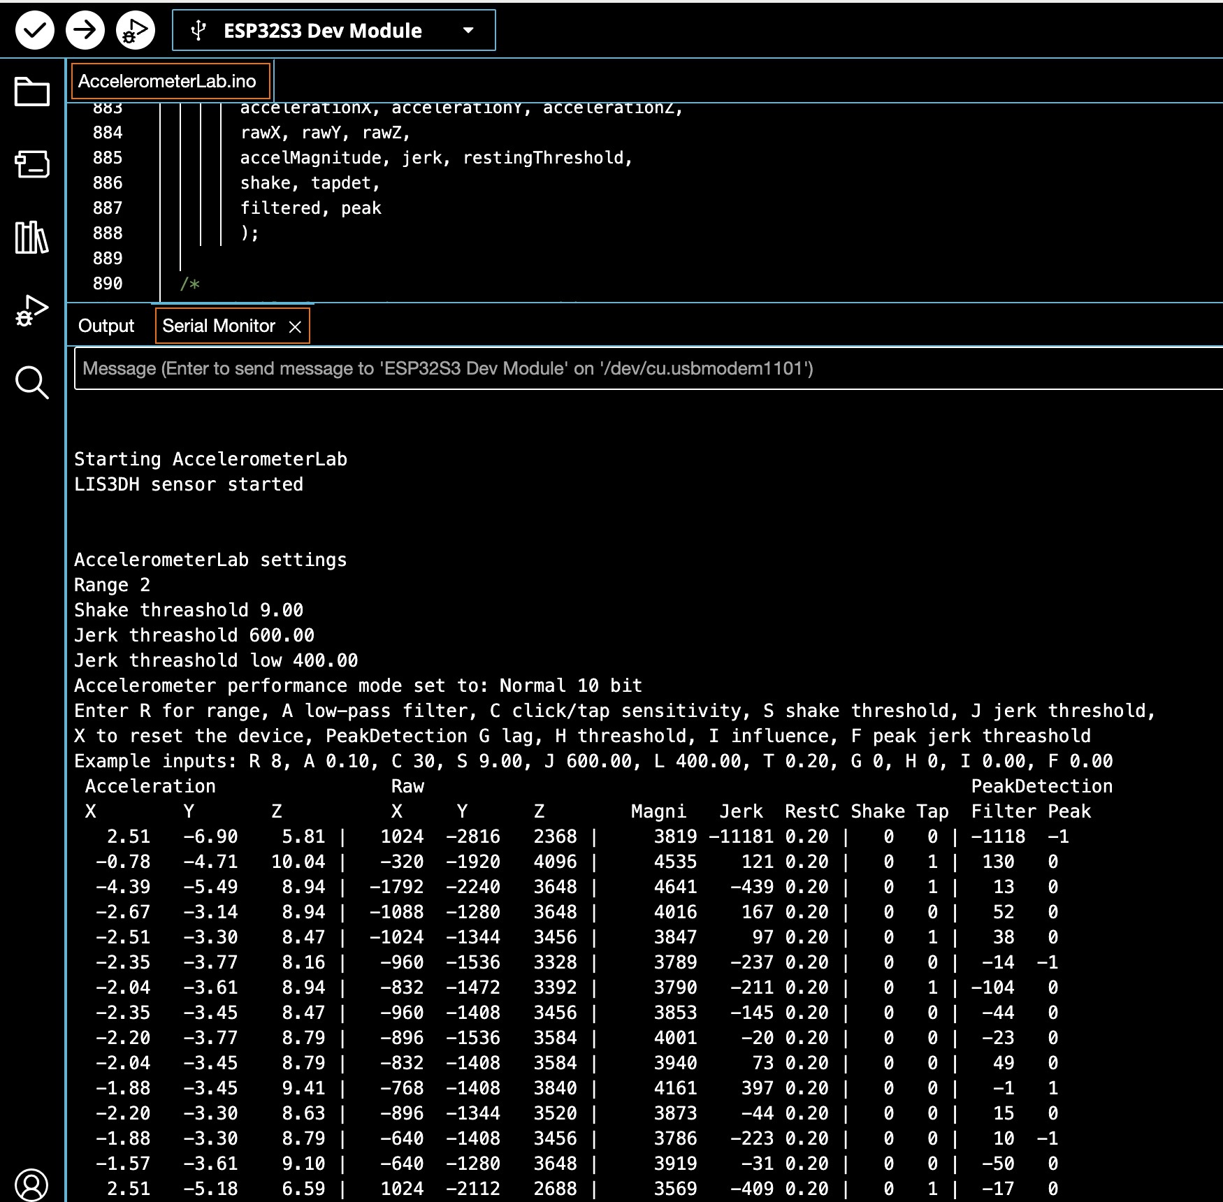
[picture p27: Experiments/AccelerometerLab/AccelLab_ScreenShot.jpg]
AccelerometerLab Screen Shot


### Why 3?

The sensor spits out measurements and the code needs to turn these into understanding. Is the sensor being tapped, clicked, moved to the right or left, shaken? I haven’t found one approach that works for everything. Here’s what I found.

### PeakDetection

Uses a statistical method using standard deviation. I remember the look on my high school mathematics teacher Art when trying to get me to understand stats. This project is his revenge, I should have been paying more attention to you Art!

PeakDetection automatically adapts to the inputs. When I make slight movements at one time and vigorous ones later PeakDectection adapts. The downside is during its adaption it can spit out a bunch of false positive values.

### Simple Range Filtering

Uses a simple high and low level filter to detect expected movement. A lot fewer false positives, and not much flexibility. When I get onto a bouncy bus wearing the sensor the PeakDetection system would be better.

### Hardware Click and Movement Detection

Uses the click detection built into the sensor. LIS3DH detects single and double clicks. It detects general movement along x, y, and z axis’. Hardware detection is nice to have and not all that accurate. Chasing after different sensitivity level settings is not easy. This is the worst approach for false positives.

I like the LIS3DH for its versatility, including basic motion detection, like measuring the orientation of a device, to more advanced applications, like gesture recognition or even building activity tracking systems. It’s tiny in a surface mount 201 package that’s much smaller than the tip of your finger. It has very low power consumption and lets you balance between performance and power consumption. It’s great for battery powered projects. 

### What I Learned

Here are highlights from the experience using LIS3DH:

1) The sensor gives raw values based on gravity from X, Y, and Z axes making it versatile for high-sensitivity applications, like detecting small movements, and for applications that need to measure larger accelerations, like detecting fast motions.

2) Detecting simple gestures like shakes or taps is easy. Complex gestures like sensing when you move Magic 8 Ball up and down are possible. Monitor the accelerometer’s data, triggering an action when detecting a certain pattern of movement.

3) Handling noise is the biggest issue. I added various filtering techniques to smooth the data and remove irrelevant fluctuations. For example, a Kalman filter reduces noise and predicts movement of the accelerometer. We also had success using low-pass filters from data processing. The toughest detection is a single tap, and I wasn’t altogether successful weeding through all the noise.

4) Tracking activity, like when a person is resting, moving, or shaking was easy. Many fitness trackers do this. We were able to infer when someone was still and when they were moving, and even recognize shaking gestures.

I rail pretty hard on the Disney Parks application for not being scalable, sustainable, rapid, and ethical, for not being SERS. And yet there is this little LIS3DH sensor… like the little train that could. The sensor detects when I am standing in Tomorrowland, separate from Fantasyland, and helps software understand my intentions and needs. Imagine how this sensor helps to make my experience even more immersive. If only…

I'm glad to tell you what Clever Moe did for PepsiCo, Wynn Casinos, Best Buy, Rackspace, and many other organizations.

Check out the [Reflections project](https://github.com/frankcohen/ReflectionsOS) for building entertaining IOT based experiences.

Thanks!

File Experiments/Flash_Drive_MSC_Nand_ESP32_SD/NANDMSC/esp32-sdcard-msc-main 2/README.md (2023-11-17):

# Accompanying Video

WiFi Streaming (https://www.youtube.com/watch?v=ocXs1yxsux4)

# ESP32-S3 SD Card Performance Tests - USBMSC and Direct From ESP32

The ESP32-S3 can act as a Mass Storage Class device (USBMSC). This allows us to connect and SD Card to the ESP32 and then access it from a PC.

# SD Card Performance Directly Connected to PC

This is just a baseline to see what the SD Card is actually capable of when connected directly to the SD Card reader of my Mac Book Pro.

| | Average Speed (B/s) | Average Speed (Mbytes/s) |
|---|---|---|
| **Write** | 27,297,357 | 26.03 |
| **Read**  | 94,395,970 | 90.02 |

# ESP32 <-> SD Card Performance

This test write 100MB of raw sectors to the SD Card and then reads it back. Enable this mode ny uncommenting the line in `main.cpp`

```cpp
// #define SD_CARD_SPEED_TEST
```

All values are in MBytes/s

| Operation | 1Bit SPI 20 MHz  | 4Bit SDIO 40 MHz |
| --- | --- | --- |
| Write | 1.01 | 2.34 |
| Read | 1.67 | 8.39 |

# USB <-> ESP32 <-> SD Card: Using USBMSC

There are three different configurations in this repo. The basic Arduino code uses the SD class to connect to the SD Card using SPI. This only exposes methods for writing/reading one sector at a time which has a considerable amount of overhead. Using IDF code we can write/read multiple sectors at once. And if we move writing to the SD Card to a background task we can get even better performance - but this comes at the cost of no error handling...

You can switch between these different modes by changing the class used for the SDCard

```cpp
#ifdef USE_SDIO
  card = new SDCardLazyWrite(Serial, "/sd", SD_CARD_CLK, SD_CARD_CMD, SD_CARD_DAT0, SD_CARD_DAT1, SD_CARD_DAT2, SD_CARD_DAT3);
#else
  card = new SDCardLazyWrite(Serial, "/sd", SD_CARD_MISO, SD_CARD_MOSI, SD_CARD_CLK, SD_CARD_CS);
#endif
```

You can use the following classes: `SDCardLazyWrite`, `SDCardMultiWrite`, `SDCardArduino` - NOTE - `SDCardArduino` cannot be used in  SDIO mode as the readRAW and writeRAW functions don't exist on the SDMMC class.
 
## Arduino SD Card Code - Single Sector Writing

| Type | SPI 20MHz | 4Bit SDIO 40 MHz |
| --- | --- | --- |
| Write Speed | 0.278 | NA |
| Read Speed  | 0.507 | NA |

## IDF SD Card Code - Multi Sector Writing

| Type | SPI 20MHz | 4Bit SDIO 40 MHz |
| --- | --- |--- |
| Write Speed | 0.481 |0.66 |
| Read Speed  | 0.671 |1.00 |

## IDF SD Card Code - Multi Sector Lazy Writing

| Type | SPI 20MHz | 4Bit SDIO 40 MHz |
| --- | --- | --- |
| Write Speed | 0.915 | 0.92 |
| Read Speed  | 0.672 | 1.00 |

# Summary

Getting up to almost 1MByte/s on both reading and writing is pretty impressive but it probably the best that can be done given the limitations of USB1.1 full speed mode.

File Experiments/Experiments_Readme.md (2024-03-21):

# Reflections Devices ReadMe

Started: October 6, 2023

Updated: March 19, 2024

Reflections is a hardware, software, and server architecture for building mobile entertaining experiences. Experiments is draft code supporting the board components and connectivity to the Cloud City backend.

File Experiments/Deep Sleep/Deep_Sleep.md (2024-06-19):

# ESP32-S3 Deep Sleep

June 18, 2024 fcohen@starlingwatch.com

## Extending Battery Life for ESP32-S3 Projects

I am at a point in development of the [Reflections project](https://github.com/frankcohen/ReflectionsOS) where optimizations to get more battery time are important. Putting the ESP32 and display into deep sleep extends the battery life. This experiment shows the code needed and the pittfalls I encountered.

### Wake On Movement

Reflections board uses an [LIS3DH accelerometer](https://jlcpcb.com/partdetail/STMICROELECTRONICS-LIS3DHHTR/C2655077) to identify movement, taps, and clicks. It uses the ESP32-S3 Real Time Clock (RTC) interrupt pins to wake the processor from deep sleep. I use the [SparkFun LIS3DH](https://github.com/sparkfun/SparkFun_LIS3DH_Arduino_Library) library and Arduino IDE 2.3.2.

I connect the ESP32-S3 and LIS32DH pins:

- GPIO12 to ACC INT1 pin 11
- GPIO13 to ACC INT2 pin 9

### Not all GPIOs are RTC pins, GPIO 14 is not

Originally I connected INT 1 from the accellerometer to GPIO 14. I assumed that all ESP interrupts from from mall GPIO pins. That's wrong according to the datasheet. To make the ESP interrupts work the GPIO needs to be one of the RTC compatible pins. GPIO 14 is not an RTC pin. Just my luck, as GPIO 0 to 21, except for 14, are RTC compatible pins.

Instead, I used GPIO 13 connected to INT 2. That works! However, using INT 2 requires extra configuration of the LIS3DH and that's not easy, as you will see from the code. I found the Adafruit library for LIS3DH doesn't easily support setting the custom parameters needed to use INT 2. I switched to using the Sparkfun library.

*NOTE: I got it wrong, GPIO 14 is an RTC pin. I corrected the code.*

### Retaining Values in Deep Sleep

Deep sleep on ESP32 powers down everything (RAM, registers, etc.). I found this in the [datasheet](https://www.mouser.com/pdfdocs/esp-idf.pdf) "To retain the value of the wakecount variable across deep sleep cycles, you need to store it in a non-volatile memory area that persists through resets and power cycles. The ESP32 provides a feature called "RTC memory" that can be used for this purpose."

For example,

```
RTC_DATA_ATTR int wakecount;
```

creates wakecount in the RTC area of memory. Everything else gets reset during deep sleep.

### Setup and Loop and Waking-up

The first time a sketch runs it processes Setup() as expected from an Arduino sketch. Then it continually processes Loop().

```
void setup() 
{
  Serial.begin(115200);
  delay(1000); // Wait for serial monitor to open
  Serial.println("starting");
```
Once the ESP32-S3 wakes from a deep-sleep it has an option to process the Setup() differently.

```
void setup() 
{
  Serial.begin(115200);
  delay(1000); // Wait for serial monitor to open
  Serial.println("starting");

  esp_sleep_wakeup_cause_t wakeup_reason = esp_sleep_get_wakeup_cause();

  if ( wakeup_reason == ESP_SLEEP_WAKEUP_EXT1 ) 
  {
  	// Setup options from waking from deep sleep go here
  
  }
  else
  {
  	// Cold start setup options go here
	
  }
```

### LIS3DH INT 2 Configuration

Configuring LIS3DH for using INT2 takes a lot of code - this is crazy. Most of this comes from the Sparkfun LIS3DH library examples.

```
  Wire.begin(I2CSDA, I2CSCL);  // Initialize I2C bus
  
  if (myIMU.begin() != 0) {
    Serial.println("Could not start LIS3DH");
    while (1);
  }

  myIMU.settings.accelSampleRate = 50;  //Hz.  Can be: 0,1,10,25,50,100,200,400,1600,5000 Hz
  myIMU.settings.accelRange = 2;      //Max G force readable.  Can be: 2, 4, 8, 16

  myIMU.settings.adcEnabled = 0;
  myIMU.settings.tempEnabled = 0;
  myIMU.settings.xAccelEnabled = 1;
  myIMU.settings.yAccelEnabled = 1;
  myIMU.settings.zAccelEnabled = 1;

  myIMU.applySettings();

  uint8_t dataToWrite = 0;

  //LIS3DH_INT1_CFG   
  //dataToWrite |= 0x80;//AOI, 0 = OR 1 = AND
  //dataToWrite |= 0x40;//6D, 0 = interrupt source, 1 = 6 direction source
  //Set these to enable individual axes of generation source (or direction)
  // -- high and low are used generically
  dataToWrite |= 0x20;//Z high
  //dataToWrite |= 0x10;//Z low
  dataToWrite |= 0x08;//Y high
  //dataToWrite |= 0x04;//Y low
  dataToWrite |= 0x02;//X high
  //dataToWrite |= 0x01;//X low
  myIMU.writeRegister(LIS3DH_INT2_CFG, dataToWrite);
  
  //LIS3DH_INT1_THS   
  dataToWrite = 0;
  //Provide 7 bit value, 0x7F always equals max range by accelRange setting
  dataToWrite |= 0x10; // 1/8 range
  myIMU.writeRegister(LIS3DH_INT2_THS, dataToWrite);
  
  //LIS3DH_INT1_DURATION  
  dataToWrite = 1;
  //minimum duration of the interrupt
  //LSB equals 1/(sample rate)
  dataToWrite |= 0x01; // 1 * 1/50 s = 20ms
  myIMU.writeRegister(LIS3DH_INT2_DURATION, dataToWrite);
  
  //LIS3DH_CLICK_CFG   
  dataToWrite = 0;
  //Set these to enable individual axes of generation source (or direction)
  // -- set = 1 to enable
  //dataToWrite |= 0x20;//Z double-click
  dataToWrite |= 0x10;//Z click
  //dataToWrite |= 0x08;//Y double-click 
  dataToWrite |= 0x04;//Y click
  //dataToWrite |= 0x02;//X double-click
  dataToWrite |= 0x01;//X click
  myIMU.writeRegister(LIS3DH_CLICK_CFG, dataToWrite);
  
  //LIS3DH_CLICK_SRC
  dataToWrite = 0;
  //Set these to enable click behaviors (also read to check status)
  // -- set = 1 to enable
  //dataToWrite |= 0x20;//Enable double clicks
  dataToWrite |= 0x04;//Enable single clicks
  //dataToWrite |= 0x08;//sine (0 is positive, 1 is negative)
  dataToWrite |= 0x04;//Z click detect enabled
  dataToWrite |= 0x02;//Y click detect enabled
  dataToWrite |= 0x01;//X click detect enabled
  myIMU.writeRegister(LIS3DH_CLICK_SRC, dataToWrite);
  
  //LIS3DH_CLICK_THS   
  dataToWrite = 0;
  //This sets the threshold where the click detection process is activated.
  //Provide 7 bit value, 0x7F always equals max range by accelRange setting
  dataToWrite |= 0x0A; // ~1/16 range
  myIMU.writeRegister(LIS3DH_CLICK_THS, dataToWrite);
  
  //LIS3DH_TIME_LIMIT  
  dataToWrite = 0;
  //Time acceleration has to fall below threshold for a valid click.
  //LSB equals 1/(sample rate)
  dataToWrite |= 0x08; // 8 * 1/50 s = 160ms
  myIMU.writeRegister(LIS3DH_TIME_LIMIT, dataToWrite);
  
  //LIS3DH_TIME_LATENCY
  dataToWrite = 0;
  //hold-off time before allowing detection after click event
  //LSB equals 1/(sample rate)
  dataToWrite |= 0x08; // 4 * 1/50 s = 160ms
  myIMU.writeRegister(LIS3DH_TIME_LATENCY, dataToWrite);
  
  //LIS3DH_TIME_WINDOW 
  dataToWrite = 0;
  //hold-off time before allowing detection after click event
  //LSB equals 1/(sample rate)
  dataToWrite |= 0x10; // 16 * 1/50 s = 320ms
  myIMU.writeRegister(LIS3DH_TIME_WINDOW, dataToWrite);

  //LIS3DH_CTRL_REG5
  //Int1 latch interrupt and 4D on  int1 (preserve fifo en)
  myIMU.readRegister(&dataToWrite, LIS3DH_CTRL_REG5);
  dataToWrite &= 0xF3; //Clear bits of interest
  dataToWrite |= 0x08; //Latch interrupt (Cleared by reading int1_src)
  //dataToWrite |= 0x04; //Pipe 4D detection from 6D recognition to int1?
  myIMU.writeRegister(LIS3DH_CTRL_REG5, dataToWrite);

  //LIS3DH_CTRL_REG3
  //Choose source for pin 1
  dataToWrite = 0;
  //dataToWrite |= 0x80; //Click detect on pin 1
  dataToWrite |= 0x40; //AOI1 event (Generator 1 interrupt on pin 1)
  dataToWrite |= 0x20; //AOI2 event ()
  //dataToWrite |= 0x10; //Data ready
  //dataToWrite |= 0x04; //FIFO watermark
  //dataToWrite |= 0x02; //FIFO overrun
  myIMU.writeRegister(LIS3DH_CTRL_REG3, dataToWrite);

  //LIS3DH_CTRL_REG6
  //Choose source for pin 2 and both pin output inversion state
  dataToWrite = 0;
  dataToWrite |= 0x80; //Click int on pin 2
  //dataToWrite |= 0x40; //Generator 1 interrupt on pin 2
  //dataToWrite |= 0x10; //boot status on pin 2
  //dataToWrite |= 0x02; //invert both outputs
  myIMU.writeRegister(LIS3DH_CTRL_REG6, dataToWrite);
```

### ChatGPT and Deep Sleep

I used ChatGPT 4 to write the code in this experiment. I prompted it with:

```
Are you familiar with the ESP32S3 and the LIS3DHTR accelerometer? I have them connected together: I2C bus SDA on the accelerometer is connected to GPIO 3 and SCL connected to GPIO 4. The accelerometer INT1 pin is connected to GPIO 14 and INT2 pin is connected to GPIO 13. I need an Arduino IDE 2.3.2 sketch. It will setup the ESP32 and accelerometer communication, and then put the ESP32 into deep sleep. When the accelerometer experiences movement, it wakes the ESP32 from sleep and sends a notification to the Serial Monitor. After 15 seconds the ESP32S3 puts itself into deep sleep.
```

and it responded

```
Sure! Below is an Arduino IDE sketch for the ESP32S3 connected to the LIS3DHTR accelerometer as described. This sketch sets up the communication between the ESP32S3 and the LIS3DHTR, puts the ESP32S3 into deep sleep, and wakes it up when movement is detected by the accelerometer. After 15 seconds, the ESP32S3 goes back into deep sleep.
```

The code worked fine with LIS3DH using INT1. When I asked it for help using INT2 the experience went sideways.

```
It looks like I provided incorrect function signatures for the SparkFun LIS3DH library initialization. The correct initialization for the SparkFun LIS3DH library does not directly accept Wire and the address as arguments in that form.
```

My full exchange with ChatGPT is here:
[https://chatgpt.com/share/9b29f236-1812-4907-a1a0-d2cf79ffd39d](https://chatgpt.com/share/9b29f236-1812-4907-a1a0-d2cf79ffd39d)

I'm finding ChatGPT to be my coding partner everyday. It may not be perfect each time, it is much easier than reading datasheets and using Google search.

### Finished Code

Find these notes and a working sketch here: [https://github.com/frankcohen/ReflectionsOS/tree/main/Experiments/Deep%20Sleep](https://github.com/frankcohen/ReflectionsOS/tree/main/Experiments/Deep%20Sleep)

-Frank

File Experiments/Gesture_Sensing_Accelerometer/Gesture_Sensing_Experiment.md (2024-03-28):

# Wrist Gesture Sensing
by Frank Cohen, fcohen@starlingwatch.com
March 17, 2024, updated March 27, 2024

Licensed under GPL v3, ok to share with attribution.

This is an experiment to see if a computing device can make sense of gestures made with a person's wrist. It identifies the [Fabulous Four Gestures](#fabulous-four-gestures) of next, previous, accept, and cancel. It is extensible to train and identify additional gestures. It uses [ESP32](https://www.espressif.com/en/products/socs/esp32) and [LIS3DHTR](https://www.digikey.com/en/products/detail/stmicroelectronics/LIS3DHTR/2334338) accelerometer. It uses a [Movement Observation Matching](#movement-observation-matching) algorithm to make sense of a person's wrist movements.

## Wrist Gestures Briefing

5 minute video briefing on Wrist Gesture Sensing.

Briefing (https://youtu.be/nNwV_FyjRPc)

## Fabulous Four Gestures

Human interfaces to computing devices often benefit from having 4 primary controls. I call these the Fabulous Four Gestures:

1. Next - person's goal is to move to a subsequent choice

Roll your fist counter clockwise, to the left.

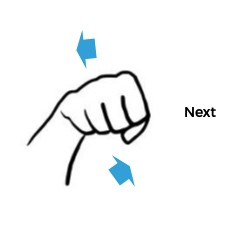
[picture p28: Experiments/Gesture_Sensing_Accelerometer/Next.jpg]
Next


2. Previous - person's goal is to return to a prior choice

Roll your fist clockwise, to the right.

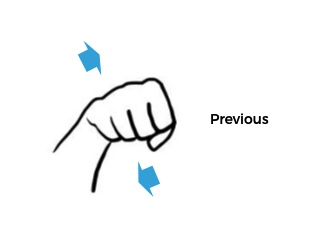
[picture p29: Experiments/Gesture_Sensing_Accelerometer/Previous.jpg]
Previous


3. Accept - person's goal is to approve a selection

I adopted the American Sign Language (ASL) movement to say yes, take a hand and make it into a fist and bob it back and forth, resembling a head nodding. 

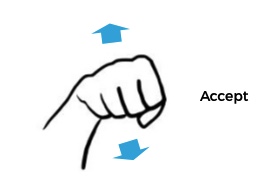
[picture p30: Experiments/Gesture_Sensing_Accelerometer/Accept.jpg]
Accept


4. Cancel - person's goal is to disapprove a selection

I adopted ASL to say no, take your first two fingers and tap them with your thumb, resembling a mouth saying no.

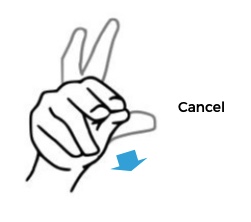
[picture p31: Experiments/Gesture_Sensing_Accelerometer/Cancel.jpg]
Cancel


Serial monitor shows status and progress to recognize gestures.

```
Comparing gestures
DTWgpt accelerometer gesture next	    5090.33,	4006.13,	3806.27,	3491.63,	3926.08,	 
DTWgpt accelerometer gesture previous	3884.40,	3595.16,	3730.78,	3616.00,	3515.38,	 
DTWgpt accelerometer gesture cancel	    5265.93,	4413.33,	5127.32,	5331.95,	5711.88,	 
DTWgpt accelerometer gesture accept	    4579.27,	5161.31,	4865.67,	5162.56,	4810.36,	 
DTWgpt, gesture recognized: next 3491
```

In the case where no gesture is recognized the code shows:
```
DTWgpt, gesture recognized: Inconclusive
```

## Movement Observation Matching

Movement Observation Matching (MOM) algorithm detects a person's wrist movements. It is a template system. It compares a person's movements to a library of recorded templates. Movement and template recordings begin with detection of a person's movement. A variety of techniques determine the conclusive determination of movements to the templates. 

Templates last 2 seconds, with 50 frames of accelerometer X, Y, Z data and 40 milliseconds between each frame. Recording begins after the person begins movement. Movements are the same duration and frames as templates.

MOM uses multiple templates for the same gesture to identify gestures. The default settings record 5 templates for each gesture. Then compare a persons latest gesture to the templates.

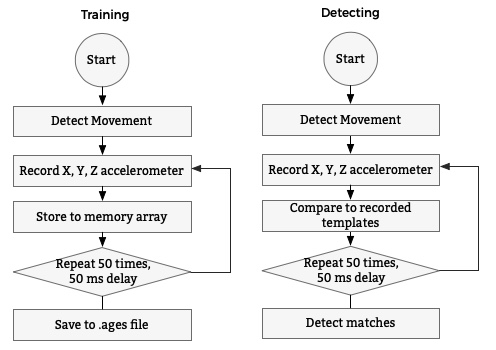
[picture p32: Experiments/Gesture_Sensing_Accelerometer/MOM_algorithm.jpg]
MOM Algorithm


Settings in Accelerometer.h control the types of gestures, the number of templates for each gesture type, the number of frames, and the template duration.

MOM uses these matching algorithms:

- Dynamic Time Warping (DTW), identifies distance between two sequences of equal length. The min() 
function finds the minimum of three values, and the distance() function calculates the Euclidean distance between two points in the sequences. The setup() function initializes Serial communication and calculates the DTW distance for two example sequences (seq1 and seq2). Finally, the DTW distance is printed to the Serial monitor.

Unused:

- Sum of averages, chooses the gesture type with the overall highest average matching ratio. Ratio must be 55% or higher to be selected.

- Highest average, chooses the gesture type with the highest single matching ratio. Ration must be 55% of higher to be selected.

MOM is extensible to include additional matching algorithms.

### Training

Training is the process of recording templates for the [Fabulous Four Gestures](#fabulous-four-gestures). Use this method to put the Gesture Sensor into training mode.

```
void setTraining( bool mode );
```

## Code

Find the implementation in the ReflectionsOS repository here: [https://github.com/frankcohen/ReflectionsOS/blob/main/src/Accellerometer.cpp](https://github.com/frankcohen/ReflectionsOS/blob/main/src/Accellerometer.cpp)

# Building

Use Arduino [IDE 2.3](https://www.arduino.cc/en/software) or later. Code requires changes to be compatible with Arduino IDE 1.x nor [Platform IO](https://platformio.org/).

Requires these libraries:

LISDHTR Accelerometer, [https://travis-ci.com/Seeed-Studio/Seeed_Arduino_LIS3DHTR.svg?branch=master](https://travis-ci.com/Seeed-Studio/Seeed_Arduino_LIS3DHTR.svg?branch=master)

ESP32 board, [https://github.com/espressif/arduino-esp32](https://github.com/espressif/arduino-esp32)

Hardware wiring:

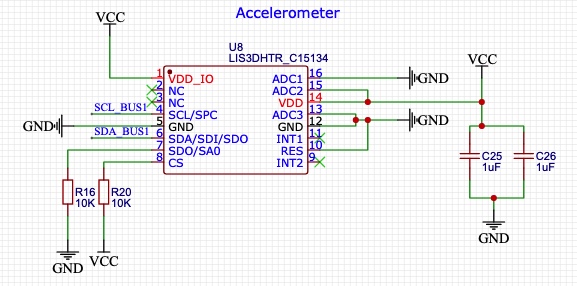
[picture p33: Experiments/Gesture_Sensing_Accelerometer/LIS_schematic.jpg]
Accelerometer schematic


## Future 

We have these planned improvements to MOM:

- Template effectiveness learning. MOM recognizes and promotes templates correctly recognized, and denegrates and removes templates that do not recognize movements. It will do this by observing a person's movements after detecting a gesture. For example, when a person gestures "previous" after MOM detects a "next" gesture more than 50% of the time it is fair for MOM to identify the "next" gesture as incorrectly identified.

- Automatic new template detection. MOM recognizes new templates from movements that do not match templates. For example, when a person makes 5 "next" gestures then an unidentified new gestures then another 5 "next" gestures, MOM adds the unidentified movement gesture as a new "next" gesture.

- Template sharing between people. MOM shares templates with high success ratings among other devices.

## The Unknown

MOM has yet to be proven in these instances:

- Is there a difference in recognition between left and right handed people?

- What impact does a benign essential tremor (ET), Parkinson's disease, Zlzheimer's disease, and Multiple Sclerosis (MS) have on gesture recognition?

- Do individuals gesture differently?

## Investigations Along The Way

[@CieloStrive](https://github.com/CieloStrive) experiment on [gesture cognition using Dynamic Time Warping (DTW)](https://github.com/CieloStrive/GESTURE-RECOGNITION-DYNAMIC-TIME-WARPING) influenced this experiment. My DTW implementation is at [https://github.com/frankcohen/ReflectionsOS/tree/main/Experiments/Gesture_Sensing_Accelerometer/AccelGestureDTW](https://github.com/frankcohen/ReflectionsOS/tree/main/Experiments/Gesture_Sensing_Accelerometer/AccelGestureDTW)

## ReflectionsOS Project

Reflections is an open-source hardware and software platform for building entertaining mobile experiences. Details at [https://github.com/frankcohen/ReflectionsOS](https://github.com/frankcohen/ReflectionsOS)

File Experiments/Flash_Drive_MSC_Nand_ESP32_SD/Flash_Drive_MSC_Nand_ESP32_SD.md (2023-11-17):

# Using the Reflections board NAND as a Flash Drive, FlashDrive + MSC + Nand + ESP32 + SD

November 16, 2023

Operates the Reflections board NAND/SD as a USB flash drive

Based on code from [@atomic14](https://www.youtube.com/@atomic14) and [SD MSC utility for ESP32 processors](https://github.com/atomic14/esp32-sdcard-msc/tree/main) 

Arduino IDE 2 sketch is [/Experiments/Flash_Drive_MSC_Nand_ESP32_SD](https://github.com/frankcohen/ReflectionsOS/tree/main/Experiments/Flash_Drive_MSC_Nand_ESP32_SD/NANDMSC)

Arduino IDE settings:
- Adafruit Feather ESP32-S3 No PSRAM
- USB mode: USB-OTG
- USB CDC On Boot: Enabled
- USB Firmware MSC On Boot: Disabled
- USB DFU On Boot: Disabled
- JTAG Adapter: Integrated USB JTAG

Schematic

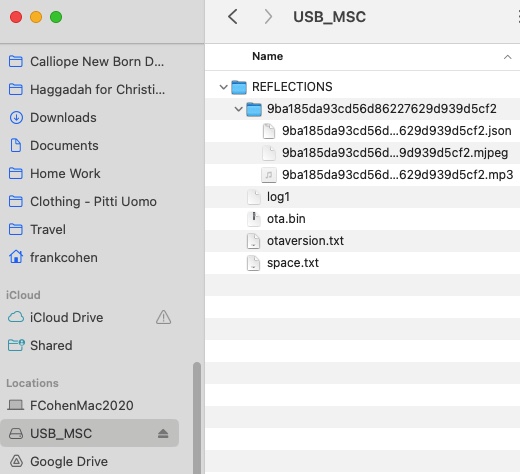
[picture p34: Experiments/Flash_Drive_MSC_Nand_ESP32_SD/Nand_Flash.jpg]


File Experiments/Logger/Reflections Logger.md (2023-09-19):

ESP32+SD/NAND fails on reuse of File object to secondary file

Hi Arduinoistas, the ESP32 SD library stops writing to a file when I re-use a File object.

I wrote a logger. It runs on an ESP32-S3, stores the log values on local storage temporarily, and sends the log values over Wifi to a service for storage. My goal is to have an unlimited number of log entries. And not bog-down the ESP32 as it stores and uploads the logs.

The logger takes String values, saves them to a log file on an SD/NAND device. NAND is a surface mount version of an SD card. The logger keeps logging to the file until the file size hits 200 bytes (200 is for testing, the NAND has 8 Gbytes of storage). The logger then closes the file and marks it for upload to the server. It opens a second log file for writing. While it uploads the first log file contents to a service, it logs new values to the second file. Once the logger finishes uploading the first log file, it removes and then recreates the first file. When the second file has 200 bytes it switches logging to the first file. 

I am seeing after switching log files the write fails. I check the file size before and after the write. The File print command returns the value 40. This is the correct length of the log I am writing to the file. The file size does not change.

Up until the failure, the SD library correctly writes the log values to the log files.

Any help with this would be great of you and appreciated, including criticisms of the design and refactoring ideas. I'm open to all.

This is from my Reflections open-source project at https://github.com/frankcohen/ReflectionsOS. 

Datasheet for the SD/NAND is at https://www.lcsc.com/product-detail/NAND-FLASH_XTX-XTSD01GLGEAG_C558837.html. The SD/NAND works fine for the other parts of my project, including saving 5 megabyte or larger binary files.

Here is what I am seeing in the Serial Monitor:

```
SD card mounted
Wifi begin
Logged to /log1.txt, logval = 40, characters 40, file size before 20, file size after 40, FAIL
Logged to /log1.txt, logval = 40, characters 40, file size before 40, file size after 80, OK
Logged to /log1.txt, logval = 40, characters 40, file size before 80, file size after 120, OK
Logged to /log1.txt, logval = 40, characters 40, file size before 120, file size after 160, OK
Logged to /log1.txt, logval = 40, characters 40, file size before 160, file size after 200, OK
Switching to log 0, mylog.size() = 200
opening mylog using /log0.txt
After switch mylog.size() = 20, OK
sendToServer: CALLIOPE-00,1,Info,testing the logger 0
sendToServer: CALLIOPE-00,1,Info,testing the logger 1
Logged to /log0.txt, logval = 40, characters 40, file size before 20, file size after 60, OK
sendToServer: CALLIOPE-00,1,Info,testing the logger 2
sendToServer: CALLIOPE-00,1,Info,testing the logger 3
sendToServer: CALLIOPE-00,1,Info,testing the logger 4
Logged to /log0.txt, logval = 40, characters 40, file size before 60, file size after 100, OK
Uploading complete, logs sent to service 5
Logged to /log0.txt, logval = 40, characters 40, file size before 100, file size after 140, OK
Logged to /log0.txt, logval = 40, characters 40, file size before 140, file size after 180, OK
Logged to /log0.txt, logval = 40, characters 40, file size before 180, file size after 220, OK
Switching to log 1, mylog.size() = 220
opening mylog using /log1.txt
After switch mylog.size() = 20, OK
sendToServer: 01234567890123456789CALLIOPE-00,0,Info,testing the logger 5
sendToServer: CALLIOPE-00,0,Info,testing the logger 6
sendToServer: CALLIOPE-00,0,Info,testing the logger 7
Logged to /log1.txt, logval = 41, characters 41, file size before 20, file size after 20, FAIL
sendToServer: CALLIOPE-00,0,Info,testing the logger 8
sendToServer: CALLIOPE-00,0,Info,testing the logger 9
Uploading complete, logs sent to service 5
Logged to /log1.txt, logval = 41, characters 41, file size before 20, file size after 20, FAIL
Logged to /log1.txt, logval = 41, characters 41, file size before 20, file size after 20, FAIL
Logged to /log1.txt, logval = 41, characters 41, file size before 20, file size after 20, FAIL
Logged to /log1.txt, logval = 41, characters 41, file size before 20, file size after 20, FAIL
Logged to /log1.txt, logval = 41, characters 41, file size before 20, file size after 20, FAIL
Logged to /log1.txt, logval = 41, characters 41, file size before 20, file size after 20, FAIL
Logged to /log1.txt, logval = 41, characters 41, file size before 20, file size after 20, FAIL
Logged to /log1.txt, logval = 41, characters 41, file size before 20, file size after 20, FAIL
Logged to /log1.txt, logval = 41, characters 41, file size before 20, file size after 20, FAIL
Logged to /log1.txt, logval = 41, characters 41, file size before 20, file size after 20, FAIL
Logged to /log1.txt, logval = 41, characters 41, file size before 20, file size after 20, FAIL
Logged to /log1.txt, logval = 41, characters 41, file size before 20, file size after 20, FAIL
Logged to /log1.txt, logval = 41, characters 41, file size before 20, file size after 20, FAIL
Logged to /log1.txt, logval = 41, characters 41, file size before 20, file size after 20, FAIL
Logged to /log1.txt, logval = 41, characters 41, file size before 20, file size after 20, FAIL
```

Contents of the sketch.

```
long mylogtime = millis();
int logcount = 0;

void setup()
{
  . . .
  logger.begin();
  . . .
}

void loop()
{

  if ( (millis() - mylogtime) > 2000 ) 
  {
    mylogtime = millis();
    String myl = "testing the logger ";
    myl += String(logcount++);
    logger.info( myl );    

    //storage.listDir( SD, "/", 100, true );
  }

  logger.loop();
}
```

Contents of Logger.h

```
#ifndef _LOGGER_
#define _LOGGER_

#include "config.h"
#include "secrets.h"

#include "Arduino.h"
#include "HTTPClient.h"
#include <WiFi.h>
#include "FS.h"
#include "SD.h"

#include <UrlEncode.h>

#define log_size_upload 200

#define maxlogmsg 300

class LOGGER
{
  public:
    LOGGER();
    void begin();
    void loop();

    void info( String message );
    void warning( String message );
    void error( String message );
    void critical( String message );
    void clearLog( String logname );

  private:
    void logit( String msg );
    bool setActiveFile( int atvnum );
    bool sendToServer( String message );

    int activelog;

    File mylog;
    bool mylogopen;
    String mylogname;

    std::string devname;
    String devicename;

    File myupload;
    String uploadfilename;
    bool myuploadopen;
    bool uploading;

    long uploadcount;

};

#endif // _LOGGER_
```

Contents of Logger.cpp

```
/*
 Reflections, mobile connected entertainment device

 Repository is at https://github.com/frankcohen/ReflectionsOS
 Includes board wiring directions, server side components, examples, support

 Licensed under GPL v3 Open Source Software
 (c) Frank Cohen, All rights reserved. fcohen@starlingwatch.com
 Read the license in the license.txt file that comes with this code.

 Depends on:
 https://github.com/plageoj/urlencode
*/

#include "LOGGER.h"

extern const char* root_ca;   // Defined in secrets.h

LOGGER::LOGGER(){}

void LOGGER::info( String message )
{
  String lm = "Info,";
  lm += message;
  logit( lm );
}

void LOGGER::warning( String message )
{
  String lm = "Warning,";
  lm += message;
  logit( lm );
}

void LOGGER::error( String message )
{
  String lm = "Error,";
  lm += message;
  logit( lm );
}

void LOGGER::critical( String message)
{
  String lm = "Critical,";
  lm += message;
  logit( lm );
}

/*
* Adds host name and sends to active file
*/

void LOGGER::logit( String msg )
{
  if ( mylogopen != 1 )
  {
    Serial.println( "Not logging, mylog is not open" );
    return;    
  }

  String logmsg = devname.c_str();
  logmsg += ",";
  logmsg += activelog;
  logmsg += ",";
  logmsg += msg;
  logmsg += "\n";

  long mysize = (long) mylog.size();

  int logval = mylog.print( logmsg );
  mylog.flush();

  Serial.print( "Logged to " );
  Serial.print( mylogname );
  Serial.print( ", logval = ");
  Serial.print( logval );
  Serial.print( ", characters " );
  Serial.print( logmsg.length() );
  Serial.print( ", file size before " );
  Serial.print( mysize );
  Serial.print( ", file size after " );
  Serial.print( mylog.size() );
  if ( mylog.size() == mysize + logmsg.length() )
  {
    Serial.println( ", OK" );
  }
  else
  {
    Serial.println( ", FAIL" );
  }
  
  if ( ( uploading ) || ( mylog.size() < log_size_upload ) ) return;

  if ( activelog == 0 )
  {
    Serial.print( "Switching to log 1, mylog.size() = " );
    Serial.println( mylog.size() );

    uploadfilename = log_file_name0;
    activelog = 1;
    mylogname = log_file_name1;
  }
  else
  {
    Serial.print( "Switching to log 0, mylog.size() = " );
    Serial.println( mylog.size() );

    uploadfilename = log_file_name1;
    activelog = 0;
    mylogname = log_file_name0;
  }

  mylog.close();
  mylogopen = 0;

  Serial.print( "opening mylog using ");
  Serial.println( mylogname );

  mylog = SD.open( mylogname, FILE_WRITE );
  if( !mylog )
  {
    Serial.print( F( "Failed to open log file " ) );
    Serial.println( mylogname );
    return;
  }

  mylogopen = 1;

  // Set up for an upload to the log service

  if ( myuploadopen )
  {
    myupload.close();
    Serial.println( "Closed myupload");
  }
  
  myupload = SD.open( uploadfilename );
  if( !myupload )
  {
    Serial.print( F("Could not open upload file for reading " ) );
    Serial.println( uploadfilename );
    return;
  }

  myuploadopen = 1;
  setActiveFile( activelog );
  uploading = 1;
  uploadcount = 0;

  // Log integrity check

  mylog.print( "0123456789" );
  mylog.print( "0123456789" );
  mylog.flush();
  Serial.print( "After switch mylog.size() = " );
  Serial.print( mylog.size() );
  if ( mylog.size() == 20 )
  {
    Serial.println( ", OK" );
  }
  else
  {
    Serial.println( ", FAIL" );
  }

}

/*
* Set active log file contents
*/

bool LOGGER::setActiveFile( int atvnum )
{
  SD.remove( LOG_ACTIVE_FILE_NAME );

  File activefile = SD.open( LOG_ACTIVE_FILE_NAME, FILE_WRITE );
  if( !activefile )
  {
    Serial.print( "Error opening " );
    Serial.print( LOG_ACTIVE_FILE_NAME );
    return false;
  }

  activefile.print( String( atvnum ) );

  activefile.close();

  return true;
}

/*
* Clear the contents of a log file
*/

void LOGGER::clearLog( String logname )
{
  SD.remove( logname );

  File loggyfile = SD.open( logname, FILE_WRITE );
  if( !loggyfile )
  {
    Serial.print( F( "Failed to create log file " ) );
    Serial.println( logname );
    return;
  }

  loggyfile.print( devicename );
  loggyfile.print( ",info,Starting new log file ");
  loggyfile.print( logname );
  loggyfile.print( "\n" );
  loggyfile.close();
}

/*
* Sends message to the server over HTTPS GET protocol
*/

bool LOGGER::sendToServer( String message )
{
  Serial.print( "sendToServer: ");
  Serial.println( message );

  String logurl = cloudCityLogURL;
  logurl += urlEncode( message );

  HTTPClient http;
  http.begin( logurl, root_ca );

  int httpCode = http.GET();

  if( httpCode != HTTP_CODE_OK )
  {
    Serial.print( F( "Server response code: " ) );
    Serial.println( httpCode );
    return false;
  }

  return true;
}

/*
* Begin picks-up the state from where we left off (from the file system)
* or creates the initial state (and file system logs)
*/

void LOGGER::begin()
{
  root_ca = ssl_cert;   // Defined in secrets.h

  activelog = 0;
  mylogopen = 0;
  myuploadopen = 0;
  uploading = 0;
  uploadcount = 0;

  devname = host_name_me;
  std::string mac = WiFi.macAddress().c_str();
  devname.append( mac.substr( 15, 2 ) );
  devicename = devname.c_str();

  // Read the previous state from the LOG_ACTIVE_FILE_NAME file

  File activefile = SD.open( LOG_ACTIVE_FILE_NAME );
  if ( !activefile )
  {
    // Create a new active log number file, since one doesn't exist

    activefile = SD.open( LOG_ACTIVE_FILE_NAME, FILE_WRITE );
    if( !activefile )
    {
      Serial.println( F( "Unable to create log active file" ) );
    }    

    activefile.print( String( 0 ) );
    activelog = 0;      
    activefile.close();
  }
  else
  {
    // Get the active log number from the file

    char myNum[5];
    int i = 0;
    while ( activefile.available() && ( i < 5 ) )
    {
      myNum[ i ] = activefile.read();
      i++;
    }
    myNum[ i ] = 0;
    int myVer = atoi( myNum );

    Serial.print( F( "Active log number is " ) );
    Serial.println( myVer );

    activelog = myVer;
    activefile.close();
  }

  // Create the log files if they don't exist

  File logf = SD.open( log_file_name0 );
  if ( !logf )
  {
    Serial.println( F("Create new log file 0" ) );
    logf = SD.open( log_file_name0, FILE_WRITE );
    if ( !logf )
    {
      Serial.println( F("Failed to create new log file 0" ) );
    }
  }
  logf.close();

  File logf2 = SD.open( log_file_name1 );
  if ( !logf2 )
  {
    Serial.print( F("Created new log file 1" ) );
    logf2 = SD.open( log_file_name1, FILE_WRITE );
    if ( !logf2 )
    {
      Serial.println( F("Failed to create new log file 1" ) );
    }
  }
  logf2.close();

  // Open the active log file

  if ( activelog == 0 )
  {
    mylog = SD.open( log_file_name0, FILE_WRITE );
    if( !mylog )
    {
      Serial.print( F("Could not open or create " ) );
      Serial.println( log_file_name0 );
      return;
    }
    mylogopen = 1;
    mylogname = log_file_name0;
  }
  else
  {
    mylog = SD.open( log_file_name1, FILE_WRITE );
    if( !mylog )
    {
      Serial.print( F("Could not open or create " ) );
      Serial.println( log_file_name1 );
      return;
    }
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

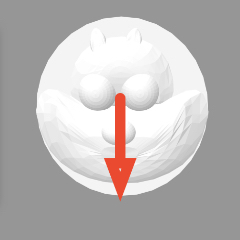
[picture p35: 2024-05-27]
Experiments/Range Heading Distance RHD/Cat_RHD_Faces/cat_rhd_5.jpg

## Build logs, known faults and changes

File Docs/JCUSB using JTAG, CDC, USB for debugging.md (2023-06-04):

# ESP32 USB is frustrating, try JCUSB for S3 + USB + CDC + OpenOCD + Arduino IDE

YouTube creator and Arduino Expert Andreas Spiess recently published a video on using the USB debugging support on ESP32 for Arduino users at https://www.youtube.com/watch?v=hJSBTFsOnoA&t=0s. He presents 4 different ways to use USB with ESP32. His video culminates the struggle many have had with ESP32 support over the past 7 years since Espressif launched ESP32. I started coding in the 1970s and waited for an Arduino that has a great IDE, networking (Wifi and Bluetooth), lots of memory, debugging, and a community making useful libraries. The latest USB support in ESP32-S3 finally meets my needs.

However, Andreas' video on USB is like my Arduino experience overall. I found tremendous good will and very little coordination. For someone like me there still is no "Start Here" in Arduino. It's a mash-up of C programming (ugh, C should have been retired decades ago) and hardware variations. Andreas presents 4 ways ESP32 supports USB, and 1 of them meets my needs.

##JCUSB

I call this 1 solution JCUSB short for JTAG + CDC + USB + OpenOCD + Arduino IDE Debugger. Only ESP32-S3 and its successors support JCUSB - it won't work on ESP32 and ESP32-S2. JCUSB uses a custom USB cable to connect an ESP32 to a Windows or MacOS computer. Here is the custom cable:

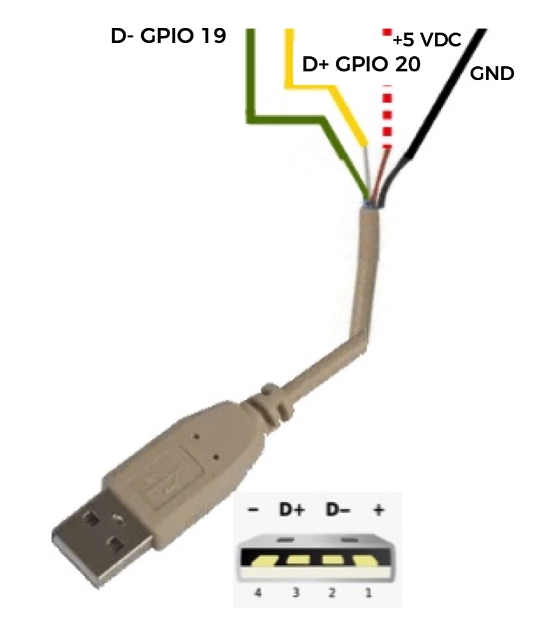
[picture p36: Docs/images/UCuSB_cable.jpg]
JCUSB Cable


Install Arduino IDE 2.1 or greater, choose the ESP32S3 Dev Kit board, then choose these settings in the Tools drop-down menu:

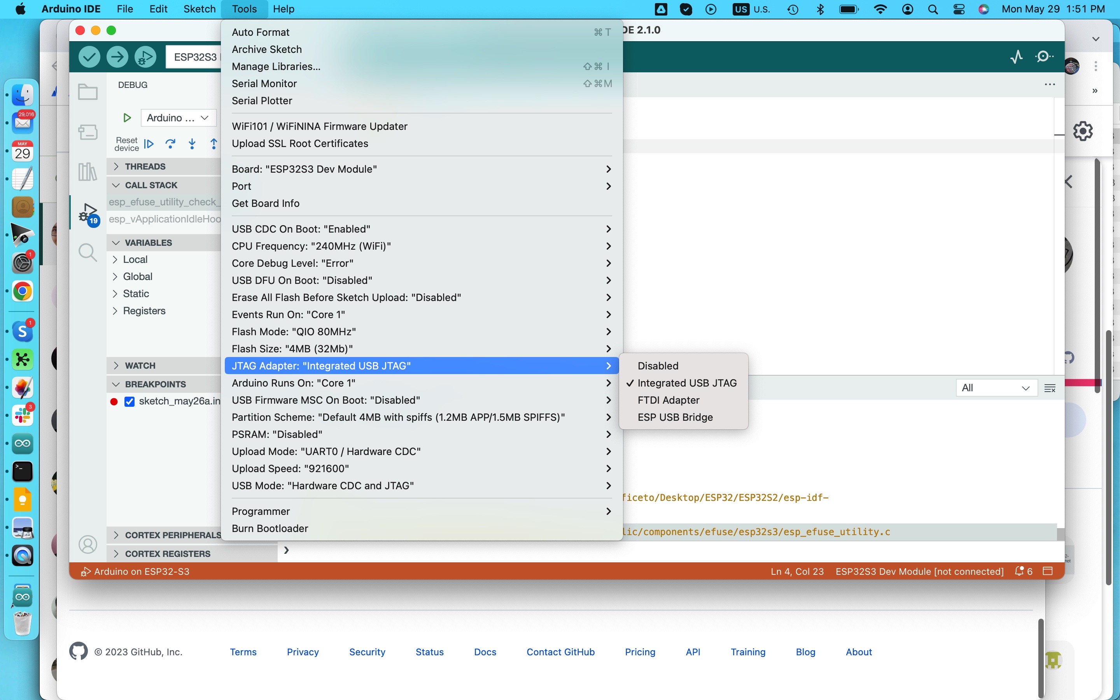
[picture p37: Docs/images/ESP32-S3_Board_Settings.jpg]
JCUSB Arduino IDE 2.1 settings for ESP32-S3 board


Choosing a different board may cause Arduino IDE to not show you the needeed JTAG, CDC, and OpenOCD parameters needed for JCUSB to function.

Choose the ESP32 S3 Board type and serial port. Click compile, then click Debug.

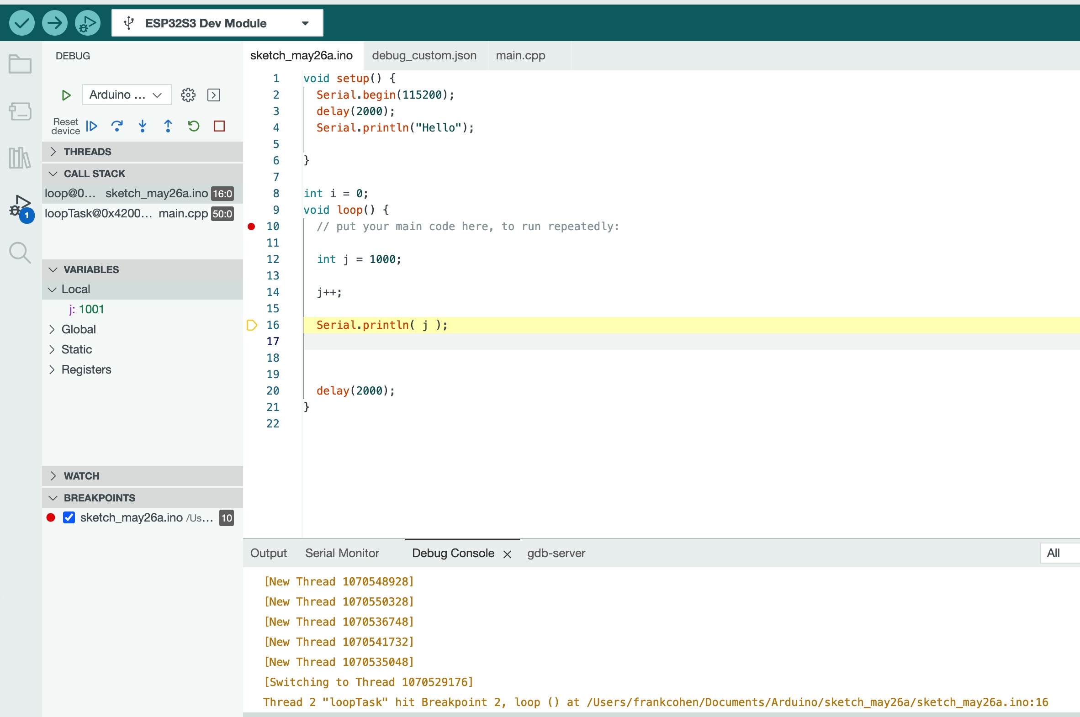
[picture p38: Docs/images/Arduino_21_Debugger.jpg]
Arduinno IDE 2.1 Debugger


In Arduino IDE 2.1's Debug panel set debug breakpoints, inspect variables and step through execution of your code.

JCUSB gives fast uploads, debugging, breakpoints, variable inspection, and stepping in and out of code. The alternative is to load up my code with  Serial.println(""); commands and compile-upload-run.

I created a video answer to Andreas with more discussion of the problems I encountered:

Watch the video

I am using JCUSB in my upcoming open source project Reflections, a portable and mobile way to make animation experiences possible. Check https://github.com/frankcohen/ReflectionsOS for source code, examples, experiments, and details.

And please let me know where I got any of this wrong, and how to fix it. 

Thanks!

-Frank

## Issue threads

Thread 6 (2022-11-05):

Hello, some random questions...

RPdenBoer, 2022-11-05:
@frankcohen
Hi, interesting project. Thanks for documenting it here.
I'm curious why you haven't used SD_MMC, rather than the slower SPI? I know ESP32 S2 doesn't have SDIO support, but S3 does so why not use it, even if only in 1 bit mode? Was this to support your choice of NAND chip?
Speaking of which, you mentioned being able to store gigabytes of data, but the chip on your schematic seems to have a capacity of only 128MB, with a max of just 1GB in that family?

I'm working on some unrelated projects myself that have overlap on these issues, so interested to hear your thoughts :)

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

frankcohen, 2024-06-20:
Hi, I'm sorry for the too-late response. I chose SPI for easy coding. I started this project as a software engineer. It taught me all about hardware. I am getting 10-13 frames per second on a TFT display from the SPI Nand/SD. I'm now expecting to transition the design to MMC later this year. I have my hands full with the software coding for an exciting artful watch experience I am developing with Terri Hardin, Imagineer and Muppeteer, that uses the Reflections project. -Frank

Closed 2024-06-20.

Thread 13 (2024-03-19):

The disk is shown as not formatted

wbadry, 2024-03-19:

wbadry, 2024-03-19:
HI,
I tried your code example :

https://github.com/frankcohen/ReflectionsOS/blob/main/Experiments/Flash_Drive_MSC_Nand_ESP32_SD/Flash_Drive_MSC_Nand_ESP32_SD.md

The SD card is correctly connected via SPI and on the SPI example, I can write and read with no issues.

When I use your code, I receive a message that the USB is not formatted. Also, would your code allow the data transfer like copy paste on the computer?

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

Your help is much appreciated.

frankcohen, 2024-03-21:
Hmmmmm… I haven’t tried the code on Windows. It works for me on a MacBook Pro running Sonoma 14.4.

Also, I’ve rewritten the code at least twice. I found bugs in the ESP MSC library. And I found multiple ways to use the ESP MSC library from various locations on the Web. It’s been frustrating.

Here is the my latest code (attached). Please let me know your experience with it.

-Frank

￼

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

frankcohen, 2024-03-21:
Here is the attachment. -Frank
[NANDMSC.zip](https://github.com/frankcohen/ReflectionsOS/files/14686530/NANDMSC.zip)

wbadry, 2024-03-23:
Thank you so much for your response. That fixed the issue.

Closed 2024-03-23.

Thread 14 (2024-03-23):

Mass Storage Device example with SD_MMC (SDIO interface)

wbadry, 2024-03-23:
Hi,
Since your SPI Mass Storage Device code is beautifully working, are there any example you made for SDIO interface. I believe you already succeeded in making the USB part work. Have you had any trials with SDIO, as I intended to use it with eMMC.

Your assistance is much appreciated.

wbadry, 2024-08-24:
Thanks @frankcohen so much. It is now applied in the latest [ESP32 Arduino Core 3.0.4][(libraries/SD_MMC/examples/SD2USBMSC/SD2USBMSC.ino](https://github.com/espressif/arduino-esp32/blob/master/libraries/SD_MMC/examples/SD2USBMSC/SD2USBMSC.ino))

frankcohen, 2024-08-24:
Thank you.

On Sat, Aug 24, 2024, 2:51 PM Waleed El-Badry ***@***.***>
wrote:

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

Closed 2024-06-20.

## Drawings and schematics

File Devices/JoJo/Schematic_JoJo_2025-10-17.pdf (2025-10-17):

## USB and Battery Charger

## Battery Management

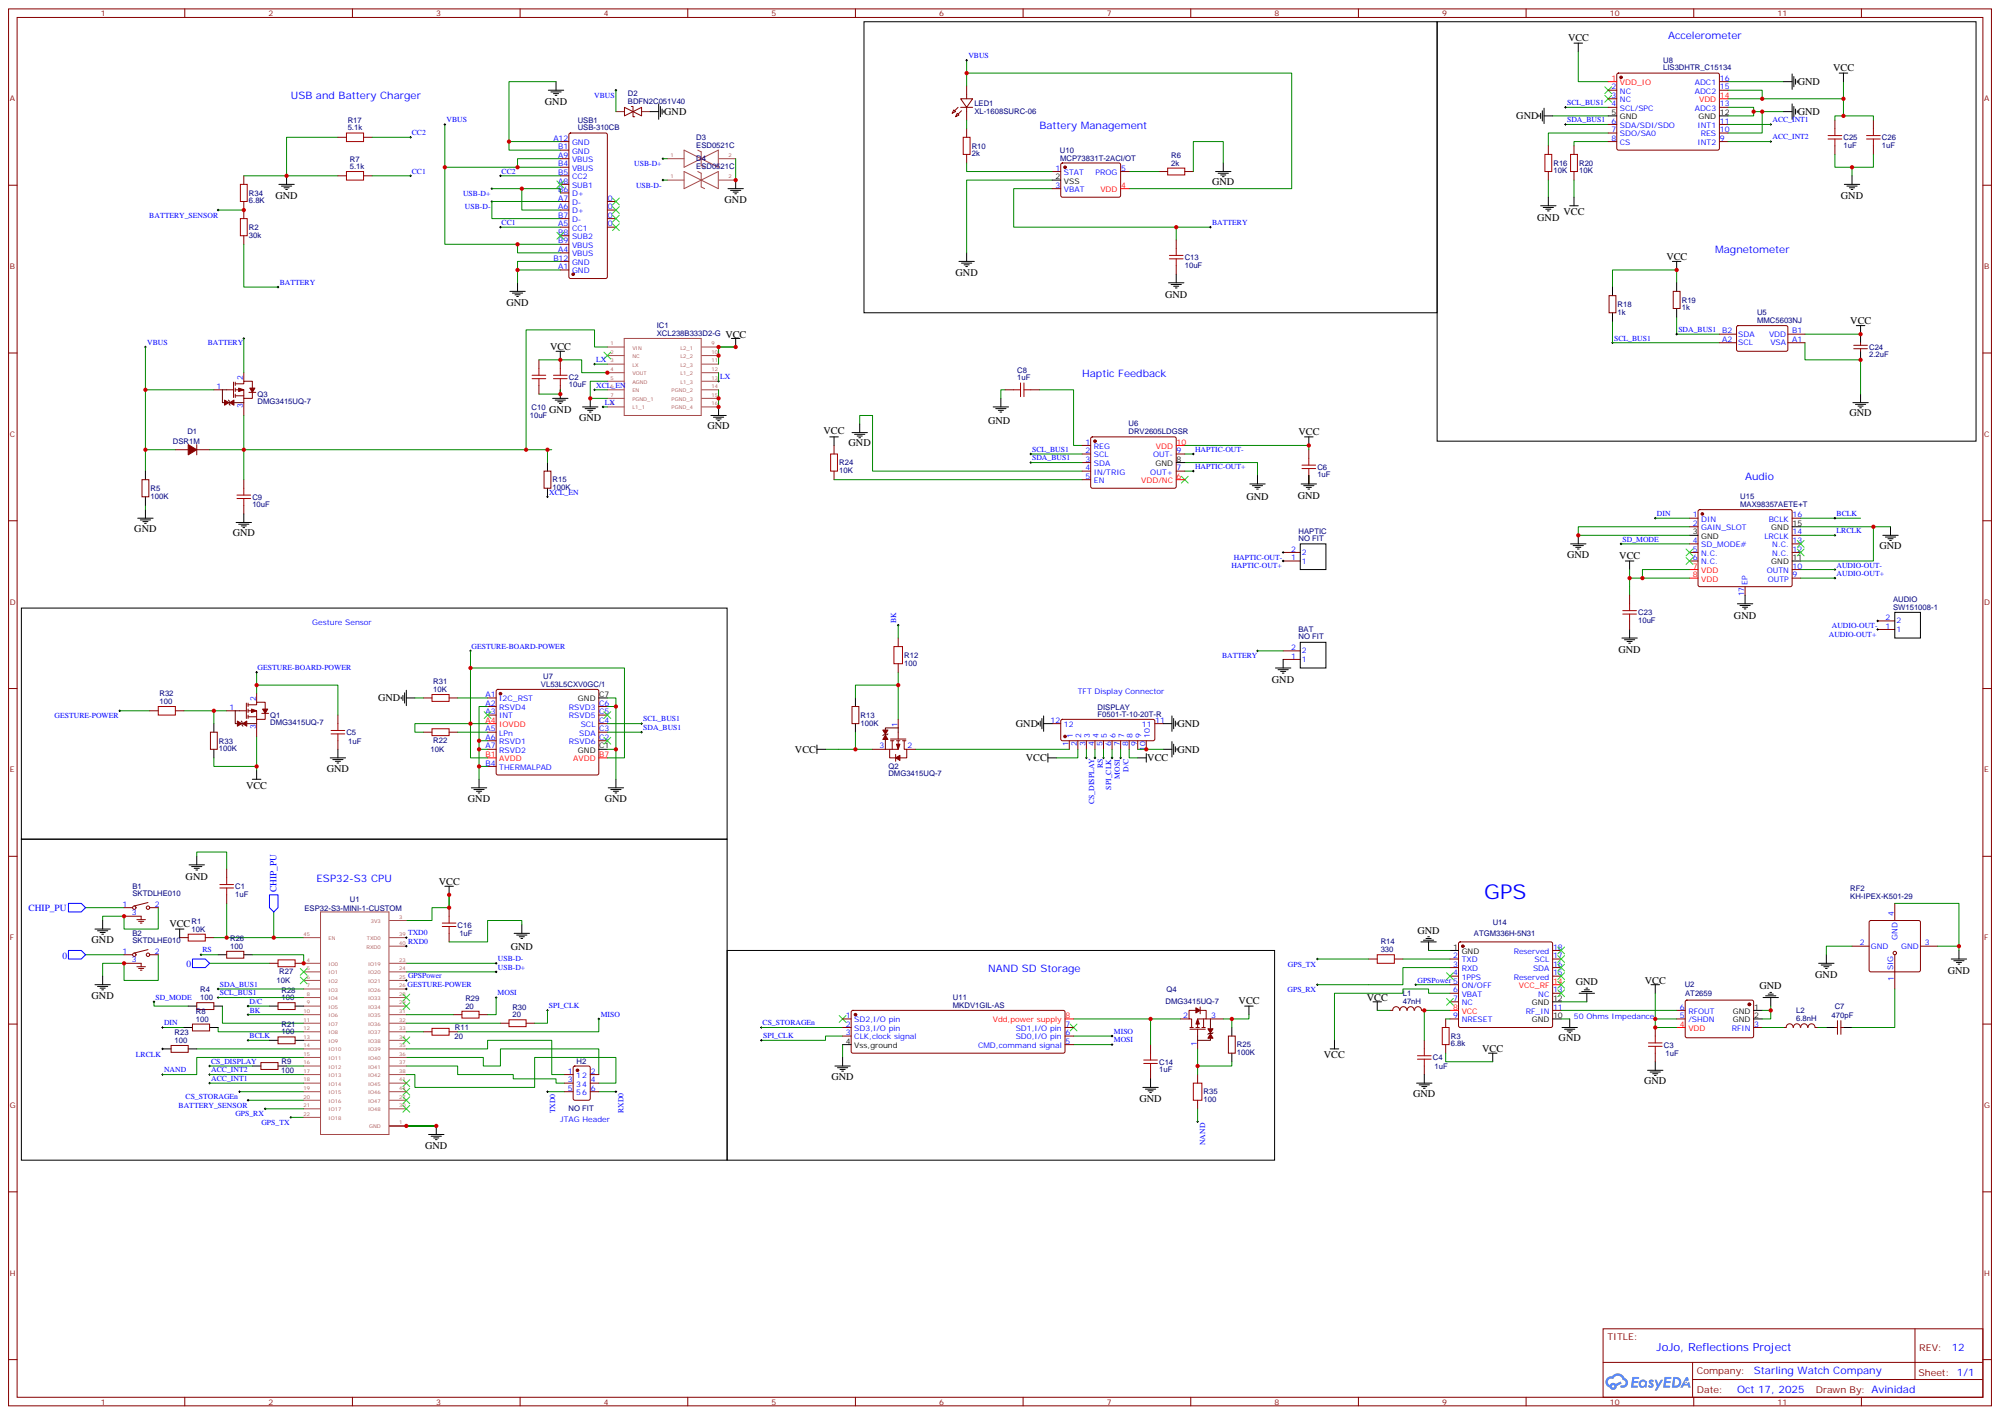
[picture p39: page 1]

Company: Starling Watch Company

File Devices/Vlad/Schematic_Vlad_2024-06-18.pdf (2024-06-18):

## Haptic Feedback

## USB and Battery Charger

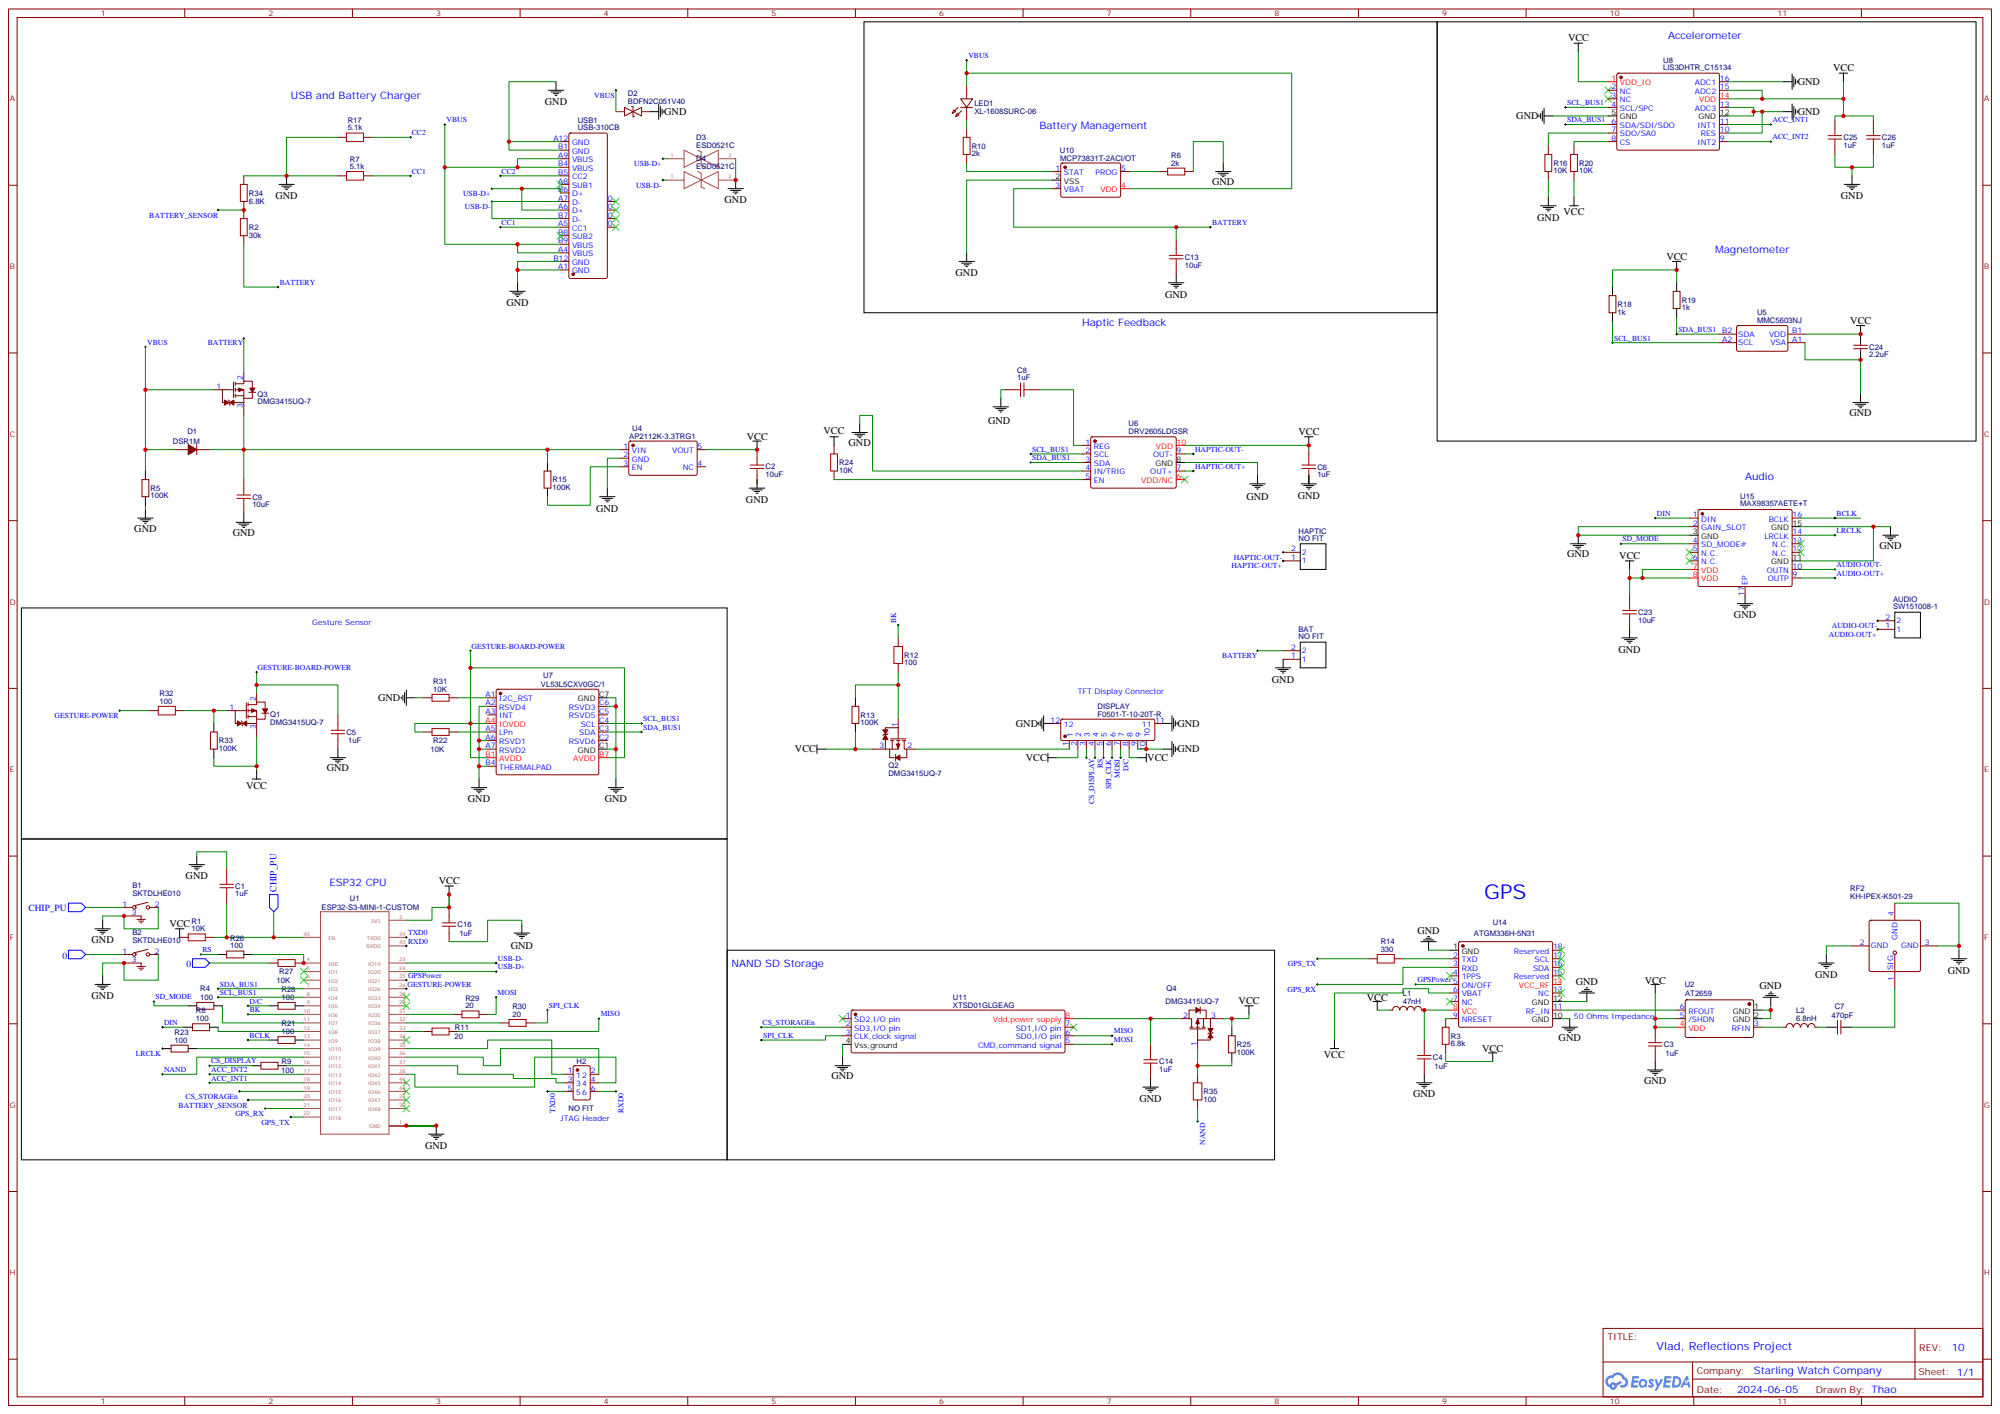
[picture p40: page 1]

Company: Starling Watch Company

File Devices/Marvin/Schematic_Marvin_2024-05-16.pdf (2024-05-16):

## Haptic Feedback

## USB and Battery Charger

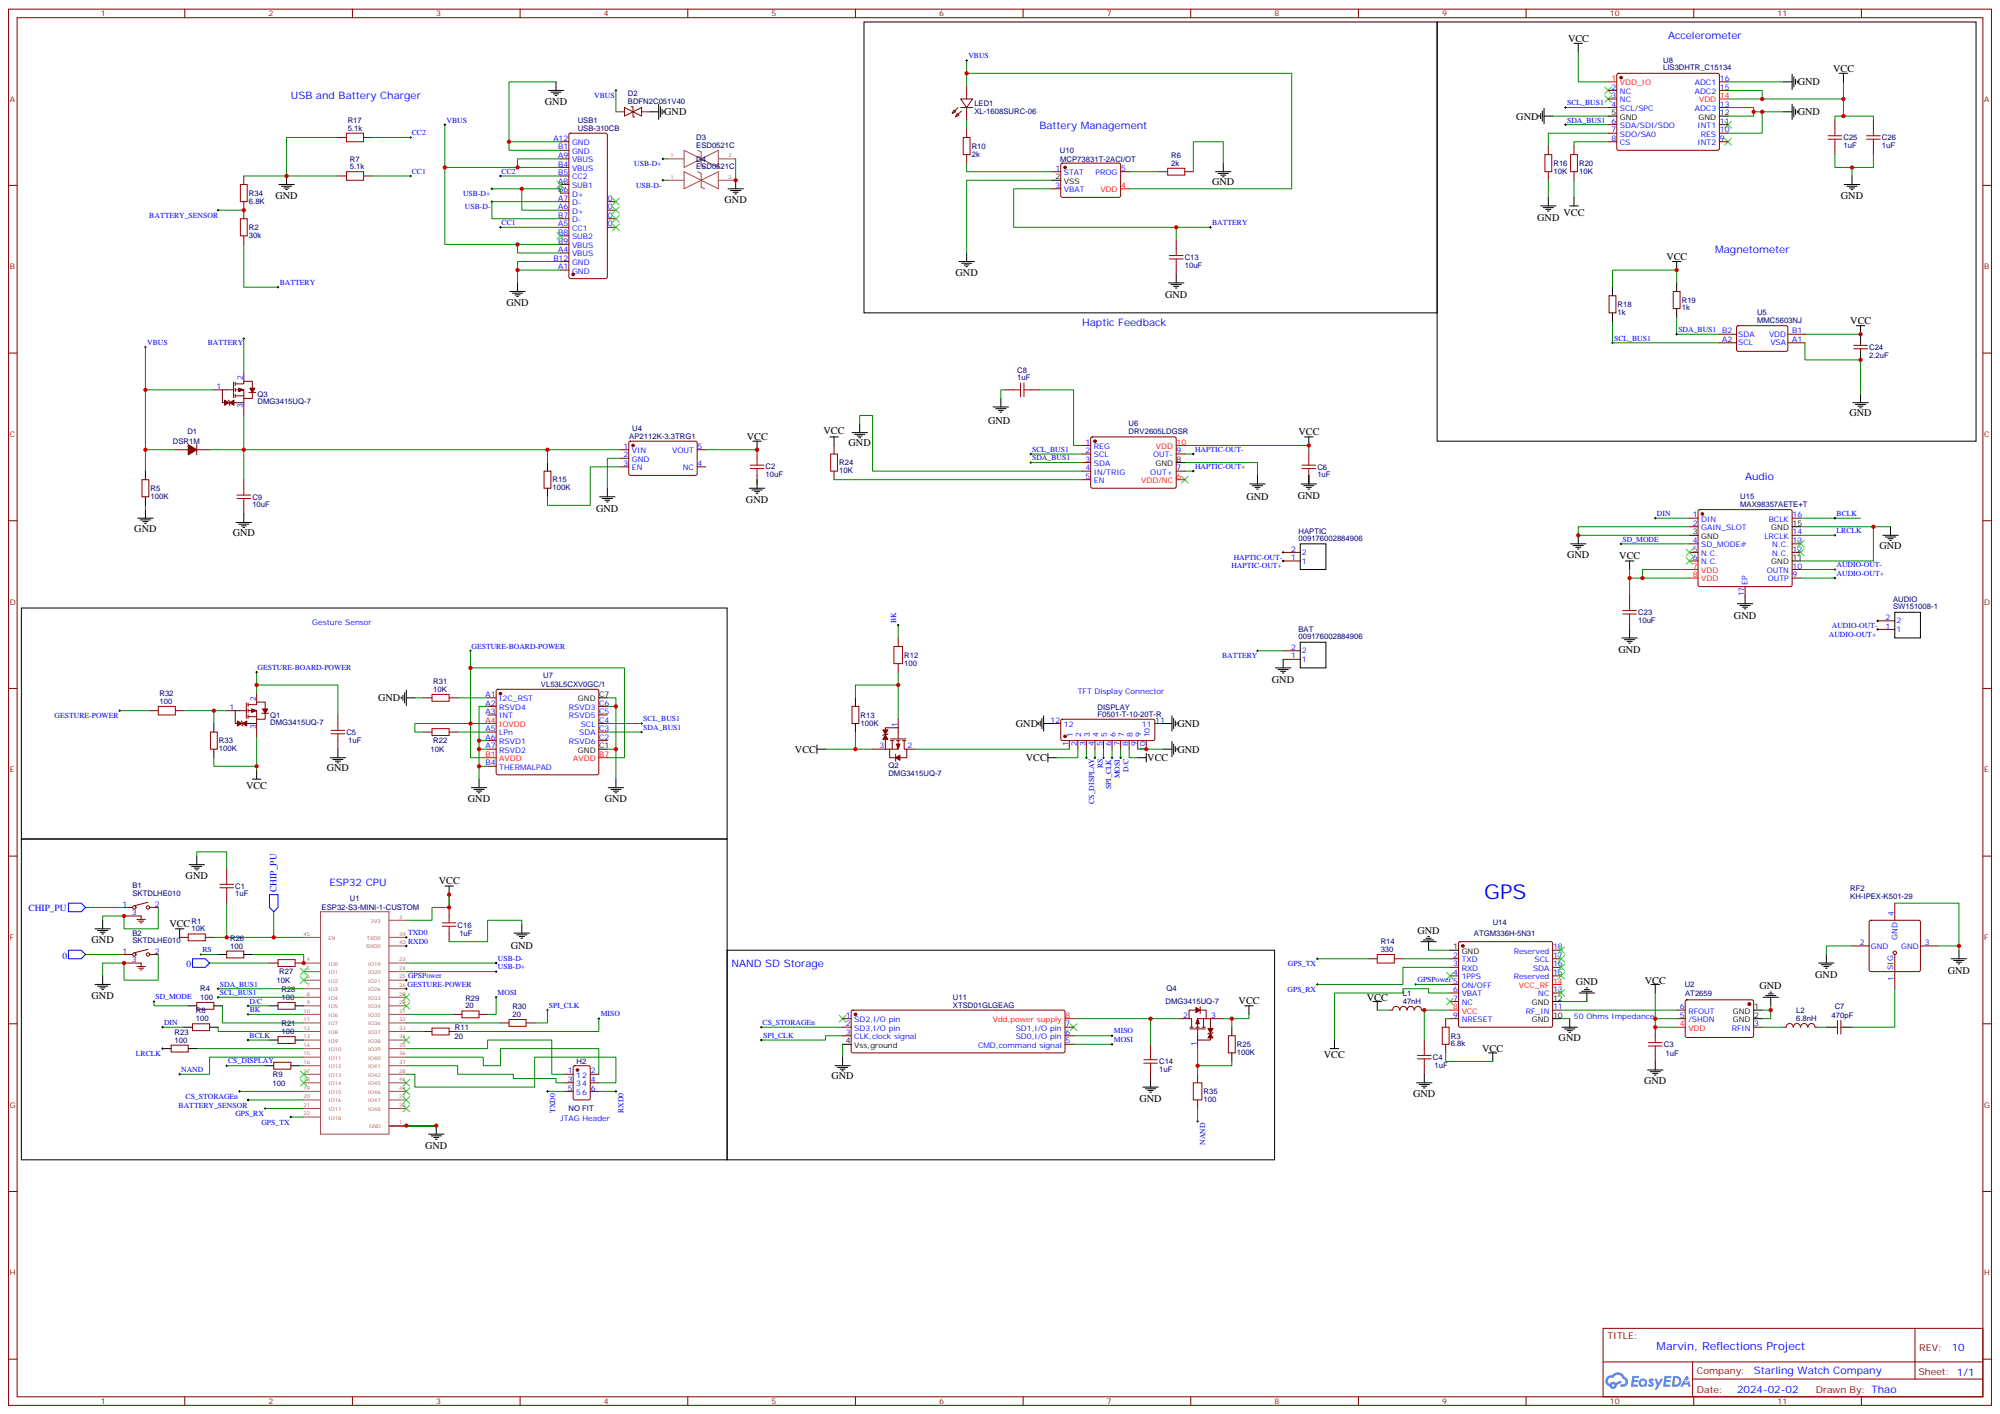
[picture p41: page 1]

Company: Starling Watch Company

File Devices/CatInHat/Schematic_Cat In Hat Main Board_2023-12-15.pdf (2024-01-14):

## Haptic Feedback

## USB and Battery Charger

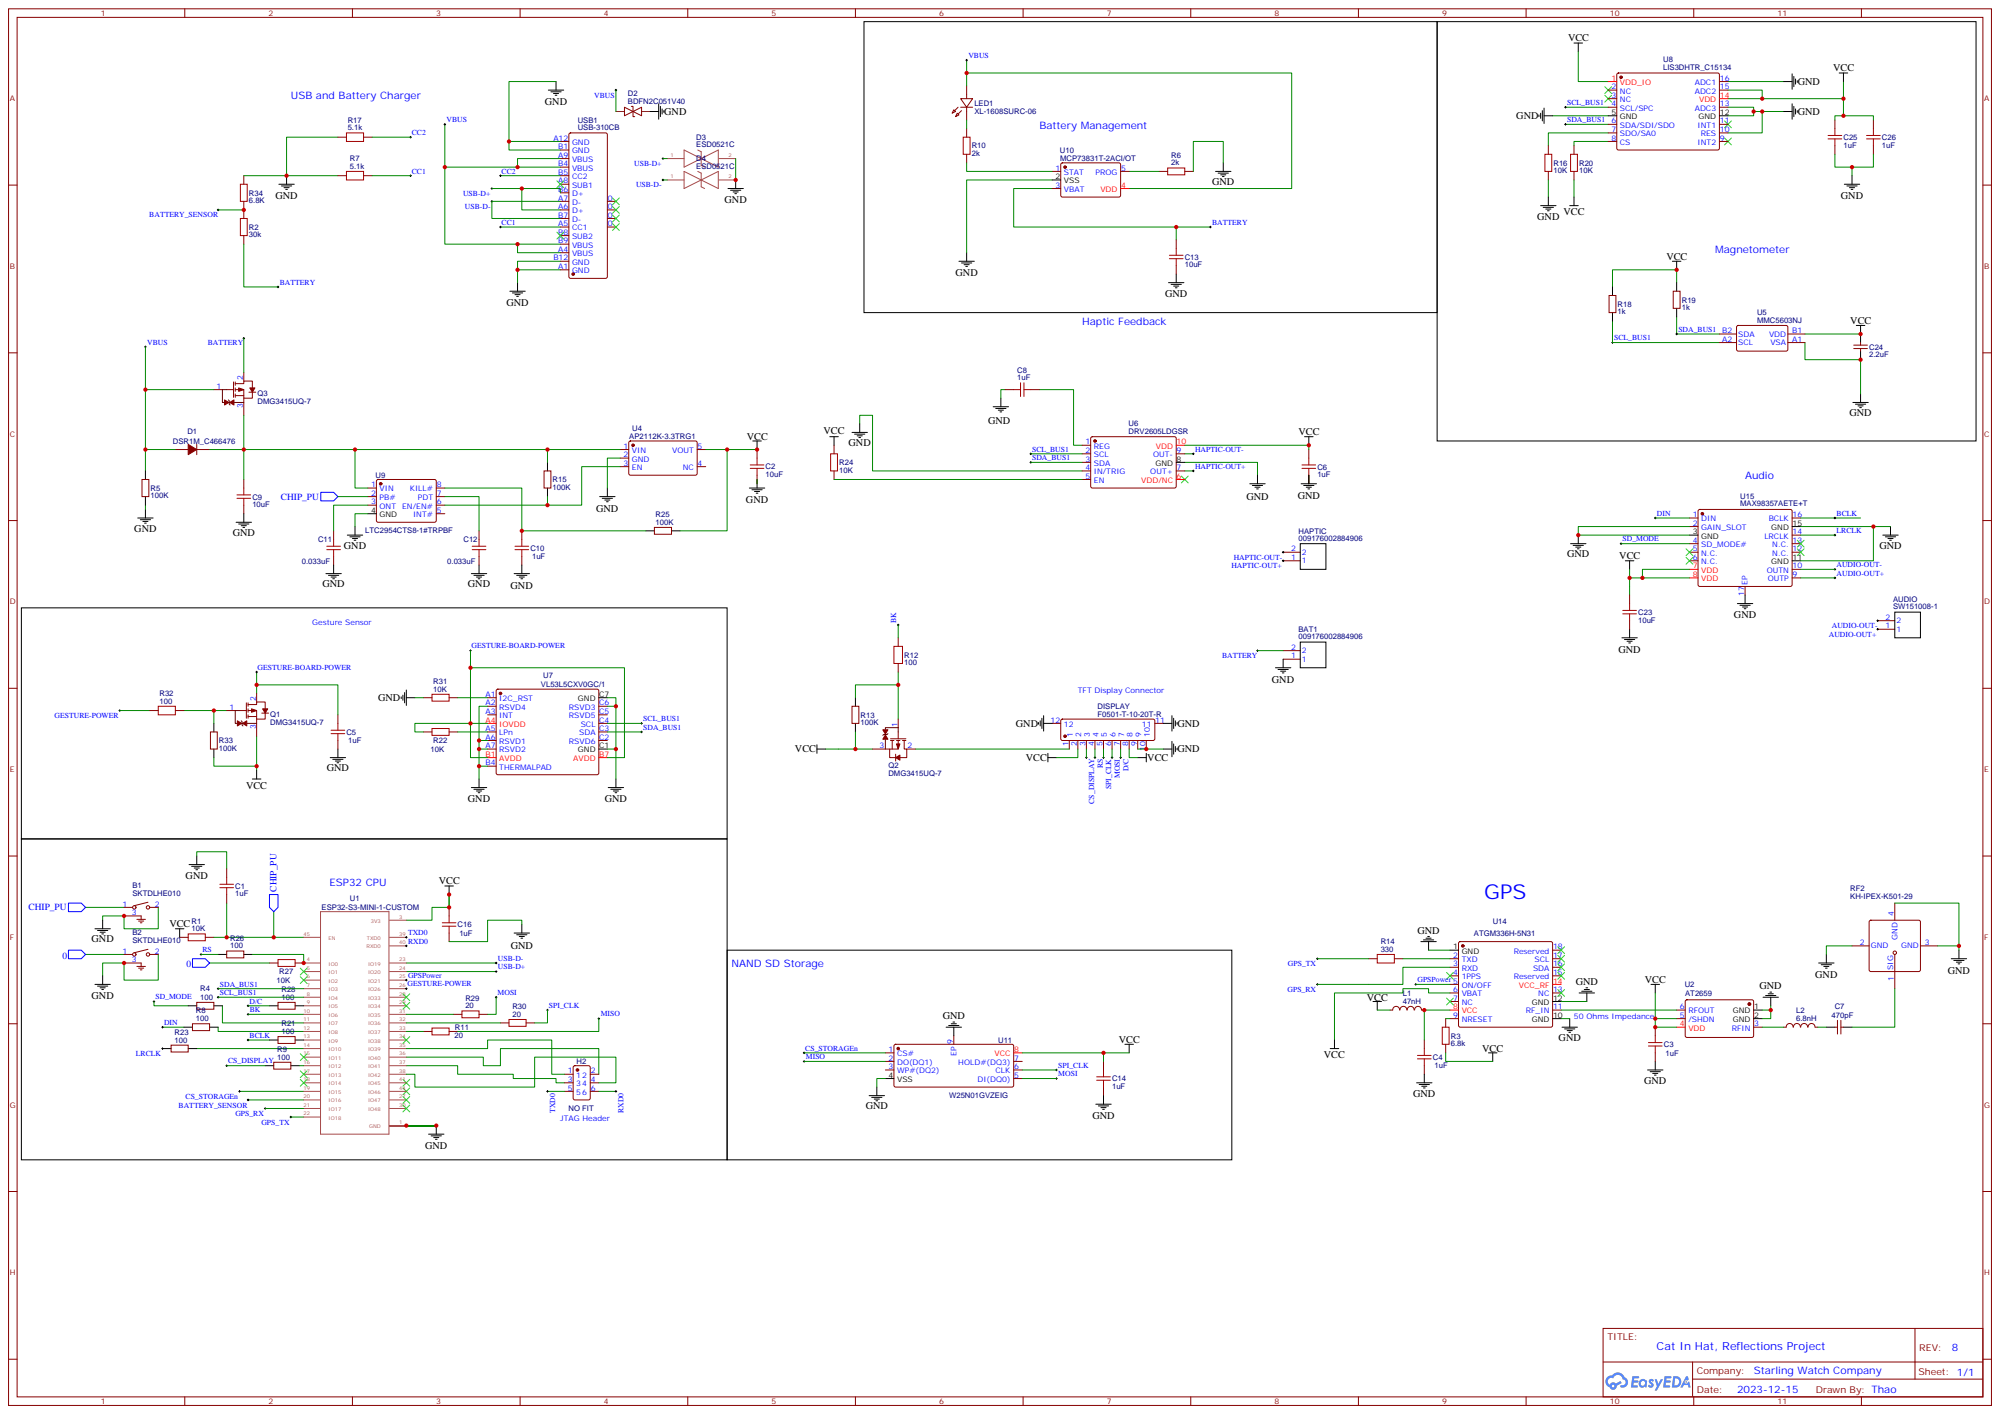
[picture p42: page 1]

Company: Starling Watch Company

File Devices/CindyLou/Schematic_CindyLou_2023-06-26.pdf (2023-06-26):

## Haptic Feedback

## USB and Battery Charger

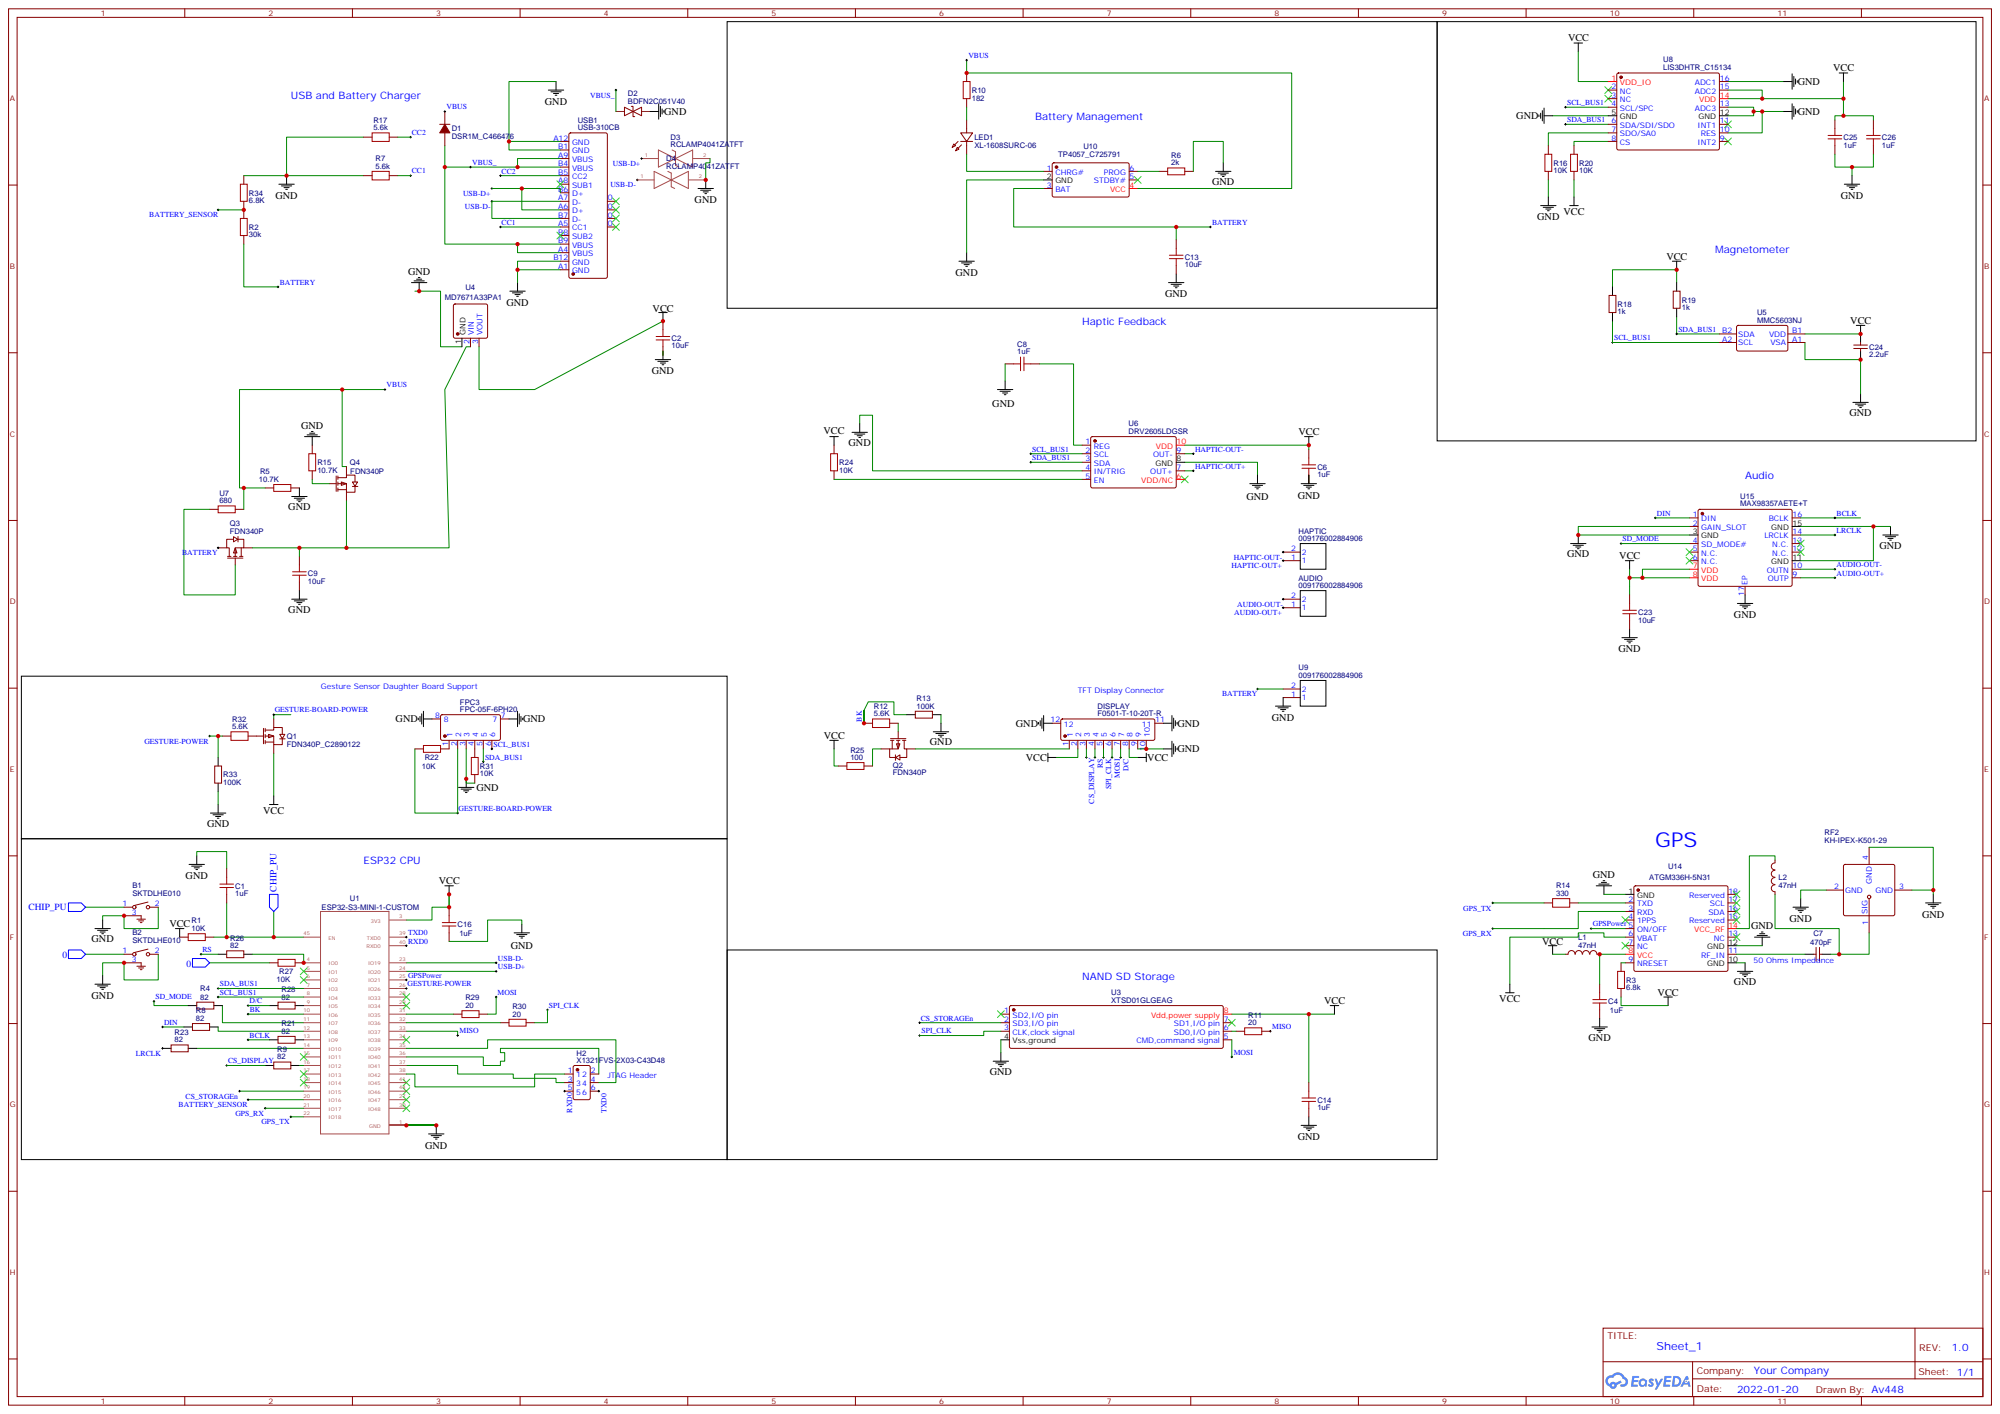
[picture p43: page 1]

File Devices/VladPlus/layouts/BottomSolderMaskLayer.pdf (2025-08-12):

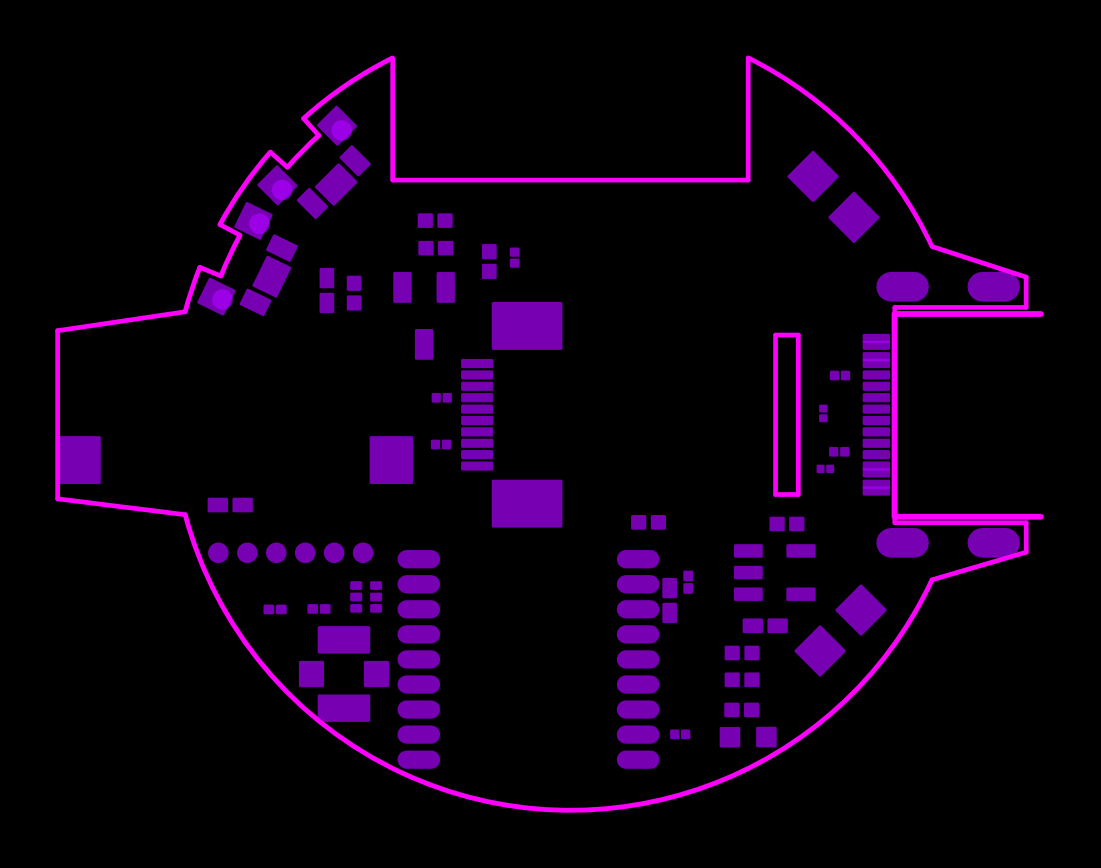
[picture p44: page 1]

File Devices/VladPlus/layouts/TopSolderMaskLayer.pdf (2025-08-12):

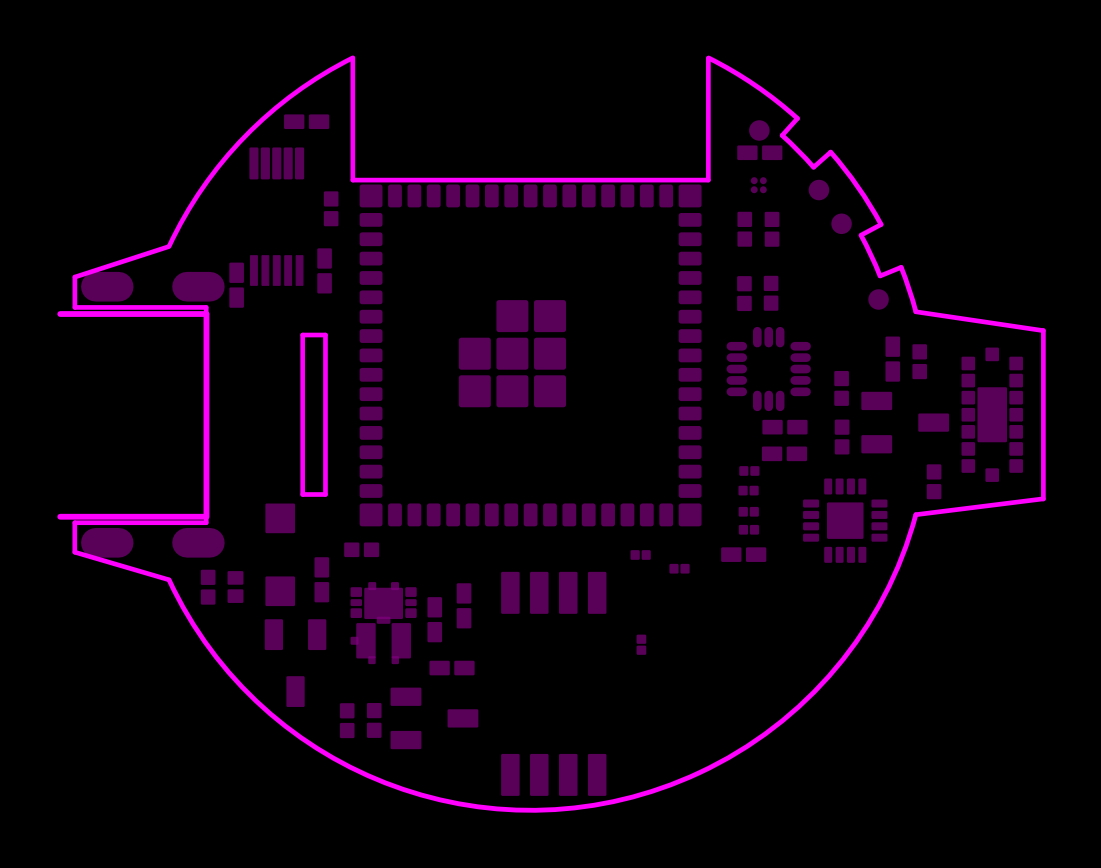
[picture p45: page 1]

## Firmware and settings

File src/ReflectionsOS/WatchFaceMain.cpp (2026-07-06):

/*
 Reflections, mobile connected entertainment device

 Repository is at https://github.com/frankcohen/ReflectionsOS
 Includes board wiring directions, server side components, examples, support

 Licensed under GPL v3 Open Source Software
 (c) Frank Cohen, All rights reserved. fcohen@starlingwatch.com
 Read the license in the license.txt file that comes with this code.

 Requires PNGdec library https://github.com/bitbank2/PNGdec

*/

#include "WatchFaceMain.h"

// -----------------------------------------------------------------------------
// Shared state for Set Time + Confirm Set Time behavior
// -----------------------------------------------------------------------------
static void clearSetTimeExitNoise();

static int g_confirmHour = 0;
static int g_confirmMin  = 0;

static int g_lastSigHour = -1;
static int g_lastSigMin  = -1;

// Set Time protected mode blocks all experiences/BLE/sleep interruptions until
// the return-to-main transition video has finished.
static bool g_setTimeProtected = false;

// Digital Time tap gate: clear taps for 2 seconds on entry
static uint32_t g_displayTimeTapGateStart = 0;
static const uint32_t DISPLAYTIME_TAP_GATE_MS = 2000;

// Set Time tilt gate: one accepted change requires tilt -> stable hold -> neutral.
// Set Time tilt auto-repeat.
// First accepted change requires stable tilt.
// Holding the tilt repeats changes at SETTIME_REPEAT_MS.
// Returning to center resets the repeat.
static int g_setTimeTiltDirection = 0;
static uint32_t g_setTimeTiltStartedAt = 0;
static uint32_t g_setTimeTiltLastStepAt = 0;

static const float SETTIME_TILT_THRESHOLD = 3.0f;
static const float SETTIME_NEUTRAL_THRESHOLD = 1.4f;
static const uint32_t SETTIME_INITIAL_STABLE_MS = 300;
static const uint32_t SETTIME_HOUR_INITIAL_STABLE_MS = 500;   // slower first hour step
static const uint32_t SETTIME_REVERSE_STABLE_MS = 150;        // easier reversal after overshoot
static const uint32_t SETTIME_REPEAT_MS = 300;
static const uint32_t SETTIME_HOUR_REPEAT_MS = 800;   // slower hour changes to avoid overshoot  // Hours change 25% slower than minutes

static uint32_t g_ignoreTofUntil = 0;

static void resetOrientationGestureState()
{
  accel.resetSetTimeTwistGesture();
}

static void resetSetTimeTiltGate()
{
  g_setTimeTiltDirection = 0;
  g_setTimeTiltStartedAt = 0;
  g_setTimeTiltLastStepAt = 0;
}

// Returns -1 for left tilt, +1 for right tilt, 0 for no step.
static int getSetTimeTiltStep(uint32_t repeatMs, uint32_t initialStableMs = SETTIME_INITIAL_STABLE_MS, uint32_t reverseStableMs = SETTIME_INITIAL_STABLE_MS)
{
  const uint32_t now = millis();
  const float xraw = accel.getXreading();

  if (fabs(xraw) <= SETTIME_NEUTRAL_THRESHOLD)
  {
    resetSetTimeTiltGate();
    return 0;
  }

  int dir = 0;

  if (xraw >= SETTIME_TILT_THRESHOLD) dir = 1;
  else if (xraw <= -SETTIME_TILT_THRESHOLD) dir = -1;
  else return 0;

  // New tilt direction starts timing.
  // If the user reverses after a step, accept the reverse direction faster.
  // This makes it easier to correct a one-hour overshoot.
  if (dir != g_setTimeTiltDirection)
  {
    bool reversingAfterStep = (g_setTimeTiltDirection != 0) && (g_setTimeTiltLastStepAt != 0);

    g_setTimeTiltDirection = dir;
    g_setTimeTiltStartedAt = now;

    if (reversingAfterStep)
    {
      g_setTimeTiltLastStepAt = now - reverseStableMs;
    }
    else
    {
      g_setTimeTiltLastStepAt = 0;
    }

    return 0;
  }

  // First step after stable hold.
  if (g_setTimeTiltLastStepAt == 0)
  {
    if (now - g_setTimeTiltStartedAt >= initialStableMs)
    {
      g_setTimeTiltLastStepAt = now;
      return dir;
    }

    return 0;
  }

  // Auto-repeat while still tilted.
  if (now - g_setTimeTiltLastStepAt >= repeatMs)
  {
    g_setTimeTiltLastStepAt = now;
    return dir;
  }

  return 0;
}

// Wrap-safe minute diff, e.g. 59 -> 0 is diff 1
static int minuteDiffWrap(int a, int b)
{
  int d = abs(a - b);
  if (d > 30) d = 60 - d;
  return d;
}

// -----------------------------------------------------------------------------
// Twist helper (resettable)
// -----------------------------------------------------------------------------
static uint32_t g_twistLastPoll = 0;
static uint32_t g_twistLastFire = 0;

static void resetTwistDetector()
{
  // Prevent any immediate fire right after a panel change
  g_twistLastPoll = millis();
  g_twistLastFire = millis(); 
}

static void flushTwistDetector()
{
  // Drain any internal "2-hit" state in AccelSensor by reading it
  (void)accel.getWristTwistDir();
}

static bool twistTriggered()
{
  // Poll at a calm rate
  if (millis() - g_twistLastPoll < 200) return false;
  g_twistLastPoll = millis();

  // Extra cooldown
  if (millis() - g_twistLastFire < 700) return false;

  int dir = accel.getWristTwistDir();
  if (dir != 0)
  {
    g_twistLastFire = millis();
    return true;
  }
  return false;
}

WatchFaceMain::WatchFaceMain()
  : WatchFaceBase() // Call to the base class constructor
{}

void WatchFaceMain::begin()
{
  WatchFaceBase::begin();  // This ensures the base method is executed

  maintimer = millis();

  drawitall = true;
  drawFace = false;

  catFaceIndex = 1;
  catFaceTimer = millis();
  catFaceDirection = true;
  catFaceWait = rand() % 30000;

  tilttimer = millis();

  // Baseline ranges (used elsewhere, and as a reference)
  smallX = -6;
  largeX = 6;
  smallY = 7;
  largeY = -7;

  battimer = millis();
  batcount = battery.getBatteryLevel();
  batlev = 0;

  oldHour = 0;
  oldMinute = 0;
  oldBattery = 5;
  oldBlink = 1;

  gpsflag = false;
  gpsx = 0;
  gpsy = 0;
  gpsdirection = 0;

  notificationflag = false;

  slowman = millis();

  digitalWrite(Display_SPI_BK, LOW);  // Turn display backlight on

  panel = STARTUP;

  textmessageservice.deactivate();

  temptimer = millis();

  minuteRedrawtimer = millis();

  movesOld = 0;

  mainwaiter = millis();

  _runmode = true;
}

void WatchFaceMain::setDrawItAll()
{
  drawitall = true;
}

// helper: map float
float WatchFaceMain::mapFloat(float x, float in_min, float in_max, float out_min, float out_max)
{
  return (x - in_min) * (out_max - out_min) / (in_max - in_min) + out_min;
}

// GPS marker
void WatchFaceMain::updateGPSmarker()
{
  if ( gps.isActive() )
  {
    float gpsCourse = gps.getCourse(); // Course angle in degrees

    if ( gpsdirection > 360 ) gpsdirection = 0;

    int imageSize = 24; // Image size (24x24)
    int centerX = 120; // Center of the 240x240 screen
    int centerY = 120;
    int radius = 100;

    float angleRad = radians( gpsCourse );

    // Calculate the position to place the top-left corner of the image
    gpsx = centerX + radius * cos(angleRad) - (imageSize / 2);
    gpsy = centerY + radius * sin(angleRad) - (imageSize / 2);
  }
}

// Timer notice indicator
void WatchFaceMain::updateTimerNotice()
{
  notificationflag = timerservice.status();
}

// Battery indicator grows/loses leaves
void WatchFaceMain::updateBattery()
{
  if ( drawitall || ( millis() - battimer ) > ( 2 * 60000 ) )
  {
    battimer = millis();

    batlev = battery.getBatteryLevel();

    if ( ( batlev != batcount ) && ( batcount < 5 ) )
    {
      batcount = batlev;
      displayUpdateable = true;
    }
  }
}

// Hour and minutes hands to current time
void WatchFaceMain::updateHoursAndMinutes()
{
  int hour2 = realtimeclock.getHour();
  int minute2 = realtimeclock.getMinute();

  if ( hour2 != hour )
  {
    hour = hour2;
    displayUpdateable = true;
    drawFace = true;
  }

  if ( minute2 != minute )
  {
    minute = minute2;
    displayUpdateable = true;
    drawFace = true;
  }
}

// Cat blinks eyes
void WatchFaceMain::updateBlink()
{
  if ( ! blinking )
  {
    if ( ( millis() - catFaceTimer ) > catFaceWait )
    {
      catFaceTimer = millis();
      blinking = true;
      catFaceDirection = true;
    }
  }
  else
  {
    if ( catFaceDirection )
    {
      catFaceIndex++;
      displayUpdateable = true;

      if ( catFaceIndex > 5 )
      {
        catFaceDirection = false;
        catFaceIndex = 5;
      }
    }
    else
    {
      catFaceIndex--;
      displayUpdateable = true;

      if ( catFaceIndex < 1 )
      {
        catFaceDirection = true;
        catFaceIndex = 1;
        blinking = false;
        catFaceTimer = millis();
        catFaceWait = rand() % 30000;
      }
    }
  }
}

// Draw the elements to the display
void WatchFaceMain::showDisplayMain()
{
  if ( ! displayUpdateable ) return;
  displayUpdateable = false;

  if ( drawitall ) drawImageFromFile( wfMainBackground, true, 0, 0 );

  String mef;

  // Draw hour image
  if ( ( hour != oldHour ) || drawitall )
  {
    oldHour = hour;

    if ( hour > 12 ) hour = 12;   // Just to be safe

    mef = wfMainHours;
    mef += hour;
    mef += wfMainHours2;
    drawImageFromFile( mef, true, 0, 0 );
  }

  if ( ( minute != oldMinute ) || drawitall )
  {
    oldMinute = minute;
    int mymin = map( minute, 1, 60, 0, 23);
    if ( mymin > 23 ) mymin = 23;   // Just to be safe

    mef = wfMainMinutes;
    mef += mymin ;
    mef += wfMainMinutes2;
    drawImageFromFile( mef, true, 0, 0 );
  }

  // Battery indicator
  if ( ( batcount != oldBattery ) || drawitall )
  {
    oldBattery = batcount;

    mef = wfMainBattery;
    mef += batcount;
    mef += wfMainBattery2;
    drawImageFromFile( mef, true, 0, 0 );
  }

  // Timer indicator
  if ( notificationflag )
  {
    mef = wfMain_Face_Main_TimerNotice;
    drawImageFromFile( mef, true, 0, 0 );
  }

  // Cat face in the middle, and he blinks randomly
  if ( ( catFaceIndex != oldBlink ) || drawitall || drawFace )
  {
    oldBlink = catFaceIndex;
    drawFace = false;

    mef = wfMainFace;
    mef += catFaceIndex;
    mef += wfMainFace2;
    drawImageFromFile( mef, true, 0, 0 );
  }

  if ( gpsflag )
  {
    mef = wfMain_GPSmarker;
    drawImageFromFile( mef, true, gpsx, gpsy );
  }

  show();

  drawitall = false;
}

// Draws hour glass time left display, 3, 2, 1
// Returns true when time is up
bool WatchFaceMain::updateTimeLeft()
{
  if ( panel == MAIN ) return false;

  int index = 1;

  if ( ( millis() - noMovementTime ) > ( nomov * 1 ) ) index = 2;
  if ( ( millis() - noMovementTime ) > ( nomov * 2 ) ) index = 3;
  if ( ( millis() - noMovementTime ) > ( nomov * 3 ) ) index = 4;

  if ( ( millis() - noMovementTime ) > ( nomov * 4 ) )
  {
    return true;
  }

  mef = wfMainHourglass;
  mef += index;
  mef += wfMainHourglass2;

  drawImageFromFile( mef, true, 0, 0 );

  show();

  return false;
}

void WatchFaceMain::printStatus()
{
  if ( millis() - temptimer > 2000 )
  {
    temptimer = millis();

    String mef = "WatchFaceMain ";

    if ( video.getStatus() ) mef += "1 ";
    else mef += "0 ";

    if ( textmessageservice.active() ) mef += "1 ";
    else mef += "0 ";

    Serial.println( mef );
  }

  return;
}

bool WatchFaceMain::isMain()
{
  if ( panel == MAIN ) return true;
  return false;
}

bool WatchFaceMain::isMainOrTime()
{
  if ( panel == MAIN ) return true;
  if ( panel == DISPLAYING_TIME ) return true;
  return false;
}


void WatchFaceMain::loop()
{
  // If we are returning from Set Time, keep experiences blocked until the
  // transition-to-main video has completely finished.
  if ( g_setTimeProtected && ( panel == MAIN ) && ( ! video.getStatus() ) )
  {
    Serial.println( F("SET_TIME: experiences re-enabled") );
    g_setTimeProtected = false;
  }

  if ( video.getStatus() ) return;

  switch ( panel )
  {
    case STARTUP:
      startup();
      break;

    case MAIN:
      main();
      break;

    case DISPLAYING_TIME:
      displaytime();
      break;

    case SETTING_TIME:
      settingtime();
      break;

    case SETTING_MINUTE:
      settingminute();
      break;

    case CONFIRM_SETTING_TIME:
      confirmsettingtime();
      break;

    case DISPLAYING_MOVES:
      displayingmoves();
      break;

    case CONFIRM_CLEAR_MOVES:
      confirmclearmoves();
      break;

    case DISPLAYING_TIMER:
      displayingtimer();
      break;

    case SETTING_TIMER:
      settingtimer();
      break;

    case CONFIRM_START_TIMER:
      confirmstarttimer();
      break;
  }

  // Do not use the generic panel timeout while Set Time is active. Set Time
  // advances itself using the hourglass/updateTimeLeft() flow.
  if ( ( ( millis() - noMovementTime ) > 20000 ) && ( panel != MAIN ) && !isSettingTime() )
  {
    changeTo( MAIN, true, WatchFaceFlip3_video );
    return;
  }

  // Force a redraw periodically, to move the minutes hand
  if ( millis() - minuteRedrawtimer > 100000 )
  {
    setDrawItAll();
    showDisplayMain();
    minuteRedrawtimer = millis();
  }
}

bool WatchFaceMain::isSettingTime()
{
  if ( g_setTimeProtected ) return true;

  if ( ( panel == SETTING_TIME ) || ( panel == SETTING_MINUTE ) ||
       ( panel == CONFIRM_SETTING_TIME ) ||
       ( panel == SETTING_TIMER ) || ( panel == CONFIRM_START_TIMER ) ) return true;

  return false;
}

void WatchFaceMain::changeTo( int panelnum, bool setup, String videoname )
{
  panel = panelnum;
  needssetup = setup;
  textmessageservice.stop();
  if ( videoname != "none" ) video.startVideo( videoname );
  noMovementTime = millis();
  sleepservice.notifyWatchFaceActivity();

  accel.resetTaps();
  (void)accel.getSingleTap();
  (void)accel.getDoubleTap();

  while (tof.getGesture() != GESTURE_NONE)
  {
    delay(1);
  }
}

void WatchFaceMain::startup()
{
  panel = MAIN;
  needssetup = true;
  blinking = false;
  textmessageservice.deactivate();
  resetOrientationGestureState();
  sleepservice.notifyWatchFaceActivity();
}

void WatchFaceMain::main()
{
  if ( needssetup )
  {
    Serial.println( F("MAIN") );
    needssetup = false;
    drawitall = true;
    blinking = false;
    mainwaiter = millis();
    resetOrientationGestureState();

    Serial.println(F("MAIN: TOF flush"));
    tof.getGesture();
    accel.resetSetTimeTwistGesture();
    accel.suppressSetTimeTwistFor(300);

    return;
  }

  // If the TOF sensor is being covered for Sleep, do not allow a stale or
  // walking-induced accelerometer twist to steal the interaction and switch
  // to Digital Time. TOF Sleep has priority on MAIN.
  if ( tof.isSleepCoverInProgress() )
  {
    accel.resetSetTimeTwistGesture();
    accel.suppressSetTimeTwistFor(300);
    return;
  }

  // MAIN: consume high-level twist events from AccelSensor.
  if ( millis() - mainwaiter > 2000 )
  {
    if ( accel.getSetTimeTwistSetTime() )
    {
      Serial.println(F("MAIN: Accel twist event -> Set Time"));

      haptic.playEffect(66);
      delay(120);
      haptic.playEffect(14);

      g_ignoreTofUntil = millis() + 3000;
      g_setTimeProtected = true;

      textmessageservice.stop();
      drawImageFromFile( wfMain_Time_Background, true, 0, 0 );

      panel = SETTING_TIME;
      needssetup = true;
      textmessageservice.stop();
      noMovementTime = millis();
      sleepservice.notifyWatchFaceActivity();

      return;
    }

    if ( accel.getSetTimeTwistDigitalTime() )
    {
      Serial.println(F("MAIN: Accel twist event -> Digital Time"));
      g_ignoreTofUntil = millis() + 2000;
      changeTo( DISPLAYING_TIME, true, WatchFaceFlip1_video );
      haptic.playEffect(66);
      return;
    }

  }

  // Single tap does nothing on MAIN (per your flow)

  if ( ( millis() - maintimer > 50 ) && ( ! video.getStatus() ) )
  {
    maintimer = millis();

    updateBlink();            // Blink eyes
    updateBattery();          // Battery level indicator
    updateHoursAndMinutes();  // Hour and minute hands
    // updateTimerNotice();   // Timer notice (disabled for shipment)
    // updateGPSmarker();     // GPS marker (disabled for shipment)

    showDisplayMain();
  }
}

// -----------------------------------------------------------------------------
// Digital Time: tap -> suppress twist window
// -----------------------------------------------------------------------------

static uint32_t g_lastTapMs = 0;
static const uint32_t TAP_SUPPRESS_TWIST_MS = 500;

// at top of file (near your other statics)
static bool g_displayTimeDrained = false;

void WatchFaceMain::displaytime()
{
  if ( needssetup )
  {
    needssetup = false;

    Serial.println( F("DISPLAYING_TIME") );
    noMovementTime = millis();

    g_displayTimeTapGateStart = millis();
    g_displayTimeDrained = false;

    // Drain stale events ONCE on entry (from MAIN / transition)
    (void)accel.getSingleTap();
    (void)accel.getDoubleTap();
    g_displayTimeDrained = true;

    drawImageFromFile( wfMain_Time_Background, true, 0, 0 );
    textmessageservice.startShow( TextMessageExperiences::DigitalTime, "", "" );
    return;
  }

  // Keep the 2 second settle, but DON'T drain during it.
  if ( millis() - g_displayTimeTapGateStart < DISPLAYTIME_TAP_GATE_MS )
  {
    return;
  }

  // Time setting now uses REST hold, not knocks/taps.
  (void)accel.getDoubleTap();

  // After settle: Twist => back to MAIN
  if ( twistTriggered() )
  {
    Serial.println("Displaying_Time got a Twist" );
    changeTo( MAIN, true, WatchFaceFlip3_video );
    return;
  }

  // Single tap does nothing here
}

void WatchFaceMain::settingtime()
{
  if ( needssetup )
  {
    Serial.println( F("SETTING_TIME: HOUR") );
    needssetup = false;
    noMovementTime = millis();

    // Clear stale gesture state so previous taps/tilts cannot alter time.
    accel.resetTaps();
    (void)accel.getSingleTap();
    (void)accel.getDoubleTap();
    resetSetTimeTiltGate();

    hour = realtimeclock.getHour();
    minute = realtimeclock.getMinute();
    if ( hour < 1 || hour > 12 ) hour = 12;
    if ( minute < 0 || minute > 59 ) minute = 0;

    g_confirmHour = hour;
    g_confirmMin  = minute;

    drawSetTimePanel( F("Hours"), hour, minute, F(""), F("") );
    haptic.playEffect( 4 );
    return;
  }

  sleepservice.notifyWatchFaceActivity();

  if ( updateTimeLeft() )
  {
    g_confirmHour = hour;
    Serial.print( F("SETTING_TIME: hour accepted by hourglass = ") );
    Serial.println( g_confirmHour );
    haptic.playEffect( 4 );
    changeTo( SETTING_MINUTE, true, "none" );
    return;
  }

  int step = getSetTimeTiltStep(SETTIME_HOUR_REPEAT_MS, SETTIME_HOUR_INITIAL_STABLE_MS, SETTIME_REVERSE_STABLE_MS);
  if ( step != 0 )
  {
    hour += step;
    if ( hour > 12 ) hour = 1;
    if ( hour < 1 ) hour = 12;

    g_confirmHour = hour;
    noMovementTime = millis();
    drawSetTimePanel( F("Hours"), hour, minute, F(""), F("") );
    haptic.playEffect( 14 );

    Serial.print( F("Hour = ") );
    Serial.println( hour );
  }
}

void WatchFaceMain::settingminute()
{
  if ( needssetup )
  {
    Serial.println( F("SETTING_TIME: MINUTE") );
    needssetup = false;
    noMovementTime = millis();

    accel.resetTaps();
    (void)accel.getSingleTap();
    (void)accel.getDoubleTap();
    resetSetTimeTiltGate();

    drawSetTimePanel( F("Minutes"), hour, minute, F(""), F("") );
    haptic.playEffect( 14 );
    return;
  }

  sleepservice.notifyWatchFaceActivity();

  if ( updateTimeLeft() )
  {
    g_confirmHour = hour;
    g_confirmMin  = minute;

    Serial.printf("Accepted new time setting: %d:%02d\n", g_confirmHour, g_confirmMin);
    realtimeclock.setHourMinute(g_confirmHour, g_confirmMin);
    realtimeclock.saveClockToNVS();

    realtimeclock.setHourMinute(g_confirmHour, g_confirmMin);
    realtimeclock.saveClockToNVS();

    clearSetTimeExitNoise();
    
    noMovementTime = millis();
    sleepservice.notifyWatchFaceActivity();

    haptic.playEffect( 76 );
    changeTo( MAIN, true, WatchFaceFlip3_video );
    return;
  }

  int step = getSetTimeTiltStep(SETTIME_REPEAT_MS);
  if ( step != 0 )
  {
    minute += step;
    if ( minute > 59 ) minute = 0;
    if ( minute < 0 ) minute = 59;

    g_confirmMin = minute;
    noMovementTime = millis();
    drawSetTimePanel( F("Minutes"), hour, minute, F(""), F("") );
    haptic.playEffect( 14 );

    Serial.print( F("Minute = ") );
    Serial.println( minute );
  }
}

void WatchFaceMain::drawHourMinute( int hourc, int minutec )
{
  drawSetTimePanel( F("Set Time"), hourc, minutec, F(""), F("") );
}

void WatchFaceMain::drawSetTimePanel( String title, int hourc, int minutec, String help1, String help2 )
{
  // Show minutes/hours
  String mef = String( hourc );
  mef += F(":");
  if ( minutec < 10 ) mef += F("0");
  mef += String( minutec );

  Serial.print( "drawSetTimePanel " );
  Serial.print( mef );
  Serial.println( "." );

  drawImageFromFile( wfMain_SetTime_Background_Shortie, true, 0, 0 );
  textmessageservice.updateTempTime( mef );

  // Mode message: Hours or Minutes
  gfx->setFont(&ScienceFair14pt7b);
  gfx->setTextSize(0);
  gfx->setTextColor( COLOR_PANTONE_102 );
  gfx->setCursor( 50, 105 );
  gfx->println( title );

  digitalWrite(Display_SPI_BK, LOW);
}

static void clearSetTimeExitNoise()
{
  accel.resetTaps();

  (void)accel.getSingleTap();
  (void)accel.getDoubleTap();

  resetSetTimeTiltGate();

  resetOrientationGestureState();

  textmessageservice.stop();
  textmessageservice.deactivate();

  while (tof.getGesture() != GESTURE_NONE)
  {
    delay(1);
  }
}

void WatchFaceMain::confirmsettingtime()
{
  // The new Blaine flow no longer uses a separate confirm panel. If an old
  // transition ever reaches here, save and return to main safely.
  if ( needssetup )
  {
    Serial.println( F("CONFIRM_SETTING_TIME: legacy fallback") );
    textmessageservice.stop();
    textmessageservice.deactivate();
    needssetup = false;
  }

  realtimeclock.setHourMinute(g_confirmHour, g_confirmMin);
  realtimeclock.saveClockToNVS();
  changeTo( MAIN, true, WatchFaceFlip3_video );
}
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

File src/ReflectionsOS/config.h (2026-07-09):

/*
Reflections, distributed entertainment device

What started as a project to wear videos of my children as they grew up on my
arm as a wristwatch, grew to be a platform for making entertaining experiences.
This is the software component. It runs on an ESP32-based platform with OLED display,
audio player, flash memory, GPS, gesture sensor, and accelerometer/compass

Repository is at https://github.com/frankcohen/ReflectionsOS
Includes board wiring directions, server side components, examples, support

Licensed under GPL v3 Open Source Software
(c) Frank Cohen, All rights reserved. fcohen@starlingwatch.com
Read the license in the license.txt file that comes with this code.

*/

#ifndef _config_
#define _config_

/* Collector/demo display modes
   Select exactly one of these modes.

   STUNT_CAT_MODE:
     1 = Michelle Sarrow / Stunt Cat collector demo mode

   PEGASUS_LOFT_MODE:
     1 = Jorge's Pegasus Loft inaugural display mode, serial #1 of 200

   When either mode is 1, ReflectionsOS boots into a watchable/demo loop
   that cycles all configured Cheshire Cat experience videos instead of
   running the normal interactive watch behavior.
*/
#define STUNT_CAT_MODE 0

#define PEGASUS_LOFT_MODE 0

// When true, BoardInitializationUtility always downloads/unpacks the Cloud City assets.
// Set back to 0 after rebuilding NAND, otherwise every boot reinitializes assets.
#define FORCE_BOARD_INITIALIZATION 0

// Board Initialization Utility benchmark mode.
// 0 = normal operation.
// 1 = connect to WiFi, run network/SD speed tests, then stop before replicate/extract.
#define RUN_BOARD_INIT_BENCHMARKS 0

#if STUNT_CAT_MODE && PEGASUS_LOFT_MODE
#error "Select only one collector/demo display mode"
#endif

#define DEMO_CAT_MODE (STUNT_CAT_MODE || PEGASUS_LOFT_MODE)

/*
   For cased gallery/display installs, the watch must come on whenever USB
   power is applied and must not require the wake button. This disables
   inactivity deep sleep, low-battery boot sleep, and REST/shipping sleep while
   in a collector/demo display mode.
*/
#define DEMO_CAT_ALWAYS_ON  DEMO_CAT_MODE


//
// Simulator Color Palette
//

// Background
#define COLOR_BACKGROUND        0x0B2D66    // Deep Blue

// Character
#define COLOR_HEAD              0x5FE3D7    // Aquamarine
#define COLOR_EYE               0xFFD54A    // Golden Yellow
#define COLOR_PUPIL             0x000000    // Black

// Behavior Labels
#define COLOR_WAKE              0x6CFF6C    // Bright Spring Green
#define COLOR_TAP               0xFF8A1E    // Rich Orange
#define COLOR_SHAKE             0xFF4B4B    // Bright Red
#define COLOR_IDLE              0x73E8FF    // Soft Aqua
#define COLOR_SLEEP             0xB77CFF    // Lavender Purple

// Status / Debug
#define COLOR_ERROR             0xFF2FCF    // Magenta
#define COLOR_SUCCESS           0x00FF99    // Bright Mint
#define COLOR_WARNING           0xFFC107    // Amber
#define COLOR_INFO              0x66CCFF    // Sky Blue

// General UI
#define COLOR_TEXT              0xFFFFFF    // White
#define COLOR_TEXT_DIM          0xB0B0B0    // Light Gray
#define COLOR_OUTLINE           0x0A0A0A    // Nearly Black
#define COLOR_SHADOW            0x202020    // Dark Gray


/* Experience videos */

#define OutOfTheBox_video "178e801340f79249dbb2b34b3e64eda4"     

#define Chastise_video "29eebc0d0804260f934575ceaedc50b1"

#define CatsPlayFound_video "5a9d9f72264522abc51300f9e772b136"
#define Pounce_video "17320773bbdcd9303f69d4dc4add38e6"        

#define CatsPlay1_video "001c0e74e770ec34c053879be10d1a7e"    // E
#define CatsPlay2_video "6216cf1923de998474b25afeda659448"    // NE
#define CatsPlay3_video "d5794454c11bca1f990e6a817e9b3b1e"    // N
#define CatsPlay4_video "6f119daa4433a28d44e19f37c4d9133f"    // NW
#define CatsPlay5_video "22ccc18e5b0c467fa209af54940b6773"    // W
#define CatsPlay6_video "98d5dacbc40ef6b1b8cfec4e5c6d230c"    // SW
#define CatsPlay7_video "bb0f5dbf32a9000787626cf71057fa26"    // S
#define CatsPlay8_video "6f19334918db04ddf84050696485c0d9"    // SE

#define EyesFollowFinger_video "f99c9b5031e6102ef45fbdf71cb09134"

#define MysticCat_video "fb6001b81b161fc556371a5bb34c17c9"

#define ParallaxCat_video "7f4f62c859d8a8638cb9126c23775372"

#define Sleep_video "72ec4d3eb423bd80ae8fd0c3bfd44143"

#define Shaken_video "89d7ee32f925de8a719726fbcacc622c"

#define Swipe_video "3d64a7500f82e9e3aa022318d17253ad"

#define EasterEggTerri_video "00e700137430e520ae75fb2b545eed31"

#define EasterEggFrank_video "a847ec268d727e816711caa1cb7e272c"

#define ShowTime_video "0c694842005c6e03d2abe845e530815e"

#define SetTime_video "c0fad0b76200936d73785cfc220d22cd"

#define Getting_Sleepy_video "69e2f5a6b7bfffab4a787be11f57fbcd"

#define videoname_end ".mjpeg"

// WatchFace_Main

#define wfMainBackground "Face_Main_background.jpg"
#define wfMainBattery "Battery_"   
#define wfMainBattery2 ".png"

#define wfMainHours "Hour"      
#define wfMainHours2 ".png"
#define wfMainMinutes "Minute"  
#define wfMainMinutes2 ".png"
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

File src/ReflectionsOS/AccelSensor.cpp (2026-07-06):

/*
  Reflections is a hardware and software platform for building entertaining mobile experiences.

  Repository is at https://github.com/frankcohen/ReflectionsOS
  Includes board wiring directions, server side components, examples, support

  Licensed under GPL v3 Open Source Software
  (c) Frank Cohen, All rights reserved. fcohen@starlingwatch.com

  This module performs real-time detection of single and double tap gestures
  using the LIS3DH accelerometer.

  (Header omitted for brevity - unchanged from your original.)
*/

#include "AccelSensor.h"

#include "driver/rtc_io.h"

// -------------------------------
// Tap-to-abort tuning (runtime)
// -------------------------------
// Runtime click engine tuning (awake mode)
static const uint8_t RUNTIME_CLICK_THRESHOLD = 25; // raise vs 20 to reduce sensitivity

// At 400 Hz: 1 count = 2.5 ms
static const uint8_t RUNTIME_TIME_LIMIT   = 10; // 25 ms
static const uint8_t RUNTIME_TIME_LATENCY = 10; // 90 ms dead-time (ringing suppression)
static const uint8_t RUNTIME_TIME_WINDOW  = 200; // 200 ms (keep tight)

// Stillness gate (m/s^2). Lower = stricter stillness requirement.
static const float STILLNESS_DEV_MAX = 0.75f;

// Magnitude EMA smoothing
static const float MAG_EMA_ALPHA     = 0.08f;
static const float MAG_DEV_EMA_ALPHA = 0.12f;

// Shortest signed angular delta between a and b (degrees), result in [-180, +180]
static inline float shortestAngleDelta(float a_deg, float b_deg) {
  float d = a_deg - b_deg;
  while (d > 180.0f) d -= 360.0f;
  while (d < -180.0f) d += 360.0f;
  return d;
}

// Compute the "twist angle" in degrees based on selected axis mode.
// Mode 0: roll-like angle = atan2(Y, Z)
// Mode 1: alternative roll = atan2(X, Z) (often better if the board is rotated)
static inline float computeTwistAngleDeg(const sensors_event_t& e) {
#if TWIST_AXIS_MODE == 1
  return (180.0f / PI) * atan2f(e.acceleration.x, e.acceleration.z);
#else
  return (180.0f / PI) * atan2f(e.acceleration.y, e.acceleration.z);
#endif
}

// ——— register names from Adafruit_LIS3DH.h ———
//  INT1CFG: enable X/Y/Z high-event interrupts on INT1
//  INT1THS: threshold
//  INT1DUR: duration
//  CTRL_REG5: interrupt latch enable
// ————————————————————————————————

// raw write to any LIS3DH register over I²C
static void write8(uint8_t reg, uint8_t value) {
  Wire.beginTransmission(ACCEL_I2C_ADDR);
  Wire.write(reg);
  Wire.write(value);
  Wire.endTransmission();
}

AccelSensor::AccelSensor() {}

void AccelSensor::configureRuntimeTapProfile()
{
  lis.setDataRate(LIS3DH_DATARATE_400_HZ);
  lis.setRange(LIS3DH_RANGE_8_G);

  // Enable DOUBLE-click detection at runtime (not single)
  lis.setClick(2, RUNTIME_CLICK_THRESHOLD, RUNTIME_TIME_LIMIT, RUNTIME_TIME_LATENCY, RUNTIME_TIME_WINDOW);
  write8(LIS3DH_REG_CLICKCFG, 0x3F);   // XYZ single+double (wide-open)

  // Route click interrupt to INT1
  write8(LIS3DH_REG_CTRL3, 0x80);

  lis.getClick(); // clear pending
}

void AccelSensor::configureWakeTapProfile()
{
  configureSensorWakeOnMotion();
}

void AccelSensor::updateStillnessEstimate(float mag)
{
  if (_magEma == 0.0f) _magEma = mag;
  _magEma += MAG_EMA_ALPHA * (mag - _magEma);

  float dev = fabsf(mag - _magEma);
  _magDevEma += MAG_DEV_EMA_ALPHA * (dev - _magDevEma);
}

bool AccelSensor::getSingleTapAbortCandidateNoClear()
{
  if (!_pendingSingle) return false;
  if (!_lastClickHadZ) return false;
  if (_magDevEma > STILLNESS_DEV_MAX) return false;
  return true;
}

bool AccelSensor::getSingleTapAbortCandidate()
{
  bool ok = getSingleTapAbortCandidateNoClear();
  if (ok) _pendingSingle = false; // consume
  return ok;
}

void AccelSensor::begin() {
  started = false;
  runflag = false;

  lis = Adafruit_LIS3DH();

  if (!lis.begin(accelAddress)) {
    Serial.println(F("Accelerometer did not start, stopping"));
    video.stopOnError("Accel", "did not", "start", " ", " ");
  }

  magtime = millis();
  last = millis();

  started = false;
  runflag = false;

  firstpart = false;
  firstClickTime = millis();
  minClickTime = millis();
  waittime = millis();
  _pendingSingle = false;
  _pendingDouble = false;
  _twistIgnoreUntilMs = 0;

  // New gating state
  _lastClickHadZ = false;
  _lastClickMs = 0;
  _magEma = 0.0f;
  _magDevEma = 0.0f;

  shakentime = millis();
  shakentime2 = millis();
  shakencount = 0;

  // IMPORTANT: while awake, use runtime profile.
  // Switch to wake profile ONLY right before deep sleep.
  configureRuntimeTapProfile();

  started = true;

  // ---- Initialize wrist twist state ----
  _rollEma = 0.0f;
  _lastRoll = 0.0f;
  _twistAccumDeg = 0.0f;
  _twistStartMs = millis();
  _twistLastMs = millis();
  _twistCooldownUntil = 0;
  _twistArmed = false;
  _twistPending = false;
  _twistDbgLastMs = 0;

  _ax = _ay = _az = 0.0f;
  _twistDirHits = 0;
  _twistDirLast = 0;
  _setTimeTwistState = SETTIME_TWIST_IDLE;
  _setTimeTwistIdleAngleDeg = 0.0f;
  _setTimeTwistStartAngleDeg = 0.0f;
  _setTimeTwistLastAngleDeg = 0.0f;
  _setTimeTwistForwardDir = 0;
  _setTimeTwistReachedDigital = false;
  _setTimeTwistReturnConfirmed = false;
  _setTimeTwistStartedAt = 0;
  _setTimeTwistHoldStartedAt = 0;
  _setTimeTwistCooldownUntil = 0;
  _setTimeTwistForwardMoveStartedAt = 0;
  _setTimeTwistReturnMoveStartedAt = 0;
  _setTimeTwistStoppedStartedAt = 0;
  _setTimeTwistDigitalTimePending = false;
  _setTimeTwistSetTimePending = false;
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

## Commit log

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2021-01-17 Learning more about Adruino_GFX library
    Adding an edited/corrected Stream_Video sketch
    [MjpegClass.h, ReflectionsOS.ino, tjpgdClass.cpp]
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2021-03-02 Update Seuss Display Prototype wiring.pdf
    Fixed the 3 buttons circuit and cleaned-up page 2
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2021-04-24 Create File Transfer using Bluetooth Classic, ESP32, SD SPI, and Android IDE arduino.pdf
    Developer journal article on how the file transfer gateway works, architecture, and implementation issues. Published on Reddit at https://github.com/frankcohen/ReflectionsOS/blob/main/Gateway/Show%20Runner%20Service.pdf
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2021-08-11 Fixed a mistake in the DemoReel3.json
    An extra } character in the events section. Removed it and rebuilt the DemoReel3.tar file
    [ESP32FileTransfer.ino]
2021-09-02 Audio sequencing errors (Not moving moving beyond startup) -- Solved
    [Reflections.h, ShowRunner.ino]
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2022-01-24 Updated breadboard and GPIO pins
    Changing to USB C and adding a uart removes the need for 'FTDI pads for pogo pins to flash the ESP32 bootloader'. And photos of a reworked breadboard (v2)
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2022-02-09 Work-in-progress show runner
    Builds but does not work consistently, gives panic reboot on SPI communication.
    [13StoryRunner.ino, Utils.h, config.h]
2022-02-09 Streaming video working again
    Seems that my code was overdriving the TFT display and causing an SPI crash. This adds a delay that solves the crash - though I don't know why. Next-up I'm working on the gesture sensor.
    [13StoryRunner.ino]
2022-02-17 Sox Gerber files (Avinadad) and Gestures experiment
    First prototype of Sox board
    Gestures experiment using VL53L5CX TOF sensor
    [BOM.xlsx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]
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2022-03-22 Update wiring guide and notes
    Wiring guide, notes, and gesture rotation model
    [Rotation Model.ods]
2022-04-27 Updating wiring guide for main boarrd
    Main board is now in hand, about 3-4 reworks needed.
    [Rotation Model.ods]
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2022-07-08 Adding Hoober Gerbers
    Hoober is the second revision to the main board.
    [Drill_PTH_Through.DRL, Gerber_BoardOutlineLayer.GKO, Gerber_BottomLayer.GBL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]
2022-07-08 Updating Gerber files for Hoober board
    Hoober board is rev 2 of the main board - after Rev 1 codenamed Sox.
    [Drill_PTH_Through.DRL, Gerber_BoardOutlineLayer.GKO, Gerber_BottomLayer.GBL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]
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2022-07-12 Create BOM_Hoober Board_2022-07-11.csv
    Adding BOM to Avinadad Hoober project
    [BOM_Hoober Board_2022-07-11.csv]
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2022-07-15 Updated ThingTwo requirements
    ThingTwo is the 3rd revision to the main board. Also, added photos of Hoober
    [BOM Hoober Avinadad.xlsx]
2022-07-18 Documenting problem with nginx
    ESP32 requires SSL TLS 1.2, does not work with 1.3. This shows how to set nginx on the server side to TLS 1.2.
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2022-08-21 Adding Horton
    Horton is the 4th revision board, it succeeds ThingTwo, Sox, and Hoober
    [BOM_ThingTwo_Digikey_latest.xlsx]
2023-01-25 Starting Horton board project
    Horton is the revision 4 of the Reflections main board. Horton fixes problems in the ThingTwo board and gets closer to manufacturing.
    [BOM_ThingTwo Avinadad_2023-01-24.csv, BOM_ThingTwo_Digikey_latest.xlsx]
2023-01-25 Added Gerber files for ThingTwo
    Gerber files for the ThingTwo main board and gesture sensor daughter board
    [Drill_PTH_Through.DRL, Drill_PTH_Through_Via.DRL, Gerber_BoardOutlineLayer.GKO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]
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2023-02-07 Horton project
    Horton is the follow-up to ThingTwo. Check-in includes Gerber files, software to interact with devices, software support libraries, and project notes.
    [Drill_PTH_Through.DRL, Drill_PTH_Through_Via.DRL, Gerber_BoardOutlineLayer.GKO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]
2023-02-19 Horton board assembly and brighter display evaluation
    Horton board assembly. And evaluating displays that can be seen in daylight (above 700 NITS)
    [PickAndPlace_Horton Main Board_2023-02-15.csv]
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2023-03-04 Fixed problem sourcing U4 for Horton
    JLCPCB confirms their system is not properly showing inventory
    for U4 MD7671A33PA1. They cancelled the order for that part:
    https://jlcpcb.com/partdetail/998876-MD7671A33PA1/C920513
    We found a component with the same footprint and function
    at Mouser on https://bit.ly/3II03Mk. This is a Linear Regulator (LDO)
    that puts out 3.3 volts from either USB 5V or battery 3.7 V input
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2023-03-25 Turns NAND into a USB flash drive
    Example code to use ESP32 USBMSC utility to have a NAND storage chip appear as a mounted flash drive on a PC or Mac. Addresses this ESP32 issue https://github.com/espressif/arduino-esp32/issues/7106 and documented at https://www.reddit.com/r/arduino/comments/w4o8wn/esb32s3_nand_sd_storage_usb_msc_arduino_that/
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2023-06-26 CindyLou latest mainboard
    CindyLou is the latest version of the main board. CindyLou lets me put everything into a wrist watch case and actually wear it on my wrist! Plus the software to drive experiences (codename CalliopeOp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
    [Drill_PTH_Through.DRL, Drill_PTH_Through_Via.DRL, Gerber_BoardOutlineLayer.GKO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]
2023-07-12 Adding CindyLou board, 5th rev, and RHD experiment
    Range Heading Distance (RHD) experiment uses 2 boards, BLE, and compasses to determine when the boards are heading towards each other, and the distance between them.
    [Angle model.ods, BOM_CindyLou Daughter Board_2023-07-07.csv, BOM_CindyLou Main Board_2023-07-07.csv]
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2023-08-08 Adds BlueFish board version
    BlueFish is the 6th revision of the Reflections main board.
    It is the successor to CindyLou, Horton, ThingTwo, Hoober, Knox and Sox.
    BlueFish replaces the LDO power circuit and the GPS unit.
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2023-09-19 CindyLou and RedFish updates
    Gerber files added, Recorder 4 updates, beginning of Logger document
    [BOM_RedFish 2 Main Board_2023-08-25.csv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]
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2023-11-04 Updated Blue Fish Gerber files
    Fixes problem with the board slot width of the USB component
    [BOM_Blue Fish Main Board_2023-11-04.csv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]
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2024-01-14 Cat In Hat board and code
    [BOM_Cat In Hat Main Board_2023-12-15.csv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]
2024-02-14 Preparing for Yertle board revision
    Previous board added U9 (LTC2954CTS8-1#TRPBF) to provide press-and-hold power on/off. U9 interferes with the ESP32-S3 EN operation. The processor will not go into download/bootloader mode. Yertle removes U9.
2024-03-18 Dynamic Time Warping (DTW) experiment
    This is an experiment to see if a computing device can make sense of gestures made with a wrist. My implementation of [@CieloStrive](https://github.com/CieloStrive) experiment on [gesture cognition using Dynamic Time Warping (DTW)](https://github.com/CieloStrive/GESTURE-RECOGNITION-DYNAMIC-TIME-WARPING) influenced this experiment.
    [config.h]
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2024-03-19 Yertle Gerbers and schematic
    Yertle is the 9th revision of the Reflections main board.
    [BOM_Yertle_2024-03-19.csv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]
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2024-03-29 Wrist gestures completed
    Fully functional wrist gestures using the accelerometer. Likely a bunch of bugs still.
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2024-04-05 Logger bugs fixed
    Logger no longer emits %FF to the server
    Logger shows log uploaded count on log delete message
    Still does not handle SD library flakiness gracefully. After approximately 10 minutes of use, the SD library stops interacting with the NAND/SD chip, and see this in Serial monitor and log files:
    sendToServer:
    Error, empty message
    Not logging, mylog is not open
    repeated
    [Hardware.cpp]
2024-04-05 Searching for fix to SD flakiness
    Changed the way I initialize the SD/NAND unit. Gives error:
    "[ 25055][D][HTTPClient.cpp:393] disconnect(): tcp keep open for reuse
    Info, Just me logging
    [ 25557][W][sd_diskio.cpp:104] sdWait(): Wait Failed
    [ 25557][E][sd_diskio.cpp:126] sdSelectCard(): Select Failed
    [ 26058][W][sd_diskio.cpp:104] sdWait(): Wait Failed
    [ 26058][E][sd_diskio.cpp:126] sdSelectCard(): Select Failed
    [ 26059][E][sd_diskio.cpp:624] ff_sd_status(): Check status failed
    [ 26559][W][sd_diskio.cpp:104] sdWait(): Wait Failed
    [ 26559][E][sd_diskio.cpp:126] sdSelectCard(): Select Failed
    Starting new log file, forcecount = 1
    [ 27060][W][sd_diskio.cpp:104] sdWait(): Wait Failed
    [ 27060][E][s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
    [Hardware.cpp]
2024-04-08 Debugging Nand Logger crash
    Lowering the SPI bus transfer speed, simplified the logger. Still has the crash where the Nand stops responding after 4-5 log entries. Power cycle the board and the Nand works again normally. I disabled the Logger's loop and logging works normally, no crash. I suspect the HTTP client is causing the crash, perhaps the Wifi SPI and SS pins are colliding with the Nand SPI?
    [Hardware.cpp]
2024-04-11 More fixes to Nand problems with Logger
    Nand is easily overloaded with requests. Read a bunch of characters from a text file, close, and delete the file and the Nand stops responding. Add a 2 second delay and all is well. Still have more problems with the Nand to solve.
    [Hardware.cpp, config.h]
2024-05-16 Marvin board notes and Gerbers
    Marvin is the 10th revision of the Reflections main board. It is the successor to Yertle, Cat In Hat, BlueFish, RedFish, CindyLou, Horton, ThingTwo, Hoober, Knox and Sox. 1. Remove U9, 2. Use https:/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
    [BOM_Marvin_2024-05-16.csv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]
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2024-06-18 Vlad version of the logic board
    Vlad is the 10th version of the board. It connects the LIS3DH accelerometer INT 1 an INT 2 pins to GPIO 14 and 13 to wake the ESP32-S3 from deep sleep upon movement.
    [Drill_PTH_Through.DRL, Drill_PTH_Through_Via.DRL, Gerber_BoardOutlineLayer.GKO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]
2024-06-19 Fixed bug using GPIO 14 as an RTC pin
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2024-06-25 Experiences abstract base class docs
    Each experience has a startup, run, and teardown method. This documents the abstract base class Experience to implement each experience. See the Inveigle.cpp for an experience runner/controller.
    [BOM_Vlad_2024-06-24.csv]
2024-06-30 Fixed inveigle bugs and removing logging
    I also removed the ~Inveigle deconstructor, same for Experience_SetTime.h. This probably should be added back, to solve future and yet unknown memory leaks.
    [Hardware.cpp]
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2024-07-19 Getting ready for D23
    We've decided to show off the wrist watch at Disney D23 fan convention August 9-11, 2024. The next few weeks of commits are in support of the demonstration. We have these features planned:
    1) Awake and deep sleep
    2) Sending vibrations to other watches nearby - gestures (accel or TOF) and BLE communication
    3) Mystic watch - gesture + answer text animation
    4) Extra credit - Parallax cat or follow eyes - TOF follow
    5) Extra credit - Set and Show Time
    This commit changes the TOF sensor to recognize gestures from finger movements over the watch. It refines the Experience/Inveigle service. And enhances the GPS and BLE support.
    [Battery.cpp, Battery.h, Hardware.cpp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]
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2024-08-06 CatsPlay Experience implemented
    Removed NimBLE-Arduino as it is no longer going to be supported on ESP32 CPUs. See https://github.com/h2zero/NimBLE-Arduino/issues/685. Implemented BLE device-to-device communication using JSON encoded data. Later I will put the message handling code into BLEMessaging.cpp and .h. Inveigle starts a CatsPlay experience based on RSSI distance values from BLE.cpp. BLE now runs a server and client on the device - same for a nearby device. Inveigle uses BLE to see if it received a Pounce from another cat. CatsPlay experience SetUp determines the heading to the other device and plays 1 of 8 videos where the cat looks to the other cat. Run will let the user make a T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
    [config.h]
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2024-10-30 Adding VladPlus board details
    11th revision, replaces U4 with a higher efficiency power converter. The old one heated up when recharging a battery.
    [BOM_Vladplus_2024-10-29.csv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]
2024-11-09 Custom partition scheme for Arduino IDE 2.x
    I created a custom ESP32 partition scheme to maximize available memory with 8 MB overall, 2 application spaces, OTA, and little or no SPIFFS file storage.
    [reflections-input.csv, reflections.csv]
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2024-11-13 Watchface animation partial and partition tables
    Work in progress update, compiles and gives partial watch face. More coming this week. Removed WifiManager library as it is not compatible with ESP32 3.0.7, core panic.
    [partitions.csv]
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2024-11-26 Accelerometer now using Adafruit library
    Refactored Accelerometer to AccelSensor.cpp and .h. Swapped Sparkfun for Adafruit library. Detects single and double clicks. Temporarily removed gesture training and sensing, will add back later.
    [AccelSensor.cpp, AccelSensor.h, ReflectionsOS.ino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]
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2025-01-18 AccelerometerLab for LIS3DH
    LIS3DH is an inexpensive 3 Axis accelerometer component. It senses movement
    and acceleration from gravity. I use it to sense gestures in the
    Reflections open-source mobile entertainment platform for visual controls
    and to wake the ESP32-S3 processor from deep sleep. It senses movement,
    taps, clicks, shaking, and acceleration. Many libraries exist and
    generative AI such as ChatGPT is familiar and generates code for
    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
    [partitions.csv]
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2025-01-25 Uses FABS now
    ABS() doesn't work for Float values
    [AccelerometerLab.ino]
2025-01-28 Fixing bugs in Main watch face
    Almost done with the Main Watch Face. Major changes to the AccelSensor gesture/tap sensing. Re-implemented the single/double tap sensing.
    [AccelSensor.cpp, AccelSensor.h, AccelerometerLab.ino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]
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2025-03-17 Board Initialization Utility BIU
    BIU installs media files for new boards. Next up is BLE cats play experience.
    [partitions.csv]
2025-03-19 Mac address works, BLE started again
    Shows the MAC address on start-up. New BLEsupport code using NimBLE library. Not working yet.
    [ReflectionsOS.ino]
2025-03-25 Rebuilding BLE support, work in progress
    I'm rewriting the NimBLE code in BLEsupport.cpp. This is a work in progress commit. It doesn't work fully, and it compiles. Client connections are not working yet.
    [ReflectionsOS.ino, config.h]
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2025-03-29 Bug fixes in file downloading
    [config.h]
2025-03-31 Bug fixes to server replication
    Next up is finishing the Cats Play experience
    [ReflectionsOS.ino, config.h]
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2025-04-05 Compass readings improved
    MMC5603NJ magnetometer and temperature sensor should be very easy, it's not. This is the best code yet to deal with it's finickiness. And there's still a lot of extra coding needed. For example, automatic reset and SET operations.
2025-04-10 Fixing bugs from the merge
    [config.h]
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2025-04-15 Solves half of the crashing problem
    Second part is to revert back to JPEGDEC and to remove using bufferCanvas for drawing portions of the screen, we will see
    [partitions.csv]
2025-04-17 Back to building
    And it doesn't do much right now... working on it
    [partitions.csv]
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2025-04-18 Removed Arduino_Canvas use
    Arduino_Canvas requires 115,200 bytes of buffer space on the heap. I didn't find a way to get the memory to work with everything else. Now the main watch face draws to the display directly, no buffering. I still need to correct the drawing and jpg/png images in WatchFaceMain to keep the images from flickering. Coming next.
    [ReflectionsOS.ino]
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2025-04-28 Refactoring experience dispatcher
    The original way had the Reflections.ino calling the .loop methods in the services (Accel, TOF, ExperienceService, others) and they handled dispatching the main watch face and experiences. That caused linker problems where service objects needed to have access to each other. Refactored to putting the dispatcher into the .ino. Partially working, and compiles.
    [AccelSensor.cpp, AccelSensor.h, Hardware.cpp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]
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2025-06-22 Fixed step counter, adjusting for taps
    [AccelSensor.cpp, AccelSensor.h, WatchFaceMain.cpp]
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2025-06-25 RTC fixed, sleep vs sleepy, battery fixed
    Real Time Clock now stores the current time in NVS, on restart it first tries to get GPS time, then falls back to loading the time from NVS. After 6 minutes of no use the cat gets sleepy and stays on. Battery code much improved.
    [AccelSensor.cpp, Battery.cpp, Battery.h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]
2025-06-25 RTC and font fixes
    [WatchFaceMain.cpp]
2025-06-26 Fixed the Parallax logic
    [ReflectionsOS.ino, WatchFaceMain.cpp]
2025-06-27 Fixed RTC problem not reading time on wake
    Added "dots" startup animation, adjusted sleep gesture params, sleep gesture now overrides running experiences
    [Battery.cpp, Battery.h, ReflectionsOS.ino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]
2025-06-27 Fixes RTC year problem
    [AccelSensor.h, ReflectionsOS.ino, WatchFaceMain.cpp]
2025-07-24 Bug fixes and new features
    Fixed accelerometer gesture detection, same for TOF gestures, battery level detection, experiences overridden with single tap, low battery message on boot
    [AccelSensor.cpp, AccelSensor.h, Battery.cpp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]
2025-07-28 Fixed real time clock settings
    Added ESP32Time library
    [AccelSensor.cpp, AccelSensor.h, Hardware.cpp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]
2025-07-31 PNGdec branch to fix incompatibility with NIMble
    [ReflectionsOS.ino, config.h]
2025-08-07 Finished CatsPlay experience
    BLE messaging between devices let two devices play with each other. Uses a modified PNGdec library, find the issue at https://github.com/bitbank2/PNGdec/issues/36
    [ReflectionsOS.ino, config.h]
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2025-08-12 Sand branch
    [partitions.csv]
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2025-08-14 Sand experience done
    This was an experiment with ChatGPT 5, just released this week. I wanted to see grains of sand/bubbles/fireflies that drift, flock a bit, and fall with tilt.
    Here is the prompt I used: Create a complete new experience for my ReflectionsOS project named Experience_Fireflies.
    Requirements:
    Provide full .h and .cpp files (drop-in).
    Inherit from the Experience base class (same lifecycle as Experience_Awake/Experience_Sand): implement init(), setup(), run(), teardown().
    Duration: In run(), execute for a random time between 30–60 seconds, then call setRunComplete(true); in teardown(), finish promptly and call setTeardownComplete(true).
    The display is 240×240 and round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
    [AccelSensor.cpp]
2025-08-14 Remove src/ReflectionsOSSand (consolidated into src/ReflectionsOS)
    [partitions.csv]
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2025-10-17 JoJo main board
    Added the 12th iteration of the main board. This fixes a problem where the GPS module was inconsistent at acquiring satellites.
    [BOM_JoJo_2025-10-17.csv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]
2025-12-20 Updating Jojo board docs
    and preparing for manufacturing, final fixes.
    [ReflectionsOS.ino]
2025-12-20 Removing secrets.h
    Dumb mistake for it to be there in the first place.
    [ReflectionsOS.ino]
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2025-12-20 WatchFaceMain UX changes
    Twist to see the digital time panel. Then double click to set the time. I still have bugs to fix.
    [AccelSensor.cpp, AccelSensor.h, WatchFaceMain.cpp]
2026-01-06 Replication memory and SSL issues fixed
    [Hardware.cpp, ReflectionsOS.ino, config.h]
2026-01-06 Adding dev source repository
    ReflectionsOS - is the stable production version. ReflectionsOSdev - is the experimental version.
    [partitions.csv]
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2026-01-14 Updates a bunch of bugs and adjustments
    [AccelSensor.cpp, AccelSensor.h, Battery.cpp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]
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2026-01-17 Fixed Battery Interruptus problem
    Accelerometer interrupt lines are missing pull-up resistors. Each move to sleep gets woken up. Emptying battery quickly, even while trying to sleep.
    [AccelSensor.cpp, Battery.cpp, Battery.h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]
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2026-01-18 Fixing the clock
    Checks for valid RTC clock on book, uses NFS stored clock value if valid, saves to NFS on sleep and every 2 minutes. Initially sets time to 12:00. No more --:-- display.
    [Battery.cpp, Battery.h, ReflectionsOS.ino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]
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2026-06-14 Set Time updated
    Long twist gesture gets you into Setting Time mode. Twist and wait for 2-3 seconds, till you feel a buzz. Set the hours with tilt left-right, then countdown timer into setting the minutes.
    [ReflectionsOS.ino, WatchFaceMain.cpp, config.h]
2026-06-25 Battery drain problem fix
    [flash_log.csv]
2026-06-25 Fixed Deep Sleep/Shipping Mode battery drain
    [Hardware.cpp]
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2026-06-30 Fixed Set-time, sleep battery use, and TOF gestures
    Setting time is much easier, the Cat appears to run much longer since sleep and deep sleep take very little battery power, TOF gestures are easier to make.
    [AccelSensor.cpp, AccelSensor.h, ReflectionsOS.ino]
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
